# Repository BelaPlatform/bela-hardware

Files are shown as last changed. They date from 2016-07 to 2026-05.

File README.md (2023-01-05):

# Bela Hardware

This repo contains the editable hardware design files for Bela products, including Bela, Bela Mini, Bela accessories.

These PCB designs have been created in and are editable with Cadsoft EAGLE (https://cadsoft.io) and Kicad (http://kicad.org). 

## Licensing

The hardware designs in this repo are licensed under a Creative Commons Attribution Sharealike license, or [CC-BY-SA](http://creativecommons.org/licenses/by-sa/3.0/). This means you are free edit and use these designs, as long as you agree to supply credit and release your results under the same license. [Read about CC-BY-SA here](http://creativecommons.org/licenses/by-sa/3.0/).

If you want to create a commercial product using the Bela hardware designs and don't want to release it under the same license, you will need a commercial license. Drop us an email at info@bela.io to discuss your project, and we can suggest a commercial license to fit your project's scope and scale.

## Branding

The Bela logo is copyrighted, and is reserved for products made or licensed by the Bela team. If you want to include a Bela logo on your project, we've made a Made With Bela logo just for this. [See this page for details on logo use](https://belaplatform.github.io/bela_sample/src/#logos) and to download the Made With Bela logo.

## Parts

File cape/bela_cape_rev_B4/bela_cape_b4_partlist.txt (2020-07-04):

Partlist

Exported from bela_cape.brd at 09/12/2019 12:21

EAGLE Version 6.5.0 Copyright (c) 1988-2013 CadSoft

Assembly variant: 

Part     Value                   Package              Library             Position (inch)       Orientation

C1       0.1uF                   C0603                rcl                 (1.03 -1.71)          R0
C2       10uF                    0603-CAP             SparkFun-Passives   (0.53 -1.77)          R90
C3       10uF                    0603-CAP             SparkFun-Passives   (1.05 -1.59)          R0
C4       0.1uF                   C0603                rcl                 (1.05 -1.53)          R0
C5       0.1uF                   C0603                rcl                 (0.49 -1.4)           R0
C6       0.1uF                   C0603                rcl                 (0.49 -1.48)          R0
C7       0.1uF                   C0603                rcl                 (1.27 -1.32)          R90
C8       0.1uF                   C0603                rcl                 (0.125 -1.765)        R270
C9       0.1uF                   C0603                rcl                 (1.28 -1.9)           R90
C10      0.1uF                   C0603                rcl                 (0.445 -1.77)         R270
C11      0.1uF                   C0603                rcl                 (1.88 -1.28)          R180
C12      1uF                     C0603                rcl                 (1.88 -1.41)          R0
C14      47uF                    EIA3216              SparkFun-Capacitors (2.11 -1.005)         R180
C15      0.1uF                   C0603                rcl                 (2.11 -1.11)          R0
C16      47uf                    EIA3216              SparkFun-Capacitors (1.93 -2.27500209)    R180
C17      47uf                    EIA3216              SparkFun-Capacitors (1.93 -2.16136602)    R180
C20      0.1uf                   C0603                rcl                 (1.72 -2.44)          R0
C21      0.1uf                   C0603                rcl                 (1.72 -2.28)          R0
C22      0.1uf                   C0603                rcl                 (1.15 -2.35)          R180
C23      0.1uf                   C0603                rcl                 (1.15 -2.25)          R180
C24      10uf,10V                0603-CAP             SparkFun-Passives   (1.72 -2.53)          R180
C25      10uf,10V                0603-CAP             SparkFun-Passives   (1.72 -2.36)          R180
C26      10uf,10V                0603-CAP             SparkFun-Passives   (1.15 -2.43)          R0
C27      10uf,10V                0603-CAP             SparkFun-Passives   (1.15 -2.17)          R0
C28      1uF                     C0603                rcl                 (2.04452817 -2.58090391) R180
C29      1uF                     C0603                rcl                 (2.04271001 -2.43091191) R0
C30      47pF                    C0603                rcl                 (2.17589186 -2.58090404) R0
C31      47pF                    C0603                rcl                 (2.04368602 -2.50495792) R0
C32      1uf                     C0603                rcl                 (0.105 -2.53)         R180
C33      .01uf                   C0603                rcl                 (0.1 -2.235)          R180
C34      2.2uf                   C0603                rcl                 (0.005 -2.37)         R270
C35      0.1uF                   C0603                rcl                 (0.844 -1.845)        R0
C36      0.1uF                   C0603                rcl                 (2.005 -1.57)         R90
C38      1uF                     C0603                rcl                 (2.005 -1.985)        R90
C39      47uF                    EIA3216              SparkFun-Capacitors (2.195 -1.57)         R90
C40      0.1uF                   C0603                rcl                 (2.085 -1.57)         R270
D1       PGB0010603MR            0603                 CircuitCo           (2.22 -2.175)         R90
D2       PGB0010603MR            0603                 CircuitCo           (2.22 -2.305)         R270
D3       BAS70-04                SOT23                diode               (1.87799409 -2.54519993) R90
D4       BAS70-04                SOT23                diode               (1.87799409 -2.4088499) R90
FB1      FB                      0603                 SparkFun-Passives   (1.7 -2.15)           R180
FB2      FB                      0603                 SparkFun-Passives   (1.41 -2.5163659)     R180
FB3      FB                      0603                 SparkFun-Passives   (0.13 -2.05)          R270
FB4      FB                      0603                 SparkFun-Passives   (0.265 -2.415)        R90
IC1      ADD8704RU               TSSOP14              analog-devices      (1.12 -1.89)          R90
IC2      ADD8704RU               TSSOP14              analog-devices      (1.12 -1.32)          R90
IC3      AD5668                  TSSOP16-PW           custom              (0.27 -1.46)          R90
IC4      AD7699                  LFCSP20-LEADS        custom              (0.87 -1.57)          R180
IC5                              TSSOP14              SparkFun-DigitalIC  (0.28 -1.77)          R0
IC6      TLV320AIC3104           QFN-32               CircuitCo           (1.46 -2.34)          R270
IC7      V_REG_LDOSMD            SOT23-5              SparkFun-PowerIC    (0.105 -2.37)         R0
IC8      LM4876                  SO8                  custom              (2.11 -1.26)          R270
IC9      LM4876                  SO8                  custom              (2.11 -1.8)           R270
J1       22-23-2021              22-23-2021           con-molex           (0.425 -2.41)         R0
J2       22-23-2041              22-23-2041           con-molex           (0.88 -2.41)          R0
J3       22-23-2031              22-23-2031           con-molex           (2.42 -2.31)          R90
J4       22-23-2031              22-23-2031           con-molex           (2.42 -1.91)          R90
J5       22-23-2021              22-23-2021           con-molex           (2.42 -1.51)          R90
J6       22-23-2021              22-23-2021           con-molex           (2.42 -1.21)          R90
J7                               1X10                 pinhead             (1.54 -1.525)         R90
J8                               1X10                 pinhead             (0.39 -1.075)         R180
J9                               1X04                 SparkFun-Connectors (1.74 -1.675)         R270
J10                              1X04                 SparkFun-Connectors (1.84 -1.675)         R270
R1       0                       R0603                rcl                 (0.49 -1.64)          R0
R2       0                       R0603                rcl                 (0.07 -1.54)          R90
R3       DNI                     R0603                rcl                 (0.07 -1.42)          R270
R4       0                       R0603                rcl                 (0.74 -1.45)          R0
R5       DNI                     R0603                rcl                 (0.49 -1.56)          R180
R6       0                       R0603                rcl                 (1.40872281 -2.59002178) R180
R7       43k                     R0603                rcl                 (2.18 -1.41)          R180
R8       22k                     R0603                rcl                 (2.03 -1.41)          R180
R9       100                     R0603                rcl                 (0.05 -1.25)          R0
R10      22k                     R0603                rcl                 (1.88 -1.19)          R180
R11      15                      R0603                rcl                 (2.07 -2.305)         R90
R12      15                      R0603                rcl                 (2.07 -2.175)         R270
R13      22k                     R0603                rcl                 (2.085 -1.985)        R270
R14      43k                     R0603                rcl                 (2.17 -1.985)         R270
R15      3.3k                    R0603                rcl                 (2.14523991 -2.30340613) R270
R16      3.3k                    R0603                rcl                 (2.14524016 -2.17432788) R90
R17      220                     R0603                rcl                 (2.17614592 -2.50520386) R180
R18      220                     R0603                rcl                 (2.17614579 -2.43066622) R180
R21      2.2k                    R0603                rcl                 (0.85 -2.25)          R0
R22      2.2k                    R0603                rcl                 (0.98 -2.25)          R180
RN1      22                      0603-ARC             resistor-dil        (0.27 -1.97)          R0
RN2      22                      0603-ARC             resistor-dil        (0.72 -1.72)          R180
RN3      220                     0603-ARC             resistor-dil        (1.375 -1.79)         R270
RN4      220                     0603-ARC             resistor-dil        (1.37 -1.35)          R270
RN5      220                     0603-ARC             resistor-dil        (0.34 -1.26)          R0
RN6      220                     0603-ARC             resistor-dil        (0.19 -1.26)          R0
S1       SWITCH-MOMENTARY-2SMD-5 TACTILE_SWITCH_SMD-4 custom              (2.38315994 -2.55585212) R180
TP1                              1X01                 pinhead             (1.24 -1.575)         R0
TP2                              1X01                 pinhead             (1.56 -2.525)         R0
U$1      BEAGLEBONE_OUTLINE      BEAGLEBONE_SHIELD    adafruit            (-0.81 -0.7)          R270

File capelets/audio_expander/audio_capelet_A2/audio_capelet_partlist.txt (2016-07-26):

Partlist

Exported from audio_capelet_a1.brd at 24/05/2016 19:19

EAGLE Version 6.5.0 Copyright (c) 1988-2013 CadSoft

Assembly variant: 

Part     Value            Package      Library        Position (inch)       Orientation

C1       1uF              C0603        resistor       (0.96 0.4)            R180
C2       330pF            C0603        resistor       (1.16 0.43)           R0
C3       330pF            C0603        resistor       (1.26 0.52)           R270
C4       1uF              C0603        resistor       (1.17 0.92)           R0
C5       330pF            C0603        resistor       (0.97 0.86)           R180
C6       330pF            C0603        resistor       (0.88 1.02)           R0
C7       1uF              C0603        resistor       (1.52 0.51)           R180
C8       330pF            C0603        resistor       (1.66 0.37)           R270
C9       330pF            C0603        resistor       (1.79 0.51)           R270
C10      1uF              C0603        resistor       (1.68 1.1)            R0
C11      330pF            C0603        resistor       (1.52 1.16)           R180
C12      330pF            C0603        resistor       (1.43 1.02)           R0
C13      1uF              C0603        resistor       (1.73 0.46)           MR180
C14      330pF            C0603        resistor       (1.62 0.33)           MR270
C15      330pF            C0603        resistor       (1.49 0.49)           MR270
C16      1uF              C0603        resistor       (1.61 1.1)            MR0
C17      330pF            C0603        resistor       (1.72 1.26)           MR90
C18      300pF            C0603        resistor       (1.85 1.11)           MR90
C19      1uF              C0603        resistor       (0.71 0.38)           MR270
C20      330pF            C0603        resistor       (0.62 0.32)           MR270
C21      330pF            C0603        resistor       (0.5 0.42)            MR270
C22      1uF              C0603        resistor       (0.63 1.06)           MR90
C23      330pF            C0603        resistor       (0.7 1.07)            MR90
C24      330pF            C0603        resistor       (0.88 0.98)           MR0
C25      1uF              C0603        resistor       (0.84 1.63)           MR270
C26      220pF            C0603        resistor       (0.91 1.51)           MR90
C27      440pF            C0603        resistor       (0.93 1.61)           MR180
C28      220pF            C0603        resistor       (0.91 1.36)           MR270
C29      440pF            C0603        resistor       (0.93 1.27)           MR180
C30      1uF              C0603        resistor       (0.84 1.26)           MR90
C31      220pF            C0603        resistor       (0.44 1.37)           MR270
C32      440pF            C0603        resistor       (0.42 1.27)           MR0
C33      1uF              C0603        resistor       (0.51 1.26)           MR90
C34      220pF            C0603        resistor       (0.44 1.51)           MR90
C35      440pF            C0603        resistor       (0.42 1.6)            MR0
C36      1uF              C0603        resistor       (0.51 1.63)           MR270
C37      220pF            C0603        resistor       (0.43 1.52)           R90
C38      440pF            C0603        resistor       (0.42 1.61)           R180
C39      1uF              C0603        resistor       (0.51 1.63)           R270
C40      220pF            C0603        resistor       (0.43 1.37)           R270
C41      440pF            C0603        resistor       (0.42 1.27)           R180
C42      1uF              C0603        resistor       (0.51 1.25)           R90
C43      220pF            C0603        resistor       (0.91 1.36)           R270
C44      440pF            C0603        resistor       (0.93 1.26)           R0
C45      1uF              C0603        resistor       (0.84 1.26)           R90
C46      220pF            C0603        resistor       (0.91 1.51)           R90
C47      440pF            C0603        resistor       (0.92 1.6)            R0
C48      1uF              C0603        resistor       (0.83 1.63)           R270
C49      1uF              C0603        resistor       (0.55 0.59)           R180
C50      1uF              C0603        resistor       (0.64 0.48)           R90
C51      0.1uF            C0603        resistor       (0.85 0.67)           R270
C52      0.1uF            C0603        resistor       (1.41 0.79)           R270
C53      0.1uF            C0603        resistor       (1.48 0.79)           MR270
C54      0.1uF            C0603        resistor       (0.86 0.72)           MR270
C55      0.1uF            C0603        resistor       (0.67 1.63)           MR180
C56      0.1uF            C0603        resistor       (0.67 1.29)           R180
C57      0.1uF            C0603        resistor       (1.17 0.67)           R270
C58      0.1uF            C0603        resistor       (1.79 0.79)           R270
C59      0.1uF            C0603        resistor       (1.84 0.78)           MR270
C60      0.1uF            C0603        resistor       (0.49 0.74)           MR270
C61      0.1uF            C0603        resistor       (0.67 1.29)           MR180
C62      0.1uF            C0603        resistor       (0.67 1.61)           R180
IC1      ADD8704RU        TSSOP14      analog-devices (1.03 0.67)           R90
IC2      ADD8704RU        TSSOP14      analog-devices (1.59 0.79)           R90
IC3      ADD8704RU        TSSOP14      analog-devices (1.67 0.78)           MR90
IC4      ADD8704RU        TSSOP14      analog-devices (0.67 0.73)           MR90
IC5      ADD8704RU        TSSOP14      analog-devices (0.67 1.44)           MR0
IC6      ADD8704RU        TSSOP14      analog-devices (0.67 1.44)           R0
IC7      LP5907-1.8       SOT23-5      PDue           (0.54 0.48)           R180
J1       22-23-2031       22-23-2031   con-molex      (1.28 2.3)            R180
J2       22-23-2031       22-23-2031   con-molex      (1.68 2.3)            R180
J3       22-23-2031       22-23-2031   con-molex      (1.28 2.02)           R180
J4       22-23-2031       22-23-2031   con-molex      (1.68 2.02)           R180
J5       22-23-2031       22-23-2031   con-molex      (0.48 2.3)            R180
J6       22-23-2031       22-23-2031   con-molex      (0.88 2.3)            R180
J7       22-23-2031       22-23-2031   con-molex      (0.48 2.02)           R180
J8       22-23-2031       22-23-2031   con-molex      (0.88 2.02)           R180
J9       see BOM
J10      see BOM
J11	 see BOM
J12	 see BOM
R1       30k              R0603        resistor       (0.85 0.52)           R90
R2       3.3k             R0603        resistor       (1.15 1.63)           R270
R3       100k             R0603        resistor       (0.96 0.47)           R0
R4       27.4k            R0603        resistor       (1.06 0.33)           R90
R5       27.4k            R0603        resistor       (1.06 0.45)           R90
R6       16.2k            R0603        resistor       (1.18 0.52)           R90
R7       27.4k            R0603        resistor       (1.26 0.64)           R270
R8       30k              R0603        resistor       (1.17 0.82)           R270
R9       3.3k             R0603        resistor       (1.25 1.63)           R270
R10      100k             R0603        resistor       (1.07 0.9)            R270
R11      27.4k            R0603        resistor       (1 1.02)              R180
R12      27.4k            R0603        resistor       (0.97 0.96)           R0
R13      16.2k            R0603        resistor       (0.85 0.83)           R270
R14      27.4k            R0603        resistor       (0.83 0.93)           R180
R15      30k              R0603        resistor       (1.41 0.65)           R90
R16      3.3k             R0603        resistor       (1.35 1.63)           R270
R17      100k             R0603        resistor       (1.52 0.57)           R0
R18      27.4k            R0603        resistor       (1.59 0.28)           R0
R19      27.4k            R0603        resistor       (1.69 0.46)           R180
R20      16.2k            R0603        resistor       (1.69 0.53)           R0
R21      27.4k            R0603        resistor       (1.8 0.64)            R270
R22      30k              R0603        resistor       (1.79 0.93)           R270
R23      3.3k             R0603        resistor       (1.45 1.63)           R270
R24      100k             R0603        resistor       (1.68 1.04)           R180
R25      27.4k            R0603        resistor       (1.68 1.23)           R180
R26      27.4k            R0603        resistor       (1.52 1.09)           R0
R27      16.2k            R0603        resistor       (1.41 0.92)           R90
R28      27.4k            R0603        resistor       (1.41 1.13)           R270
R29      30k              R0603        resistor       (1.84 0.63)           MR90
R30      3.3k             R0603        resistor       (1.55 1.63)           R270
R31      100k             R0603        resistor       (1.73 0.53)           MR0
R32      27.4k            R0603        resistor       (1.73 0.29)           MR0
R33      27.4k            R0603        resistor       (1.57 0.42)           MR180
R34      16.2k            R0603        resistor       (1.57 0.53)           MR0
R35      27.4k            R0603        resistor       (1.48 0.62)           MR270
R36      30k              R0603        resistor       (1.48 0.93)           MR270
R37      3.3k             R0603        resistor       (1.65 1.63)           R270
R38      100k             R0603        resistor       (1.61 1.03)           MR180
R39      27.4k            R0603        resistor       (1.38 0.9)            MR0
R40      27.4k            R0603        resistor       (1.76 1.17)           MR0
R41      16.2k            R0603        resistor       (1.77 1.04)           MR180
R42      27.4k            R0603        resistor       (1.85 0.94)           MR90
R43      30k              R0603        resistor       (0.81 0.58)           MR90
R44      3.3k             R0603        resistor       (1.75 1.63)           R270
R45      100k             R0603        resistor       (0.74 0.47)           MR0
R46      27.4k            R0603        resistor       (0.88 0.51)           MR270
R47      27.4k            R0603        resistor       (0.59 0.42)           MR180
R48      16.2k            R0603        resistor       (0.59 0.49)           MR0
R49      27.4k            R0603        resistor       (0.5 0.54)            MR270
R50      30k              R0603        resistor       (0.49 0.86)           MR90
R51      3.3k             R0603        resistor       (1.85 1.63)           R270
R52      100k             R0603        resistor       (0.6 0.97)            MR180
R53      27.4k            R0603        resistor       (0.49 0.98)           MR90
R54      27.4k            R0603        resistor       (0.73 0.98)           MR0
R55      16.2k            R0603        resistor       (0.86 0.88)           MR270
R56      27.4k            R0603        resistor       (0.95 0.84)           MR0
R57      28.7k            R0603        resistor       (1.03 1.25)           MR90
R58      28.7k            R0603        resistor       (0.98 1.36)           MR90
R59      28.7k            R0603        resistor       (0.33 1.26)           MR90
R60      28.7k            R0603        resistor       (1.03 1.63)           MR270
R61      28.7k            R0603        resistor       (0.98 1.51)           MR270
R62      28.7k            R0603        resistor       (0.37 1.37)           MR90
R63      28.7k            R0603        resistor       (0.33 1.62)           MR270
R64      28.7k            R0603        resistor       (0.37 1.51)           MR270
R65      28.7k            R0603        resistor       (0.33 1.63)           R270
R66      28.7k            R0603        resistor       (0.36 1.52)           R270
R67      28.7k            R0603        resistor       (0.33 1.25)           R90
R68      28.7k            R0603        resistor       (0.36 1.36)           R90
R69      28.7k            R0603        resistor       (1.02 1.24)           R90
R70      28.7k            R0603        resistor       (0.98 1.35)           R90
R71      28.7k            R0603        resistor       (1.01 1.63)           R270
R72      28.7k            R0603        resistor       (0.98 1.52)           R270

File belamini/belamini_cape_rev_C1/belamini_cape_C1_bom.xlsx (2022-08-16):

Name | Quantity | Value | Side | Package | Description | Farnell # | Mouser # | Datasheet / Notes
 |  |  |  |  |  |  | 810-C1608X5R1A106M
C2, C18, C19, C20, C21 | 5 | 10uF | bottom | “0603” | Capacitor ceramic 0603 | 2309028
C3, C7, C14, C15, C22, C23, C24 | 7 | 1uF | bottom | “0603” | Capacitor ceramic 0603 | 2496916 | 77-VJ0603V105MXQPBC
C1, C4, C5, C6, C16, C17 | 6 | 0.1uF | bottom | “0603” | Capacitor ceramic 0603 | 1709957 | 80-C0603C104K5R
C12, C13 | 2 | 47pF | bottom | "0603" | Capacitor ceramic 0603 | 1759062 | 77-VJ0603A470JXACBC
C8, C9 | 2 | 47uF | bottom | "1206" | Capacitor electrolytic 1206 | 2353044 | 647-F930J476MAA
C10, C11 | 2 | 1.2nF NPO/C0G | bottom | "0603" | Capacitor ceramic 0603 NPO/C0G
D1, D2 | 2 | TE Connectivity PESD0603-240 | bottom | "0603" | ESD suppressor 24V |  | 650-PESD0603-240
D3, D4 | 2 | BAS70-04 | bottom | SOT23-3 | Dual Schottky diode |  | 863-BAS70-04LT1G |  | D3, D4
D5 | 1 | Lite-On LTST-C195TBJRKT | top | “0606” | blue/red LED |  | 859-LTST-C195TBJRKT | Important: check pinout of any generic equivalent part. Dot indicates the negative side (cathode).
FB1, FB2 | 4 | Ferrite bead | bottom | “0603” | Ferrite bead 0603 | 1781090 | 810-MPZ1608S121A
IC1, IC2 | 2 | TSV524 | bottom | QFN-16 | Quad op-amp |  | 511-TSV524IQ4T
IC3 | 1 | ADS8168IRHBT | bottom | QFN-32 | 16-bit ADC |  | 595-ADS8168IRHBT | Other parts in ADS816x series may also work.
IC4 | 1 | TLV320AIC3104 | bottom | QFN-32 | Audio codec |  | 595-TLV320C3104IRHBR
IC5 | 1 | MIC5317-1.8Y | bottom | SOT23-5 | 1.8V regulator |  | 998-MIC5317-1.8YM5TR
IC6 | 1 | USBLC6-2SC6 | bottom | SOT23-6 | ESD suppressor for USB |  | 511-USBLC6-2SC6
J1 | 1 | 10-pin socket | top | Through Hole | 10-pin socket |  | 992-10FX1-254MM
J2 | 1 | 3-pin header | top | Through Hole | 3-pin socket |  | 855-M20-7820346
J3, J4 | 2 | Molex 3-pin | top | Through Hole | 3-pin Molex KK series connector |  | 538-22-23-2031
J5 | 1 | Amphenol 87583-3010RPALF | top | Solder Pad | USB A socket, solder pad | 1314363 | 649-87583-3010RPALF
P1, P2 | 2 | 36-pin header | top | Through Hole | 2x18 2.54mm stacking headers (10mm male pins on bottom, female sockets on top). |  |  | Important: use 10mm pin length rather than 12.5mm used on previous Bela builds
R1, R2 | 2 | 15 ohm | bottom | “0603” | Resistor 0603
R3 | 1 | 100 ohm | bottom | “0603” | Resistor 0603
R4, R5 | 2 | 560 ohm | bottom | “0603” | Resistor 0603
R6, R7 | 2 | 3.3k ohm | bottom | “0603” | Resistor 0603
R8, R9 | 2 | 220 ohm | bottom | “0603” | Resistor 0603
R10, R11, R14 | 3 | 10k ohm | bottom | “0603” | Resistor 0603
R12, R13 | 2 | 49.9 ohm 1% | bottom | “0603” | Resistor 0603
RN1 | 1 | 22 ohm 4x network | bottom | “0603” | Resistor network 4x0603 | 2060086
S1 | 1 | C&K Components PTS810 SJG 250 SMTR LFS | top | SMD | Micro tactile switch |  | 611-PTS810SJG250SMTR
Total | 62
BOM rev. C1

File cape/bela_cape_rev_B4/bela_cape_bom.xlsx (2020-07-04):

Name | Quantity | Value | Package | Description | Farnell # | Mouser # | Datasheet / Notes
 |  |  |  |  |  | 810-C1608X5R1A106M
C2-C3, C24-C27, C34 | 7 | 10uF | “0603” | Capacitor ceramic 0603 | 2309028
C12, C13, C28, C29, C32, C38 | 6 | 1uF | “0603” | Capacitor ceramic 0603 | 1710292 | 77-VJ0603V105MXQPBC
C1, C4-C11, C15, C20-C23, C35-C36, C40 | 17 | 0.1uF | “0603” | Capacitor ceramic 0603 | 1709957 | 80-C0603C104K5R
C30-C31 | 2 | 47pF | "0603" | Capacitor ceramic 0603 |  | 77-VJ0603A470JXACBC
C14, C16, C17, C39 | 4 | 47uF | "1206" | Capacitor electrolytic 1206 |  | 647-F930J476MAA
C33 | DNI
D1, D2 | 2 | TE Connectivity PESD0603-240 | "0603" | ESD suppressor 24V |  | 650-PESD0603-240
D3, D4 | 2 | BAS70-04 | SOT23-3 | Dual Schottky diode |  | 863-BAS70-04LT1G
FB1-FB4 | 4 | Ferrite bead | “0603” | Ferrite bead 0603 | 1781090 | 810-MPZ1608S121A
IC1-IC2 | 2 | OPA4348AIPWR | TSSOP-14 | Quad rail-to-rail op amp | 2323319
IC3 | 1 | AD5668 | TSSOP-16 | 16-bit DAC |  | 584-AD5668ARUZ-2
IC4 | 1 | AD7699 | LFCSP-20 | 16-bit ADC |  | 584-AD7699BCPZ
IC5 | 1 | TXB0104PWR | TSSOP-14 | Level shifter | 1607891
IC6 | 1 | TLV320AIC3104 | QFN-32 | Audio codec |  | 595-TLV320C3104IRHBR
IC7 | 1 | MIC5317 | SOT23-5 | 1.8V regulator |  | 998-MIC5317-1.8YM5TR
IC8-IC9 | 2 | LM4876 | SOIC-8 | Audio power amp |  | 926-LM4876M/NOPB
J1 | DNI | Molex 2-pin | Through Hole | 2-pin Molex KK series connector |  | 538-22-23-2025
J3, J4 | 2 | Molex 3-pin | Through Hole | 3-pin Molex KK series connector |  | 538-22-23-2031
J2 | 1 | Molex 4-pin | Through Hole | 4-pin Molex KK series connector |  | 538-22-23-2041
J5-J6 | 1 | Molex 2-pin | Through Hole | 2-pin Molex KK series connector |  | 538-22-23-2025
J7-J8 | 2 | 10-pin socket | Through Hole | 10-pin socket |  | 992-10FX1-254MM
J9-J10 | DNI
P8, P9 | 2 | Adafruit 706 (or similar) | Through Hole | 46-pin long-lead female sockets for BeagleBone |  |  | http://www.adafruit.com/product/706
R1-R2, R4 | 3 | 0 ohm | “0603” | Resistor 0603
R3, R5 | DNI
R7, R14 | 2 | 43k ohm | “0603” | Resistor 0603
R8, R10, R13 | 3 | 22k ohm | “0603” | Resistor 0603
R6, R9 | 2 | 100 ohm | “0603” | Resistor 0603
R11, R12 | 2 | 15 ohm | “0603” | Resistor 0603
R15, R16 | 2 | 3.3k ohm | “0603” | Resistor 0603
R17, R18 | 2 | 220 ohm | “0603” | Resistor 0603
R21, R22 | 2 | 2.2k ohm | “0603” | Resistor 0603
RN1-RN2 | 2 | 22 ohm 4x network | “0603” | Resistor network 4x0603 | 2060086
RN3-RN6 | 4 | 220 ohm 4x network | "0603" | Resistor network 4x0603 | 2060094
SW1 | 1 | C&K Components PTS810 SJG 250 SMTR LFS | SMD | Micro tactile switch |  | 611-PTS810SJG250SMTR
Total | 86 |  |  | Bela rev. B3

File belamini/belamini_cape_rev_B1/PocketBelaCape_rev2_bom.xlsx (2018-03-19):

Name | Quantity | Value | Side | Package | Description | Farnell # | Mouser # | Datasheet / Notes
 |  |  |  |  |  |  | 810-C1608X5R1A106M
C2, C3, C18, C19 | 4 | 10uF | bottom | “0603” | Capacitor ceramic 0603 | 2309028
C7, C14, C15 | 3 | 1uF | bottom | “0603” | Capacitor ceramic 0603 | 2496916 | 77-VJ0603V105MXQPBC
C1, C4, C5, C6, C16, C17 | 6 | 0.1uF | bottom | “0603” | Capacitor ceramic 0603 | 1709957 | 80-C0603C104K5R
C10, C11, C12, C13 | 4 | 47pF | bottom | "0603" | Capacitor ceramic 0603 | 1759062 | 77-VJ0603A470JXACBC
C8, C9 | 2 | 47uF | bottom | "1206" | Capacitor electrolytic 1206 | 2353044 | 647-F930J476MAA
D1, D2, D3, D4 | 4 | TE Connectivity PESD0603-240 | bottom | "0603" | ESD suppressor 24V |  | 650-PESD0603-240
D5 | 1 | Lite-On LTST-C195TBJRKT | top | “0606” | blue/red LED |  | 859-LTST-C195TBJRKT
FB1, FB2 | 4 | Ferrite bead | bottom | “0603” | Ferrite bead 0603 | 1781090 | 810-MPZ1608S121A
IC1, IC2 | 2 | TSV524 | bottom | QFN-16 | Quad op-amp |  | 511-TSV524IQ4T
IC3 | 1 | AD7699 | bottom | LFCSP-20 | 16-bit ADC |  | 584-AD7699BCPZ
IC4 | 1 | TLV320AIC3104 | bottom | QFN-32 | Audio codec |  | 595-TLV320C3104IRHBR
IC5 | 1 | MIC5317 | bottom | SOT23-5 | 1.8V regulator |  | 998-MIC5317-1.8YM5TR
J1 | 1 | 10-pin socket | top | Through Hole | 10-pin socket |  | 992-10FX1-254MM
J2 | 1 | 3-pin header | top | Through Hole | 3-pin socket |  | 855-M20-7820346
J3, J4 | 2 | Molex 3-pin | top | Through Hole | 3-pin Molex KK series connector |  | 538-22-23-2031
J5 | 1 | Amphenol 87583-3010RPALF | top | Solder Pad | USB A socket, solder pad | 1314363 | 649-87583-3010RPALF
P1, P2 | 2 | 36-pin header | top | Through Hole | 2x18 2.54mm stacking headers (long male pins on bottom, female sockets on top) |  |  | similar to headers used on bela_cape but 36 pins rather than 46 pins
R1, R2 | 2 | 33 ohm | bottom | “0603” | Resistor 0603
R3 | 1 | 100 ohm | bottom | “0603” | Resistor 0603
R4, R5 | 2 | 560 ohm | bottom | “0603” | Resistor 0603
RN1 | 1 | 22 ohm 4x network | bottom | “0603” | Resistor network 4x0603 | 2060086
S1 | 1 | C&K Components PTS810 SJG 250 SMTR LFS | top | SMD | Micro tactile switch |  | 611-PTS810SJG250SMTR
Total | 47
BOM rev. B1

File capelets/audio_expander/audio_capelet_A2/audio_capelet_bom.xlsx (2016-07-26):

Name | Quantity | Value | Package | Description | Farnell # | Mouser # | Datasheet / Notes
C1, C4, C7, C10, C13, C16, C19, C22, C25, C30, C33, C36, C39, C42, C45, C48, C49, C50 | 18 | 1uF | “0603” | Capacitor ceramic 0603
C51-C62 | 12 | 0.1uF | “0603” | Capacitor ceramic 0603 | 1709957 | 80-C0603C104K5R
C2, C3, C5, C6, C8, C9, C11, C12, C14, C15, C17, C18, C20, C21, C23, C24 | 16 | 330pF | “0603” | Capacitor ceramic 0603, 5% or better tolerance
C26, C28, C31, C34, C37, C40, C43, C46 | 8 | 220pF | “0603” | Capacitor ceramic 0603, 5% or better tolerance
C27, C29, C32, C35, C38, C41, C44, C47 | 8 | 430pF | “0603” | Capacitor ceramic 0603, 5% or better tolerance
IC1-IC6 | 6 | OPA4348AIPWR | TSSOP-14 | Quad rail-to-rail op amp
IC7 | 1 | LP5907-MFX2.0 (or -MFX1.8) | SOT23-5 | Voltage regulator. 2.0V version is preferred but if it cannot be found, use LP5907-MFX1.8 |  | 595-LP5907MFX-1.8NPB
J1-J8 | 8 | Molex 3-pin | Through Hole | 3-pin Molex KK series connector |  | 538-22-23-2031
J9-J10 | 2 | 10-pin socket | Through Hole | 10-pin socket with long tail leads, similar to P8/P9
J11 | 1 | 8-pin socket | Through Hole | 8-pin socket — SAME HEIGHT AS J10 — does not need long leads, but if needed to match the height, use a long-lead socket and clip the leads off
J12 | 1 | 2x8 pin socket | Through Hole | 16-pin (2 row) female socket, 0.1” spacing
P8, P9 | 2 | Adafruit 706 (or similar) | Through Hole | 46-pin long-lead female sockets for BeagleBone |  |  | http://www.adafruit.com/product/706
R1, R8, R15, R22, R29, R36, R43, R50 | 8 | 30k ohm | “0603” | Resistor 0603 - 2% or better tolerance
R2, R9, R16, R23, R30, R37, R44, R51 | 8 | 3.3k ohm | “0603” | Resistor 0603 - 2% or better tolerance
R4, R5, R7, R11, R12, R14, R18, R19, R21, R25, R26, R28, R32, R33, R35, R39, R40, R42, R46, R47, R49, R53, R54, R56 | 24 | 27.4k ohm | “0603” | Resistor 0603 - 2% or better tolerance
R3, R10, R17, R24, R31, R38, R45, R52 | 8 | 100k ohm | “0603” | Resistor 0603
R6, R13, R20, R27, R34, R41, R48, R55 | 8 | 16.2k ohm | “0603” | Resistor 0603 - 2% or better tolerance
R57-R72 | 16 | 28.7k ohm | “0603” | Resistor 0603 - 2% or better tolerance
Total | 155 |  |  | Audio Expander Capelet rev. A2

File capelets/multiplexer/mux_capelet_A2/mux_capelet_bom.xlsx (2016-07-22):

Name | Quantity | Value | Package | Description | Farnell # | Mouser # | Datasheet / Notes
C1-C4 | 4 | 0.1uF | “0603” | Capacitor ceramic 0603 | 1709957 | 80-C0603C104K5R
IC1-IC8 | 8 | 74HCT4051 | TSSOP-16 | 8-channel multiplexer; note: any manufacturer is okay, but must be 74HCT type (not 74HC, CD4051 etc.) |  | 771-74HCT4051PW-T
J1, J2, J5, J6 | 4 | 34-pin IDC socket | Through Hole | 34-pin IDC socket vertical |  | 517-30334-6002
J3, J4 | 2 | 2-pin 0.1” header | Through Hole | 2-pin header
J7-J8 | 2 | 10-pin socket | Through Hole | 10-pin socket with long tail leads, similar to P8/P9
J9-J12 | 4 | 17-pin 0.1” header | Through Hole — BOTTOM side | 17-pin header installed facing downward
P8, P9 | 2 | Adafruit 706 (or similar) | Through Hole | 46-pin long-lead female sockets for BeagleBone |  |  | http://www.adafruit.com/product/706
R1-R2 | 2 | 22k ohm | “0603” | Resistor 0603
R3-R10 | DNI
R11 | 1 | 0 ohm | “0603” | Resistor 0603
Total | 29 |  |  | Multiplexer Capelet rev. A2

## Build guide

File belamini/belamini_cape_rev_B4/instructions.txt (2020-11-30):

Part: belamini_cape, revision B4
--------------------------------

Audio and sensor cape for PocketBeagle, featuring stereo audio codec, 8 channel 16-bit ADC and USB port. Designed for the Bela ultra-low-latency audio environment.

http://bela.io

(c) 2020 Augmented Instruments Ltd 
London, United Kingdom

info@bela.io

-------------------------

Suggested build specifications:

2 layers
1.6mm board thickness
black soldermask
white silkscreen, both sides
standard finish
7 mil minimum feature size
15 mil minimum drill
Tab routing / milling (for panelising)
Double-sided SMT assembly

-------------------------

Package contents:

*** EAGLE Design Files:

belamini_cape_B4.sch	EAGLE schematic
belamini_cape_B4.brd	EAGLE board

*** Gerbers (RS274X unless otherwise noted):

belamini_cape_B4.cmp	Component Side (top) copper
belamini_cape_B4.sol	Solder Side (bottom) copper
belamini_cape_B4.stc	Component side (top) stop mask
belamini_cape_B4.sts	Solder side (bottom) stop mask
belamini_cape_B4.plc	Component side (top) silkscreen
belamini_cape_B4.pls	Solder side (bottom) silkscreen
belamini_cape_B4.dim	Outline dimension
belamini_cape_B4.drd	NC Drill (Excellon format)
belamini_cape_B4.crc	Component side (top) paste
belamini_cape_B4.crs	Solder side (bottom) paste

*** Assembly files:

belamini_cape_B4_centroid.csv	XYRS placement data
belamini_cape_B4_bom.xls	Bill of materials

-------------------------

This design is available under the Creative Commons Attribution-ShareAlike 3.0 Unported License:

http://creativecommons.org/licenses/by-sa/3.0/

-------------------------

Revision History:

A1 			Internal build.
B1 			Internal build. Flip components to solder side.
B2 (March 2018)		First public release. Add ESD protection to USB port
			and ground USB ID bit. Changes to silkscreen.
B3 (May 2019)		Add R6 and R7 to reduce noise on audio output when
			codec is not active.
B4 (November 2020)	Change input protection circuitry (D3, D4, R8, R9).
			Change headphone output resistors R1, R2 to 15 ohms.
			Add I2C pullup resistors R10, R11.

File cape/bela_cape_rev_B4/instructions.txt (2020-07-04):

Part: bela_cape, revision B4
--------------------------------

Audio and sensor cape for BeagleBone Black, featuring stereo audio codec, 8 channel 16-bit ADC, 8 channel 16-bit DAC and 2x 1.1W speaker amplifiers. Designed for the Bela ultra-low-latency audio environment.

http://bela.io

(c) 2019 Andrew McPherson 
Augmented Instruments Ltd
327 Mile End Road
London E1 4NS
United Kingdom

a.mcpherson@qmul.ac.uk

-------------------------

Suggested build specifications:

2 layers
1.6mm board thickness
black soldermask
white silkscreen, top side
standard finish
7 mil minimum feature size
15 mil minimum drill
Tab routing / milling (for panelising)

-------------------------

Package contents:

*** EAGLE Design Files:

bela_cape.sch	EAGLE schematic
bela_cape.brd	EAGLE board

*** Gerbers (RS274X unless otherwise noted):

bela_cape.cmp	Component Side (top) copper
bela_cape.sol	Solder Side (bottom) copper
bela_cape.stc	Component side (top) stop mask
bela_cape.sts	Solder side (bottom) stop mask
bela_cape.plc	Component side (top) silkscreen
bela_cape.dim	Outline dimension
bela_cape.drd	NC Drill (Excellon format)
bela_cape.crc	Component side (top) paste

*** Assembly files:

bela_cape_centroid.csv	XYRS placement data
bela_cape_bom.xls	Bill of materials

-------------------------

This design is derived from the BeagleBone Audio Cape rev. B from CircuitCo: 

http://elinux.org/CircuitCo:Audio_Cape_RevB

This design is available under the Creative Commons Attribution-ShareAlike 3.0 Unported License:

http://creativecommons.org/licenses/by-sa/3.0/

-------------------------

Revision History:

A1 (January 2015)	Internal build.
A2 (May 2015)		First public release. Revised and clarified silkscreen text.
A3 (May 2015)		Fixed soldermask on IC4.
A4 (October 2015)	Replaced J1 with a header for +5V to amps (left DNI in BOM).
			Moved FB4 next to J1 so it can be removed to disconnect +5V.
			The above changes allow amp to be powered separately from BBB/G.
			Changed J7 and J8 to sockets rather than pins.
B1 (March 2016)		Moved J7, J8, J9, J10 to align to 0.1" spacing.
			Added SW1 and R6 for a system shutdown request feature.
			Moved J3-J6 upward slightly to make room for SW1.
			Added test point for Vref on ADC.
			Fixed incorrect labels on J2.
			Changed order of DAC channels on label for J8 (needs to be
			matched with a software change).
			Added better labelling on connectors throughout.
			Changed name to Bela and website to bela.io.
			Added Bela logo on silkscreen.
B2 (September 2017)	Changed C28 and C29 from 0.1uF to 1uF.
			Connected unused pins of J10 to ground.
			Added test point for MICBIAS signal on IC6.
B3 (October 2019)	Changed protection circuit on analog inputs to use Schottky
			diodes to 3.3V and ground rather than ESD protectors.
			Changed power amp feedback resistors R7 and R14 to 43k,
			doubling gain of the amplifiers.
			Reduced headphone resistors R11 and R12 to 15 ohms, increasing
			gain for low impedance headphones.
			Added pulldown resistors on headphone outputs in place of 47pF
			capacitors.
			Silkscreen updated for latest Bela logo and copyright.
B4 (April 2020)		Moved traces on bottom layer away from P9.

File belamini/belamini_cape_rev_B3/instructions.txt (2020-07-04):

Part: belamini_cape, revision B3
--------------------------------

Audio and sensor cape for PocketBeagle, featuring stereo audio codec, 8 channel 16-bit ADC and USB port. Designed for the Bela ultra-low-latency audio environment.

http://bela.io

(c) 2019 Augmented Instruments Ltd 
London, United Kingdom

info@bela.io

-------------------------

Suggested build specifications:

2 layers
1.6mm board thickness
black soldermask
white silkscreen, both sides
standard finish
7 mil minimum feature size
15 mil minimum drill
Tab routing / milling (for panelising)
Double-sided SMT assembly

-------------------------

Package contents:

*** EAGLE Design Files:

belamini_cape_B3.sch	EAGLE schematic
belamini_cape_B3.brd	EAGLE board

*** Gerbers (RS274X unless otherwise noted):

belamini_cape_B3.cmp	Component Side (top) copper
belamini_cape_B3.sol	Solder Side (bottom) copper
belamini_cape_B3.stc	Component side (top) stop mask
belamini_cape_B3.sts	Solder side (bottom) stop mask
belamini_cape_B3.plc	Component side (top) silkscreen
belamini_cape_B3.pls	Solder side (bottom) silkscreen
belamini_cape_B3.dim	Outline dimension
belamini_cape_B3.drd	NC Drill (Excellon format)
belamini_cape_B3.crc	Component side (top) paste
belamini_cape_B3.crs	Solder side (bottom) paste

*** Assembly files:

belamini_cape_B3_centroid.csv	XYRS placement data
belamini_cape_B3_bom.xls	Bill of materials

-------------------------

This design is available under the Creative Commons Attribution-ShareAlike 3.0 Unported License:

http://creativecommons.org/licenses/by-sa/3.0/

-------------------------

Revision History:

A1 			Internal build.
B1 			Internal build. Flip components to solder side.
B2 (March 2018)		First public release. Add ESD protection to USB port
			and ground USB ID bit. Changes to silkscreen.
B3 (May 2019)		Add R6 and R7 to reduce noise on audio output when
			codec is not active.

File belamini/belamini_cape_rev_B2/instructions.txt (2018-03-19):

Part: belamini_cape, revision B2
--------------------------------

Audio and sensor cape for PocketBeagle, featuring stereo audio codec, 8 channel 16-bit ADC and USB port. Designed for the Bela ultra-low-latency audio environment.

http://bela.io

(c) 2018 Augmented Instruments Ltd 
London, United Kingdom

info@bela.io

-------------------------

Suggested build specifications:

2 layers
1.6mm board thickness
black soldermask
white silkscreen, both sides
standard finish
7 mil minimum feature size
15 mil minimum drill
Tab routing / milling (for panelising)
Double-sided SMT assembly

-------------------------

Package contents:

*** EAGLE Design Files:

belamini_cape_B2.sch	EAGLE schematic
belamini_cape_B2.brd	EAGLE board

*** Gerbers (RS274X unless otherwise noted):

belamini_cape_B2.cmp	Component Side (top) copper
belamini_cape_B2.sol	Solder Side (bottom) copper
belamini_cape_B2.stc	Component side (top) stop mask
belamini_cape_B2.sts	Solder side (bottom) stop mask
belamini_cape_B2.plc	Component side (top) silkscreen
belamini_cape_B2.pls	Solder side (bottom) silkscreen
belamini_cape_B2.dim	Outline dimension
belamini_cape_B2.drd	NC Drill (Excellon format)
belamini_cape_B2.crc	Component side (top) paste
belamini_cape_B2.crs	Solder side (bottom) paste

*** Assembly files:

belamini_cape_centroid.csv	XYRS placement data
belamini_cape_B2_bom.xls	Bill of materials

-------------------------

This design is available under the Creative Commons Attribution-ShareAlike 3.0 Unported License:

http://creativecommons.org/licenses/by-sa/3.0/

-------------------------

Revision History:

A1 			Internal build.
B1 			Internal build. Flip components to solder side.
B2 (March 2018)		First public release. Add ESD protection to USB port
			and ground USB ID bit. Changes to silkscreen.

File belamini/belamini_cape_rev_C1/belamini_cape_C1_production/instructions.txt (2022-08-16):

Part: belamini_cape, revision C1
--------------------------------

Audio and sensor cape for PocketBeagle, featuring stereo audio codec, 8 channel 16-bit ADC and USB port. Designed for the Bela ultra-low-latency audio environment.

http://bela.io

(c) 2022 Augmented Instruments Ltd 
London, United Kingdom

info@bela.io

-------------------------

Suggested build specifications:

4 layers
1.6mm board thickness
black soldermask
white silkscreen, both sides
standard finish
7 mil minimum feature size
15 mil minimum drill
Tab routing / milling (for panelising)
Double-sided SMT assembly

-------------------------

Package contents:

*** Gerbers (RS274X unless otherwise noted):

belamini_cape_C1-F_Cu.gbr		Component Side (top) copper
belamini_cape_C1-In1_Cu.gbr		Inner Layer 1 (mid-top) copper
belamini_cape_C1-In2_Cu.gbr		Inner Layer 2 (mid-bottom) copper
belamini_cape_C1-B_Cu.gbr		Solder Side (bottom) copper
belamini_cape_C1-F_Mask.gbr		Component side (top) stop mask
belamini_cape_C1-B_Mask.gbr		Solder side (bottom) stop mask
belamini_cape_C1-F_Silkscreen.gbr	Component side (top) silkscreen
belamini_cape_C1-B_Silkscreen.gbr	Solder side (bottom) silkscreen
belamini_cape_C1-Edge_Cuts.gbr		Outline dimension
belamini_cape_C1-PTH.drl		NC Drill plated holes (Excellon format)
belamini_cape_C1-NPTH.drl		NC Drill non-plated holes (Excellon format)
belamini_cape_C1-F_Paste.gbr		Component side (top) paste
belamini_cape_C1-B_Paste.gbr		Solder side (bottom) paste

*** Assembly files:

belamini_cape_C1-top.pos	Top XYRS placement data
belamini_cape_C1-bottom.pos	Bottom XYRS placement data
belamini_cape_C1_bom.xls	Bill of materials

-------------------------

This design is available under the Creative Commons Attribution-ShareAlike 3.0 Unported License:

http://creativecommons.org/licenses/by-sa/3.0/

-------------------------

Revision History:

A1 			Internal build.
B1 			Internal build. Flip components to solder side.
B2 (March 2018)		First public release. Add ESD protection to USB port
			and ground USB ID bit. Changes to silkscreen.
B3 (May 2019)		Add R6 and R7 to reduce noise on audio output when
			codec is not active.
B4 (November 2020)	Change input protection circuitry (D3, D4, R8, R9).
			Change headphone output resistors R1, R2 to 15 ohms.
			Add I2C pullup resistors R10, R11.
C1 (March 2022)		Change ADC to ADS816x series.
			Changes to passives tos upport ADS816x.
			4-layer PCB for improved ground and power integrity.
			Move design to KiCad.

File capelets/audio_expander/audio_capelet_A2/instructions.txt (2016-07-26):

Part: audio_capelet, revision A2
--------------------------------

Audio expander capelet (cape add-on board) for the Bela low-latency audio/sensor environment. Converts the 8 analog I/Os into extra AC-coupled and filtered audio channels.

http://bela.io

(c) 2016 Laurel Pardue and Andrew McPherson 
Centre for Digital Music
Queen Mary University of London
Mile End Road
London E1 4NS
United Kingdom

a.mcpherson@qmul.ac.uk

-------------------------

Suggested build specifications:

4 layers
1.6mm board thickness
black soldermask
white silkscreen, both sides
standard finish
7 mil minimum feature size
15 mil minimum drill
Tab routing / milling (for panelising)
double-sided assembly

-------------------------

Package contents:

*** EAGLE Design Files:

audio_capelet.sch	EAGLE schematic
audio_capelet.brd	EAGLE board

*** Gerbers (RS274X unless otherwise noted):

audio_capelet.cmp	Component Side (top) copper
audio_capelet.ly2	Inner layer copper
audio_capelet.ly3	Inner layer copper
audio_capelet.sol	Solder Side (bottom) copper
audio_capelet.stc	Component side (top) stop mask
audio_capelet.sts	Solder side (bottom) stop mask
audio_capelet.plc	Component side (top) silkscreen
audio_capelet.pls	Solder side (bottom) silkscreen
audio_capelet.dim	Outline dimension
audio_capelet.drd	NC Drill (Excellon format)
audio_capelet.crc	Component side (top) paste
audio_capelet.crs	Solder side (bottom) paste

*** Assembly files:

audio_capelet_centroid.csv	XYRS placement data
audio_capelet_bom.xls		Bill of materials
audio_capelet_partlist.txt	Parts list 
				(last column specifies top "R" or bottom "MR" assembly)

-------------------------

This design is available under the Creative Commons Attribution-ShareAlike 3.0 Unported License:

http://creativecommons.org/licenses/by-sa/3.0/

-------------------------

Revision History:

A1 (May 2016)		Initial design.
A2 (July 2016)		Fixed which 5V power traces are used.
			Fixed missing trace to reference voltage regulator.
			Fixed connection of resistors on analog in amplifiers.
			Added new connector J11 which allows disconnecting from audio in.
			Clarified numbering of connector J12 which should be socket 
			like J11.
			Minor layout change on bottom layer to make orientation of
			components less ambiguous.
			Board outline is slightly elongated to allow for J11.
			Renumbered I/Os from 1-8 to 0-7.

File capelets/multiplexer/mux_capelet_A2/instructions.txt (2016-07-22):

Part: mux_capelet, revision A2
--------------------------------

Multiplexer capelet (cape add-on board) for the Bela low-latency audio/sensor environment. Adds support for 64 analog inputs channels to the Bela cape.

http://bela.io

(c) 2016 Andrew McPherson 
Centre for Digital Music
Queen Mary University of London
Mile End Road
London E1 4NS
United Kingdom

a.mcpherson@qmul.ac.uk

-------------------------

Suggested build specifications:

2 layers
1.6mm board thickness
black soldermask
white silkscreen, top side
standard finish
7 mil minimum feature size
15 mil minimum drill
Tab routing / milling (for panelising)

-------------------------

Package contents:

*** EAGLE Design Files:

mux_capelet.sch	EAGLE schematic
mux_capelet.brd	EAGLE board

*** Gerbers (RS274X unless otherwise noted):

mux_capelet.cmp	Component Side (top) copper
mux_capelet.sol	Solder Side (bottom) copper
mux_capelet.stc	Component side (top) stop mask
mux_capelet.sts	Solder side (bottom) stop mask
mux_capelet.plc	Component side (top) silkscreen
mux_capelet.dim	Outline dimension
mux_capelet.drd	NC Drill (Excellon format)
mux_capelet.crc	Component side (top) paste

Files named mux_capelet_breakout are for a separate breakout board containing
J5, J9, J10 (or equivalently J6, J11, J12). Two of these should be made.

*** Assembly files:

mux_capelet_centroid.csv	XYRS placement data
mux_capelet_bom.xls		Bill of materials

-------------------------

This design is available under the Creative Commons Attribution-ShareAlike 3.0 Unported License:

http://creativecommons.org/licenses/by-sa/3.0/

-------------------------

Revision History:

A1 (March 2016)		Initial design.
A2 (May 2016)		Fixed power source from VDD_5V (barrel jack only) to SYS_5V.
			Changed board outline to allow audio expander underneath.

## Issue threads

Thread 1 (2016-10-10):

Allow "plug-in power" ("MICBIAS") on the cape

giuliomoro, 2016-10-10:
Wishlist:

Pin 15 of the TLV320AIC3104 , with a couple of resistors should do it .
Check out "11.2.2 Typical Connections for AC-Coupled Headphone Output With Separate Line Outputs and External Speaker Amplifier" pag 86 of the datasheet."

Raised here: http://forum.bela.io/d/73-microphone-to-speaker/4

Closed 2017-09-01.

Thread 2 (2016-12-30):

Provide ground on J10

giuliomoro, 2016-12-30:
Two pads on J10 are currently nc but could conveniently be connected to ground.

apmcpherson, 2016-12-31:
I left those NC because on J9, they are connected to the minus output of the left and right line outputs (which are otherwise unused on the current design). If someone cuts the traces to install an effect loop, I at least didn't want there to be any harm in connecting all four pads across. If having ground there is useful, perhaps it would be better to add another pad so it is unambiguous.

Closed 2017-09-01.

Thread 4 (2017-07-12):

Change C28, C29 to 1uF

transmogrifox, 2017-07-12:
Changing ADC level changes input impedance to a value as low as 20 k ohms.  With 0.1 uF value as shown in the BOM, the high-pass cut-off is:
```
1/(2*pi*20k*0.1u) = 79.6 Hz
|h|dB = 20*log10[ sqrt((s*r*c)^2)/sqrt(1+(s*r*c)^2) ]
|h|dB = -12.2612
```

A change to 1 uF will have the following effect:
```
s = j2*pi*20
r = 20k
c = 1u

fc=1/(2*pi*r*c)
fc = 7.9577

|h|dB = 20*log10[ sqrt((s*r*c)^2)/sqrt(1+(s*r*c)^2) ]
|h|dB = -638.2644m
```

The proposed DSP high-pass (DC removal) filter is also designed for 8 Hz cut-off, which yields another -638 mdB for a combined response of -1.28 dB at 20 Hz and -55mdB at 100  Hz (99%).

TLV320AIC3104 datasheet page 36:

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

Closed 2017-09-01.

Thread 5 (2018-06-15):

Evaluate the opportunity pull-down resistor for spi0_d0 and spi0_d1 pin on Bela cape

giuliomoro, 2018-06-15:
When you want to force booting from the SD card, you hold press the USER button (which effectively shorts P8_43 to GND). This changes the boot order to:
- SPI
- SD card

Sometimes (often?) the board fails to boot, possibly because it receives some stray signal on  spi0_d0 or spi0_d1 (check the BBB's manual to see which one is expected to be used for iincoming data). Possibly, adding a pull down there could resolve this issue.

This is more of a documentation thing than an actual feature request.

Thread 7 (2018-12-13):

Pull down resistor for codec headphone out (and probably line out as well)

giuliomoro, 2018-12-13:
to avoid loud static noise when the codec is powered down (high impedance) and you are going into a high impedance (DI) input

Closed 2021-02-10.

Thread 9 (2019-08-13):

USB power on BelaMini should come from Vsys 5V

giuliomoro, 2019-08-13:
On the PB:

1) VBUS.RAW (the 5V in from the µUSB on the PB) is connected through a ferrite bead (FB1) to the VIN.USB signal (broken out on P1.07 and labelled USB1.VIN). This is also connected to ball J16 of the BGA, which is USB0_VBUS. This has the following consequences:
- if power is supplied through USB0 (µUSB on the PB), then USB1.VIN will also be powered.
- if power is supplied through USB1 (header), then the AM335x will think that USB0 has power.

2) the OSD335x checklist (https://octavosystems.com/app_notes/osd335x-schematic-checklist-am335x/) says

> USB VBUS Sense Input: USBx_VBUS is a voltage sense input and NOT a power output pin. Check that a valid voltage (>=4.4V) is present on the pin to enable the USBx peripheral.

3) the [TPS65217](http://www.ti.com/lit/ds/symlink/tps65217.pdf) can allow large currents from input to the Vsys output, and ranges can be set in software:
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

4) Jason K is happy to review the amended design.

giuliomoro, 2019-08-13:
This https://github.com/beagleboard/capes/blob/master/pocketbeagle/GamePup/GamePup_Cape_sch.pdf , according to Jason, "should do USB host right"  (and uses a [boost converter](http://www.ti.com/product/TPS61202) to generate the right 5V for USB regardless of the VIN/VBAT input voltage).

giuliomoro, 2019-08-14:
from https://octavosystems.com/app_notes/osd335x-design-tutorial/osd335x-lesson-2-minimal-linux-boot/osd335x-lesson-2-usb-circuitry/

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

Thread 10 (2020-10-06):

Add pull-up resistor for I2C-2

giuliomoro, 2020-10-06:
The lack of it can cause problems in creative and unexpected ways

https://forum.bela.io/d/1376-new-board-new-problem/2
https://forum.bela.io/d/1438-mux-capelet-errors

giuliomoro, 2021-02-10:
This is still an issue for Bela cape

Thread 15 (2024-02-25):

bela_cape-eagle-import.kicad_sym not found

birdshao, 2024-02-25:
when open the bela_cape_rev_v3 project using kicad, bela_cape-eagle-import.kicad_sym not found, where can get it?

mxa, 2024-02-27:
Just checking, we're talking about `bela_cape_rev_C3`?

birdshao, 2024-02-27:
> Just checking, we're talking about `bela_cape_rev_C3`?

Yes, when load the project bela_cape_rev_C3 to kicad, it seems missing some footprint library and package library

mxa, 2024-02-27:
.kicad_sym is a symbol in the schematic, not a footprint. It's just referenced in the file `sym-lib-table` but not actually used. Delete the file `sym-lib-table` and it should open without the error message.

giuliomoro, 2024-02-27:
@mxa does this need `sym-lib-table` shouldn't be included in version control?

mxa, 2024-02-27:
I've removed it with commit 555166d entirely. If it has needed paths to local libraries it should be included in the version control, but in our case it contained just one reference to a long deleted and obsolete local library.

birdshao, 2024-02-27:
> `.kicad_sym` is a symbol in the schematic, not a footprint. It's only referenced in the file `sym-lib-table` but not actually used in the schematic. Delete the file `sym-lib-table` and the project should open without the error message.

There's still some errors. I import footprint library bela.pretty and Bela.kicad_sym(where I found in the folder .\belamini\belamini_cape_rev_C1) to kicad. When I update footprints and symbols from library, the error shows like:
Error: Updated footprint IC6 (Bela:QFN40P500X500X80-41N-D): *** library footprint not found ***
Error: Updated footprint G1 (Bela:Bela-Logo_30mm_Silkscreen): *** library footprint not found ***
Error: Updated footprint P1 (Bela:BeagleBone_Black_Sockets_Board_outline): *** library footprint not found ***
and
Error: Update symbol P1 from 'Bela:BeagleBone_Black_Header' to 'Bela:BeagleBone_Black_Header': *** symbol not found ***
Error: Update symbol G1 from 'Bela:Bela-Logo' to 'Bela:Bela-Logo': *** symbol not found ***
Error: Update symbol P1 from 'Bela:BeagleBone_Black_Header' to 'Bela:BeagleBone_Black_Header': *** symbol not found ***
Error: Update symbol IC6 from 'Bela:ES9080Q' to 'Bela:ES9080Q': *** symbol not found ***
Error: Update symbol IC1 from 'Bela:PAM8406' to 'Bela:PAM8406': *** symbol not found ***
(If not import Bela.kicad_sym, there will be 3 more errors)

So I guess some footprints and symbols are missing in the libraries. I can download the footprints and symbols of some  missing ICs from mouser, but I can't get the exact library version of some ICs like BeagleBone_Black_Header\Bela-Logo which matches the project.

birdshao, 2024-02-27:
> @birdshao I don't think any of this is really an issue since KiCad stores copies of all used symbols and footprints in the schematic and layout file anyways. So you can open these files and look at the layout for debugging or even manufacture the PCB if you like. In any case, I've added symbols and more footprints with commit [5fe71ca](https://github.com/BelaPlatform/bela-hardware/commit/5fe71ca13c240c204a8c8fe817fc99a9a0d7c39a)

Yes, U are right. Thanks for your patient help. I'm not familiar with kicad. I find out I can open the symbol or footprint which is missing in the library first, then save and add it into the library. By that way, the library will be complete.

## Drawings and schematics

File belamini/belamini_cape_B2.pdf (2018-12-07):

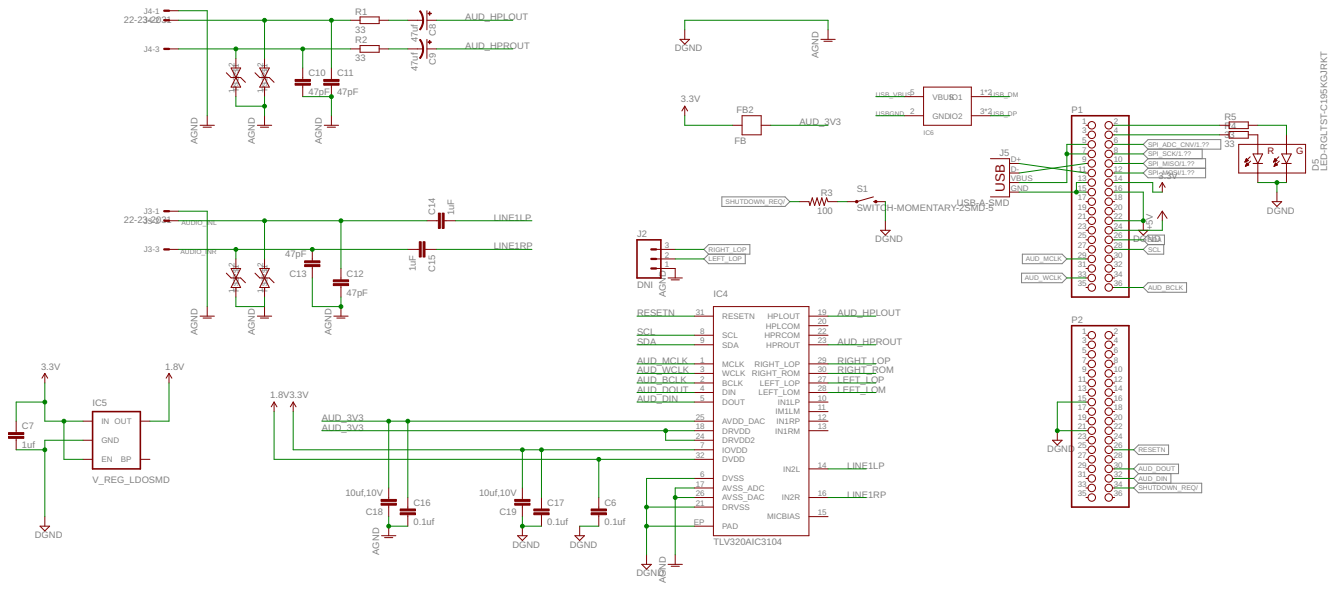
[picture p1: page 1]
AGND; AGND AGND; LED-RGLTST-C195KGJRKT; 5INGN; USB

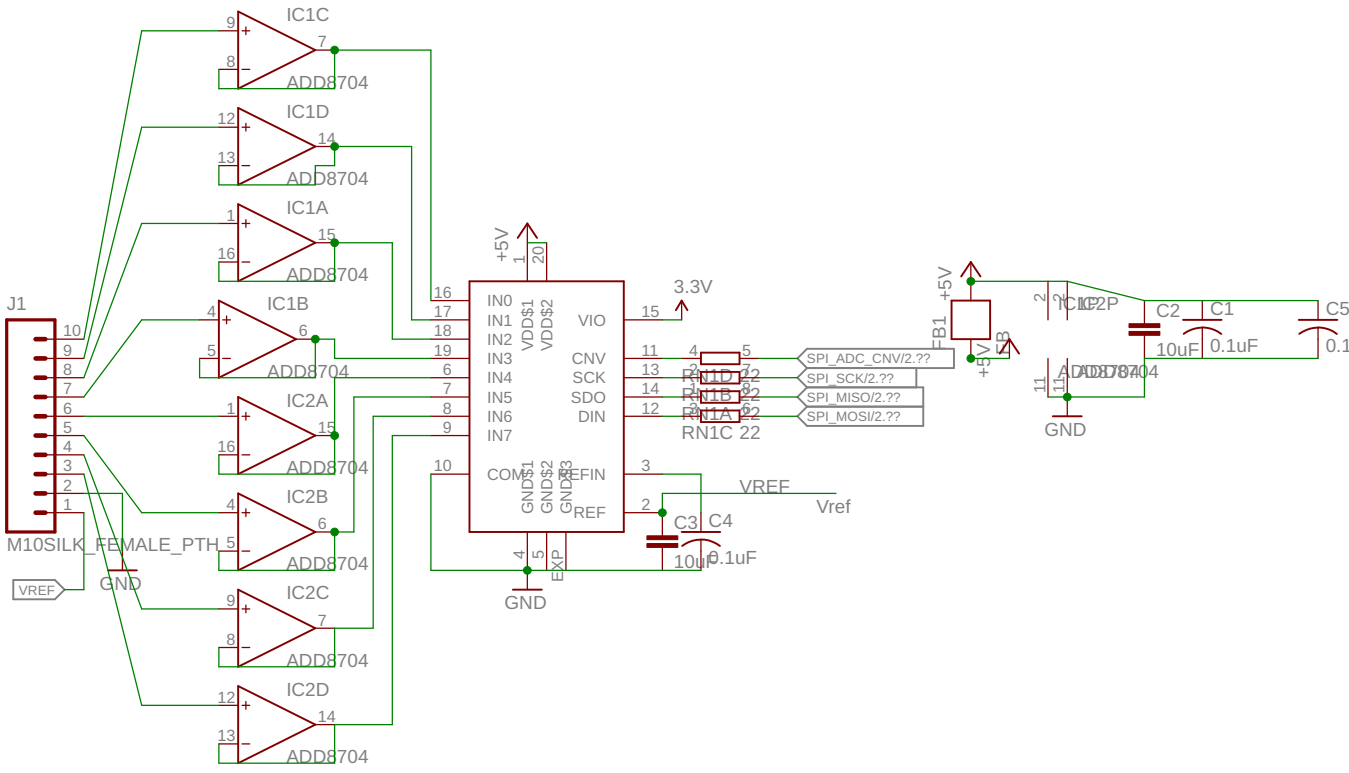
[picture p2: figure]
GND$2 5; VDD$2 20; GND$1 4 VDD$1 1; GND$3 EXP; R¹N

1

u

F

5

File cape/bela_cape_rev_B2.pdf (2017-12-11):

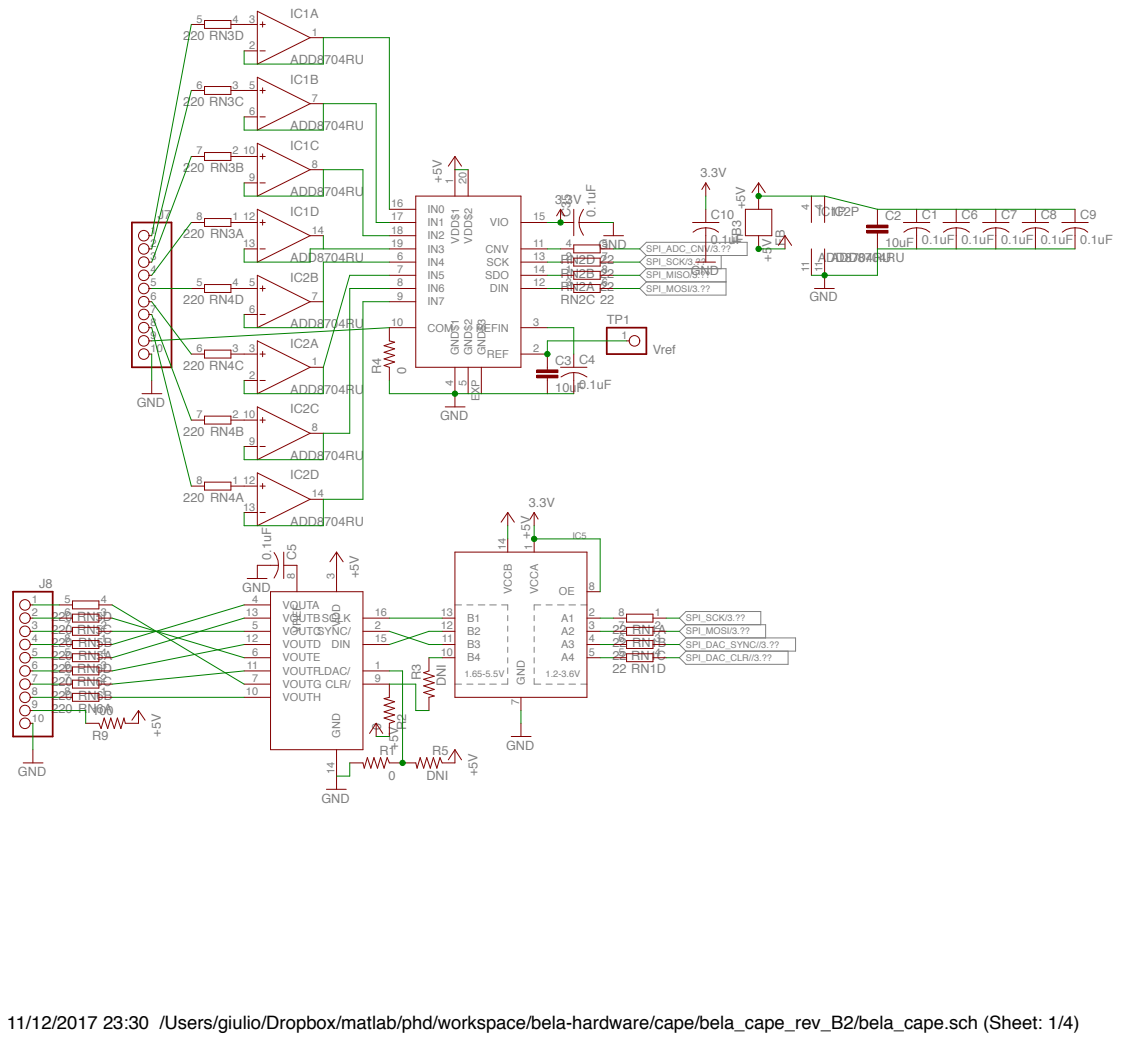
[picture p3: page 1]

11/12/2017 23:30 /Users/giulio/Dropbox/matlab/phd/workspace/bela-hardware/cape/bela_cape_rev_B2/bela_cape.sch (Sheet: 1/4)

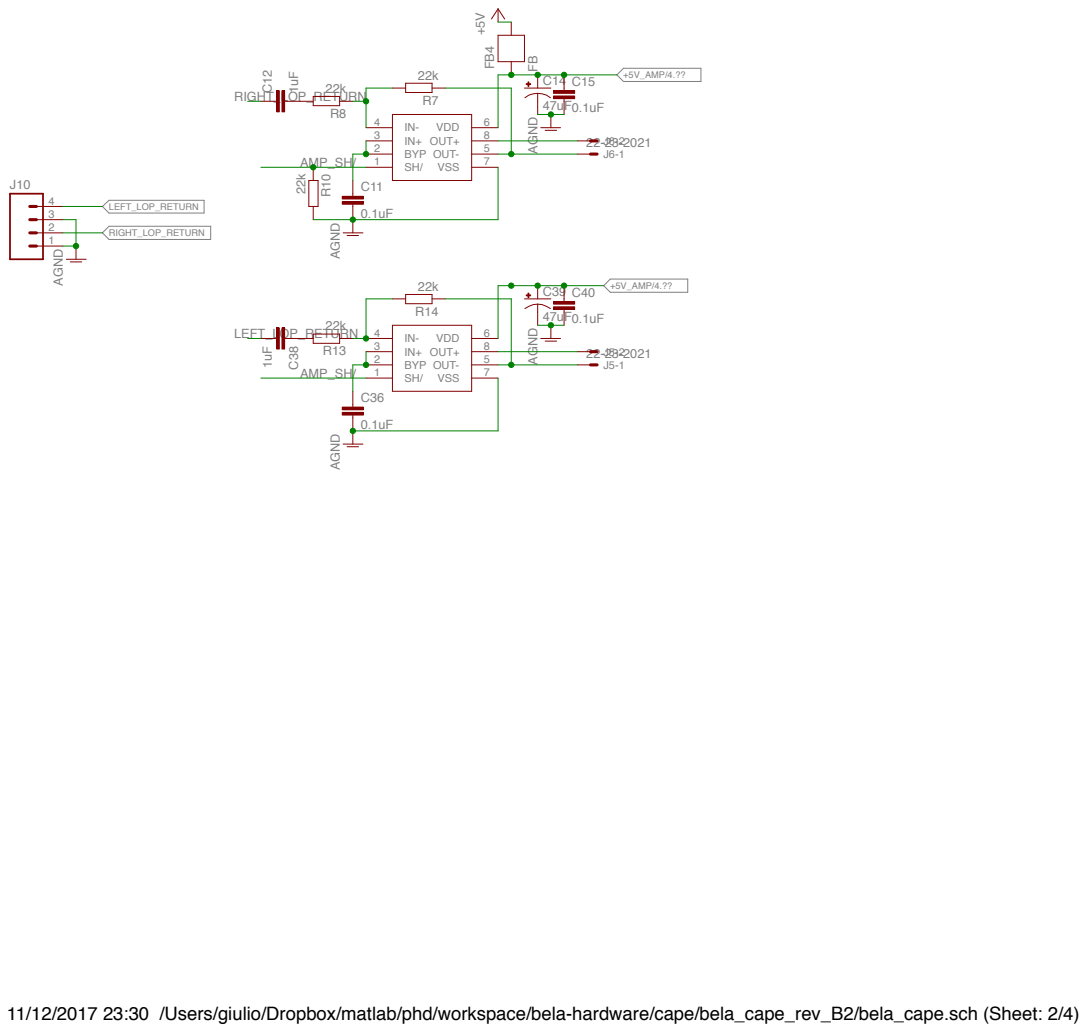
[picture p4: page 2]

11/12/2017 23:30 /Users/giulio/Dropbox/matlab/phd/workspace/bela-hardware/cape/bela_cape_rev_B2/bela_cape.sch (Sheet: 2/4)

11/12/2017 23:30 /Users/giulio/Dropbox/matlab/phd/workspace/bela-hardware/cape/bela_cape_rev_B2/bela_cape.sch (Sheet: 3/4) ⁴⁷uf 47uf

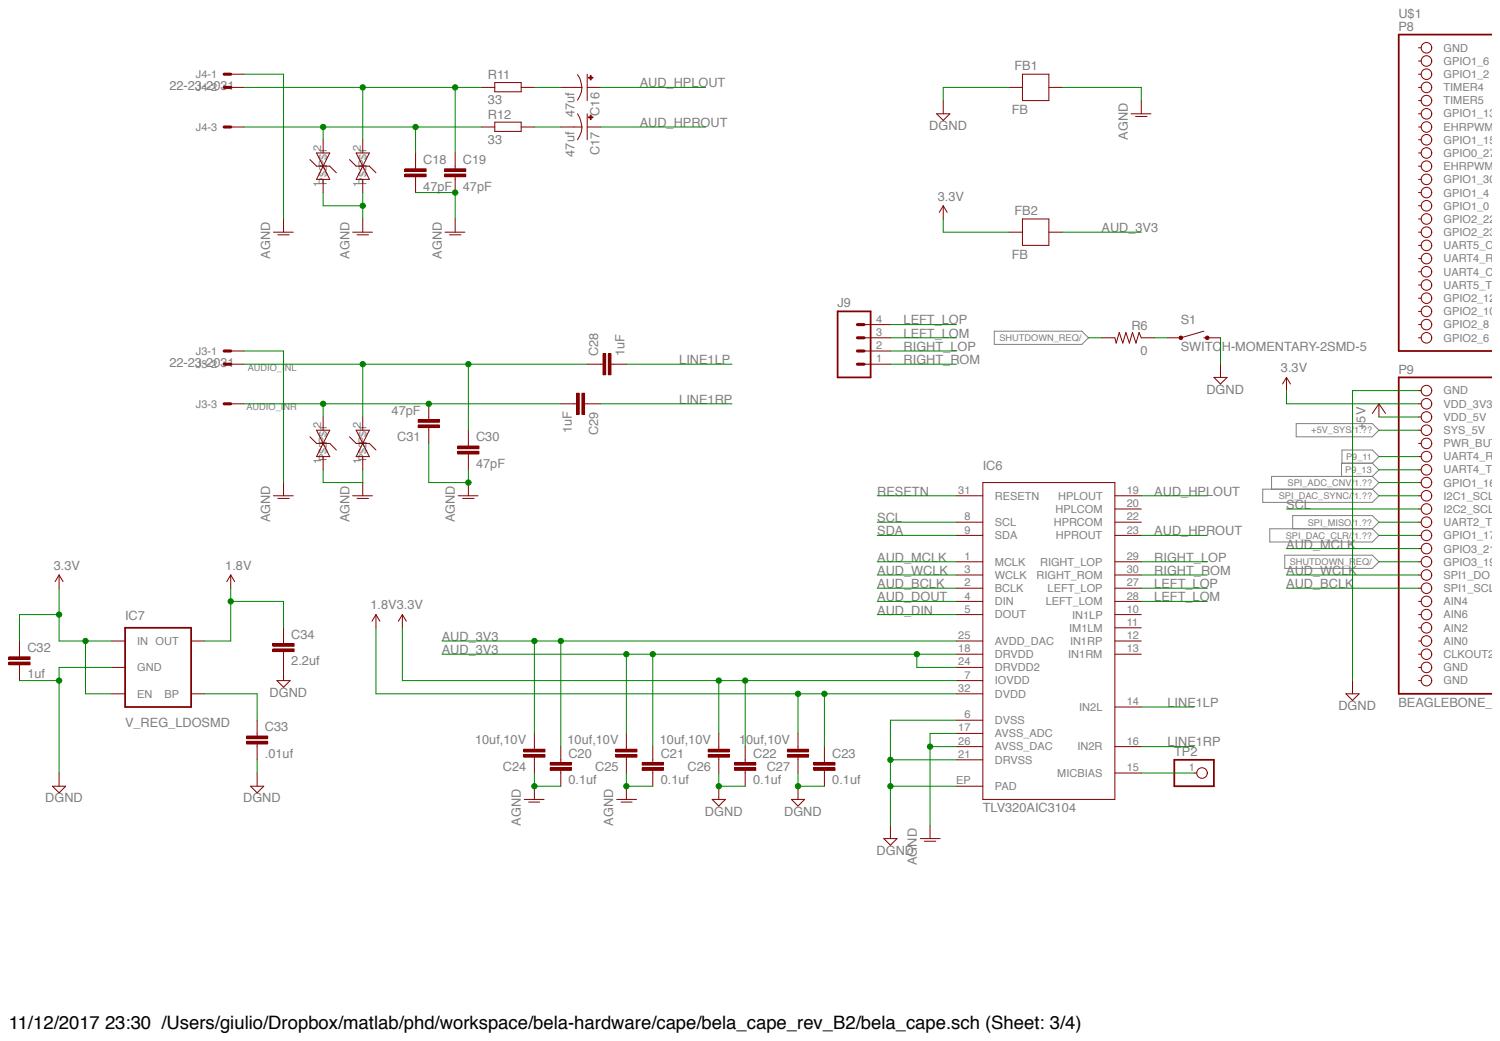
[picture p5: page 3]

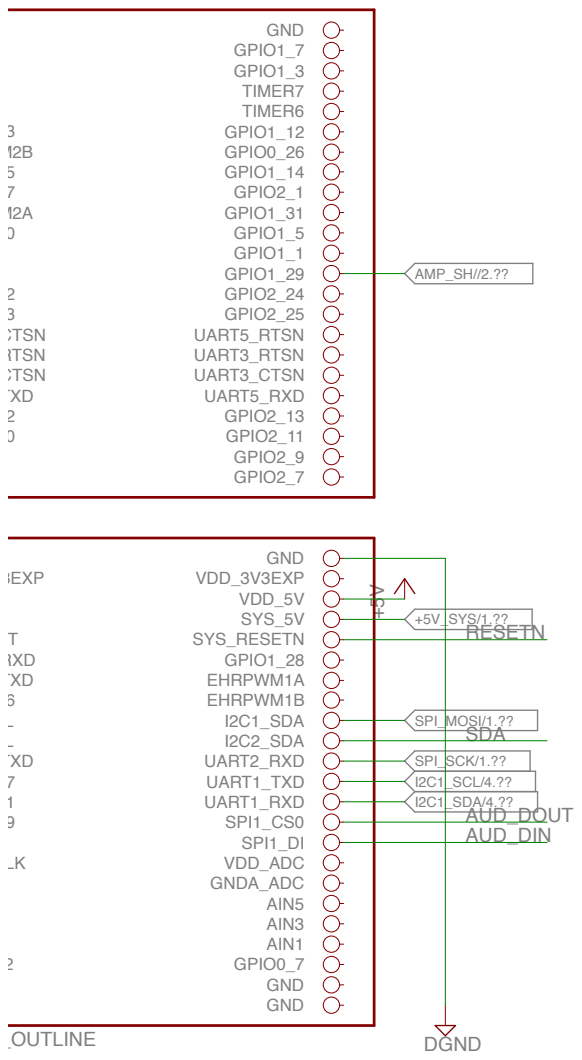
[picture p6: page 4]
BEAGLEBONE_OUTLINE; DGND; GND; VDD_3V3EXP; VDD_5V; SYS_5V; PWR_BUT; SYS_RESETN; UART4_RXD; GPIO1_28; UART4_TXD; EHRPWM1A; GPIO1_16; EHRPWM1B; I2C1_SCL; I2C1_SDA; I2C2_SCL; I2C2_SDA; UART2_TXD; UART2_RXD; GPIO1_17; UART1_TXD; GPIO3_21; UART1_RXD; GPIO3_19; SPI1_CS0; SPI1_DO; SPI1_DI; SPI1_SCLK; VDD_ADC; AIN4; GNDA_ADC; AIN6; AIN5; AIN2; AIN3; AIN0; AIN1; CLKOUT2; GPIO0_7; GPIO1_6; GPIO1_7; GPIO1_2; GPIO1_3; TIMER4; TIMER7; TIMER5; TIMER6; GPIO1_13; GPIO1_12; EHRPWM2B; GPIO0_26; GPIO1_15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

11/12/2017 23:30 /Users/giulio/Dropbox/matlab/phd/workspace/bela-hardware/cape/bela_cape_rev_B2/bela_cape.sch (Sheet: 4/4)

22-23-2041

3.3V

# GND².2k 2.2k

22-23-2021

+5V

J2-1

J2-2
J2-3
J2-4

R21

R22

J1-1
J1-2

I2C1_SCL/3.??
I2C1_SDA/3.??

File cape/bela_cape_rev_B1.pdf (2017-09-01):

## ADD8704RU

## ADD8704RU

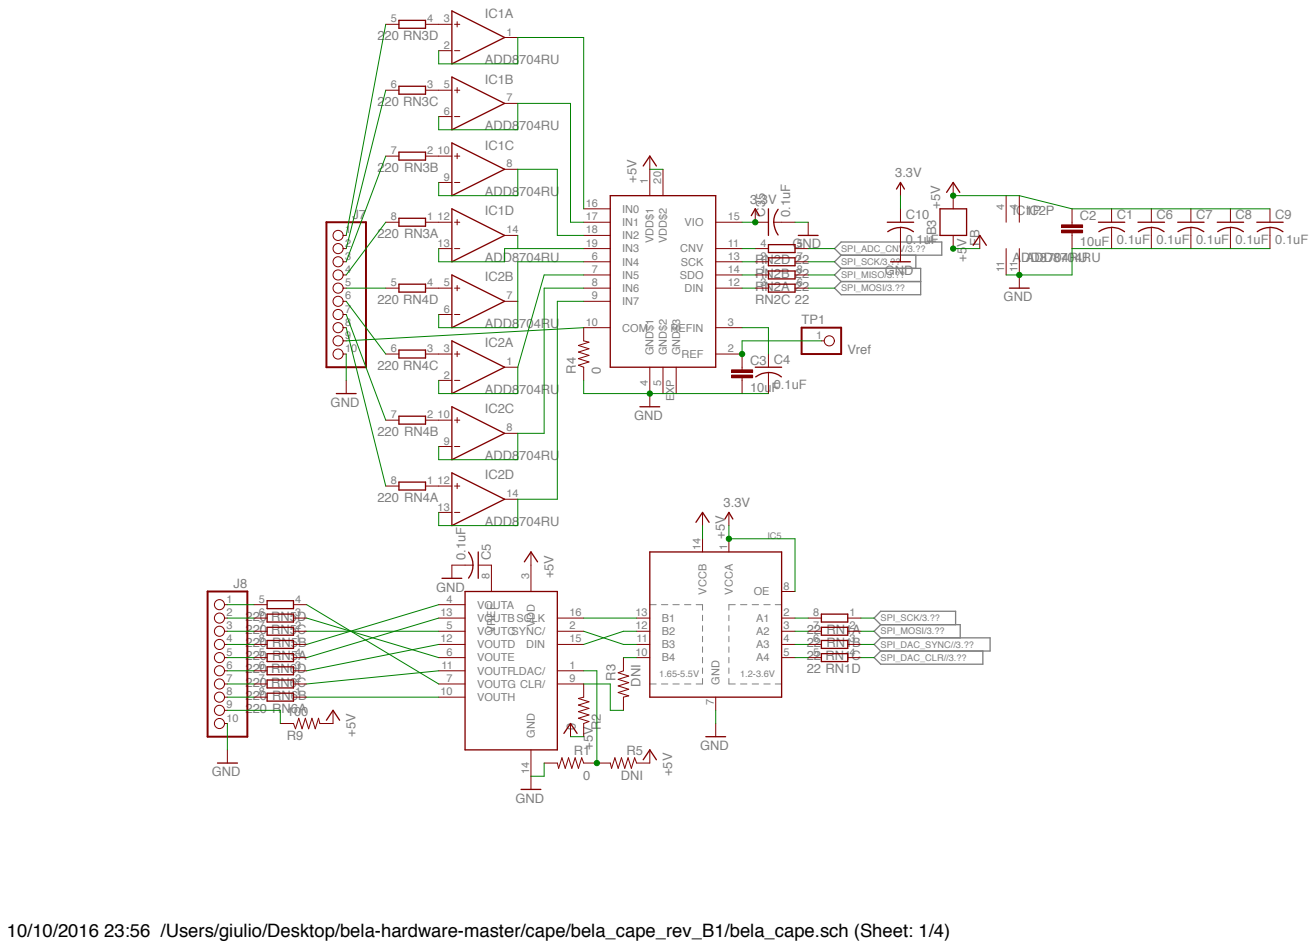
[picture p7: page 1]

10/10/2016 23:56 /Users/giulio/Desktop/bela-hardware-master/cape/bela_cape_rev_B1/bela_cape.sch (Sheet: 1/4)

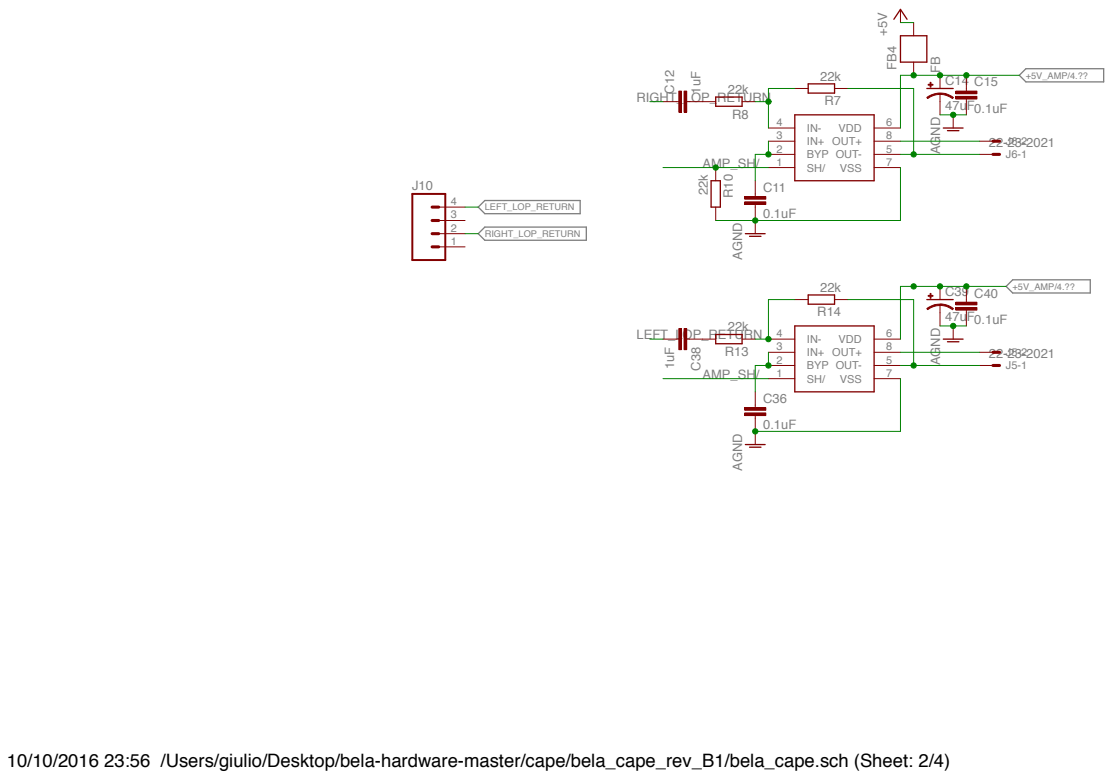
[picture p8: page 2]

10/10/2016 23:56 /Users/giulio/Desktop/bela-hardware-master/cape/bela_cape_rev_B1/bela_cape.sch (Sheet: 2/4)

10/10/2016 23:58 f=0.80 /Users/giulio/Desktop/bela-hardware-master/cape/bela_cape_rev_B1/bela_cape.sch (Sheet: 3/4) ⁴⁷uf 47uf

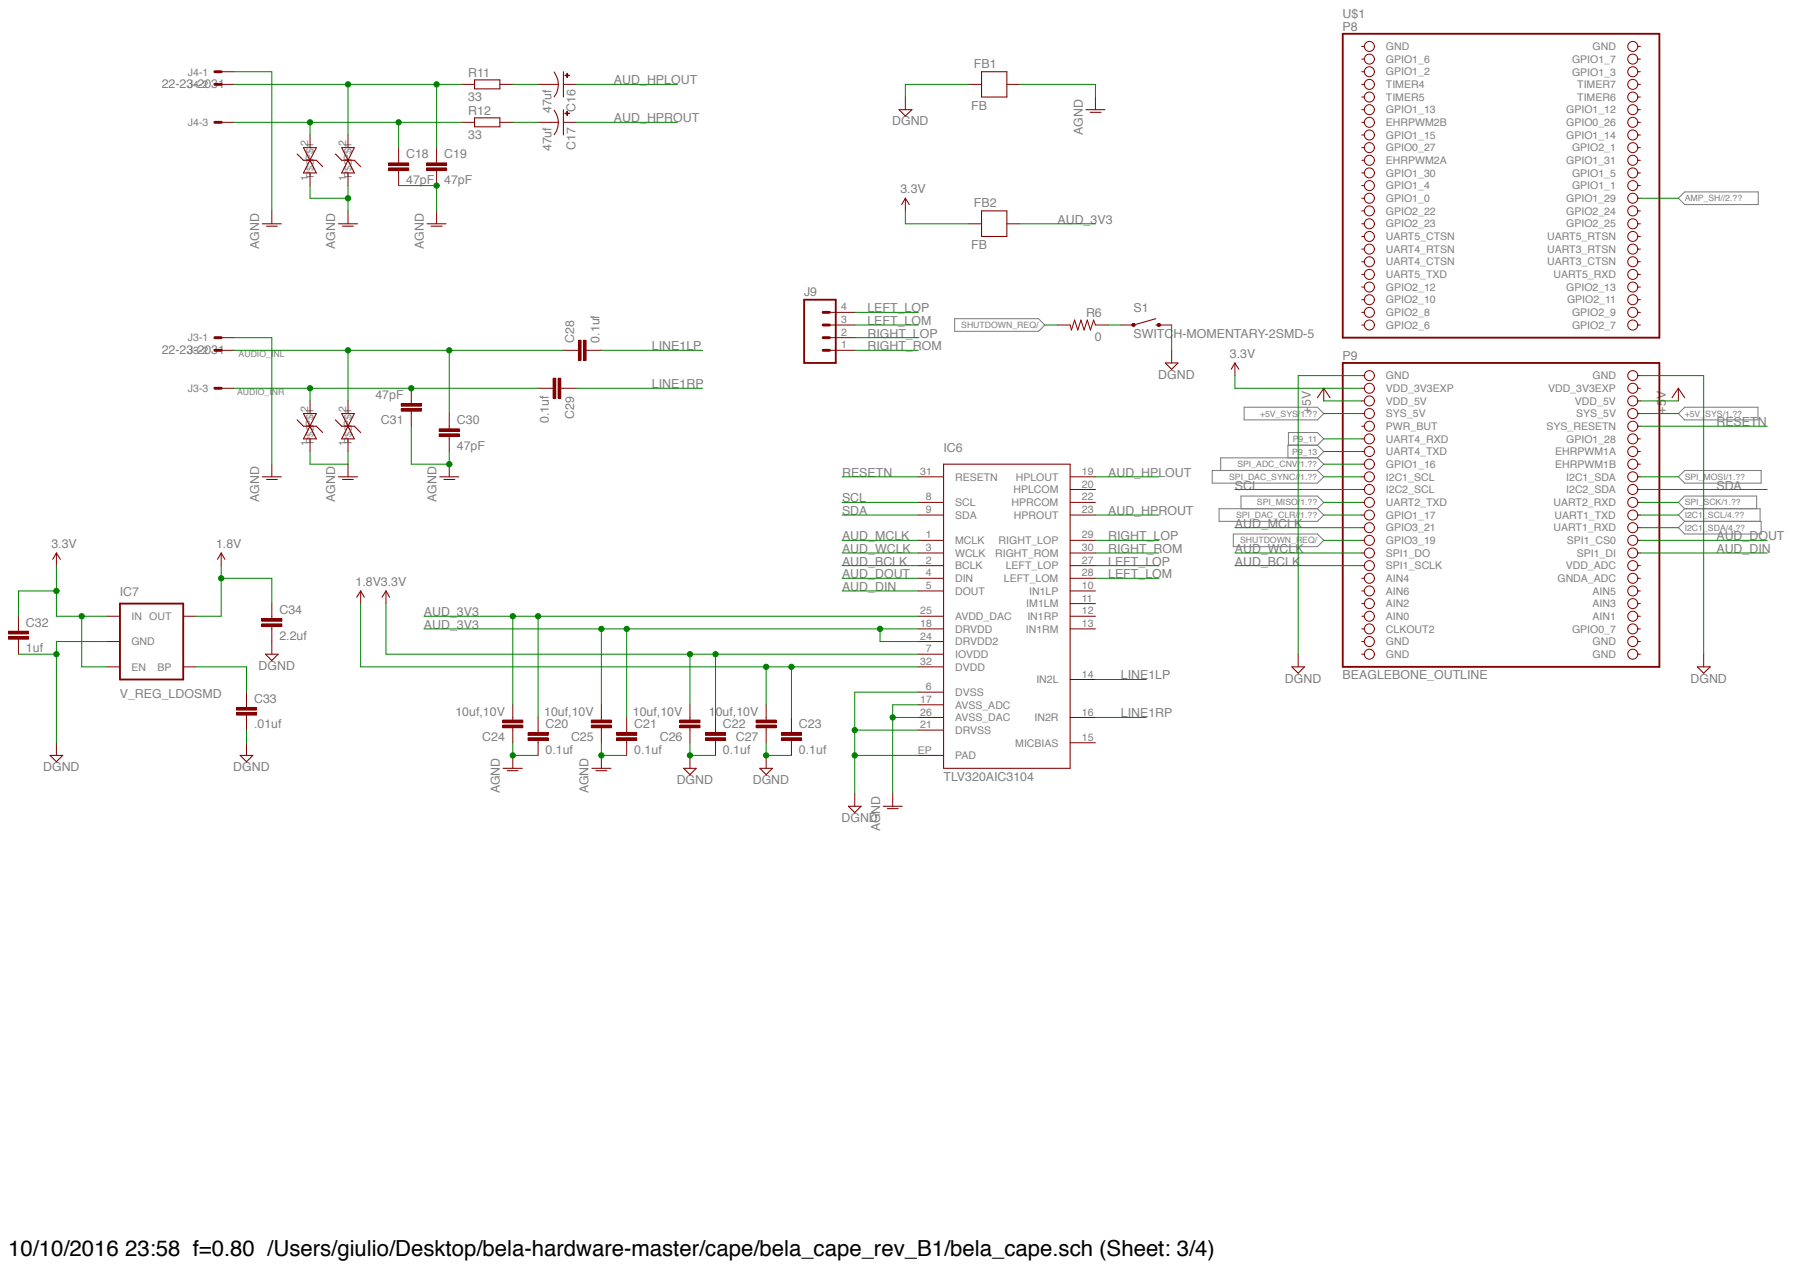
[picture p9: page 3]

DVDD 32

AVSS_ADC 17

10/10/2016 23:58 /Users/giulio/Desktop/bela-hardware-master/cape/bela_cape_rev_B1/bela_cape.sch (Sheet: 4/4)

22-23-2041

3.3V

# GND².2k 2.2k

22-23-2021

+5V

J2-1

J2-2
J2-3
J2-4

R21

R22

J1-1
J1-2

I2C1_SCL/3.??
I2C1_SDA/3.??

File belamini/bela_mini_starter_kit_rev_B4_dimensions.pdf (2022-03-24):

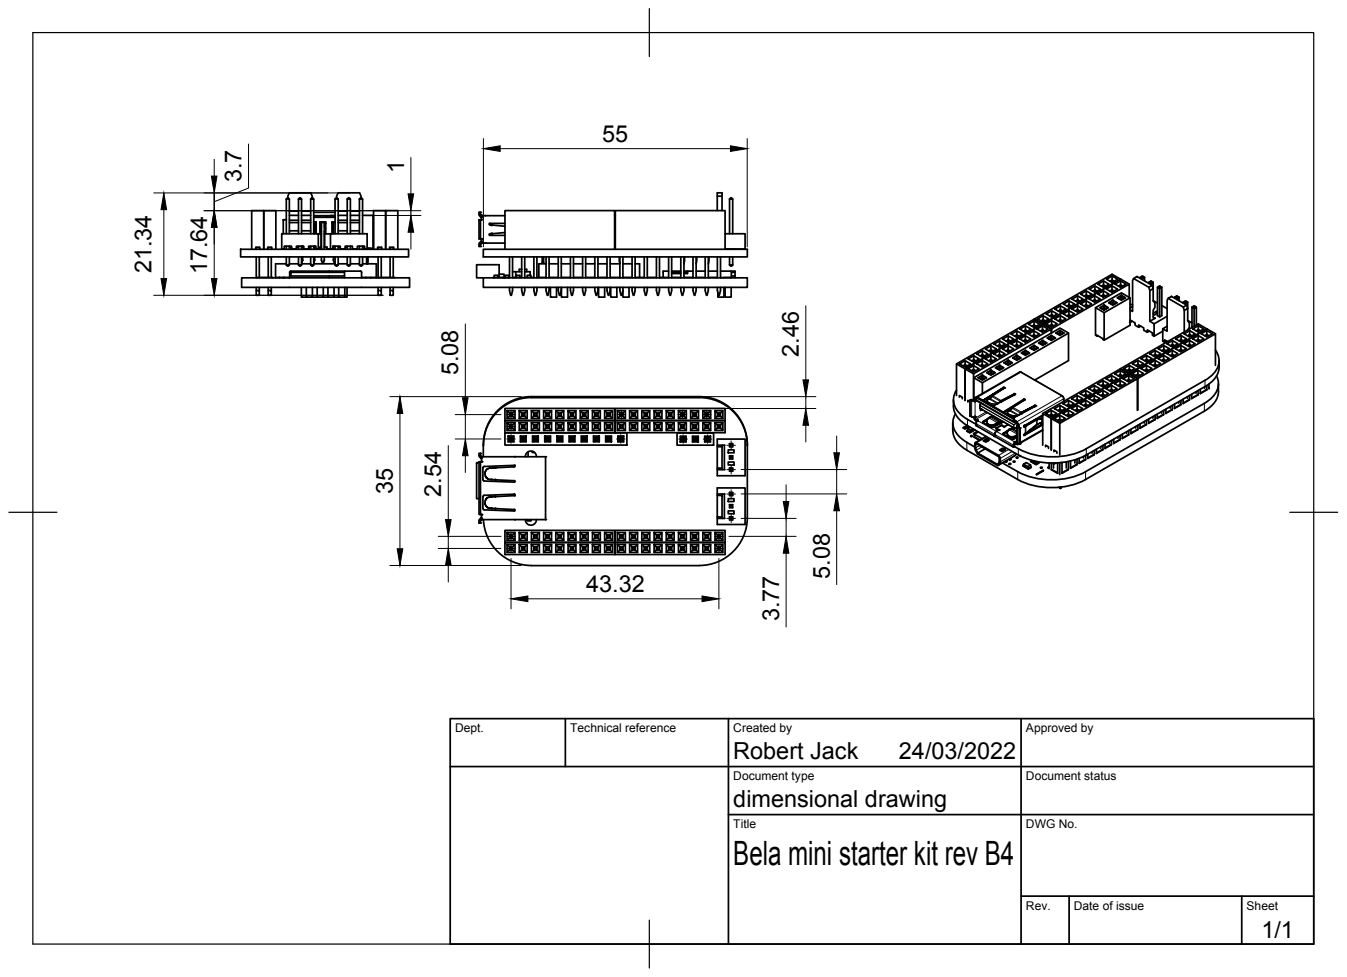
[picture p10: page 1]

Dept. | Technical reference | Created by Robert Jack 24/03/2022 | Approved by

Document type dimensional drawing | Document status

Title Bela mini starter kit rev B4 | DWG No.

Rev. | Date of issue | Sheet 1/1

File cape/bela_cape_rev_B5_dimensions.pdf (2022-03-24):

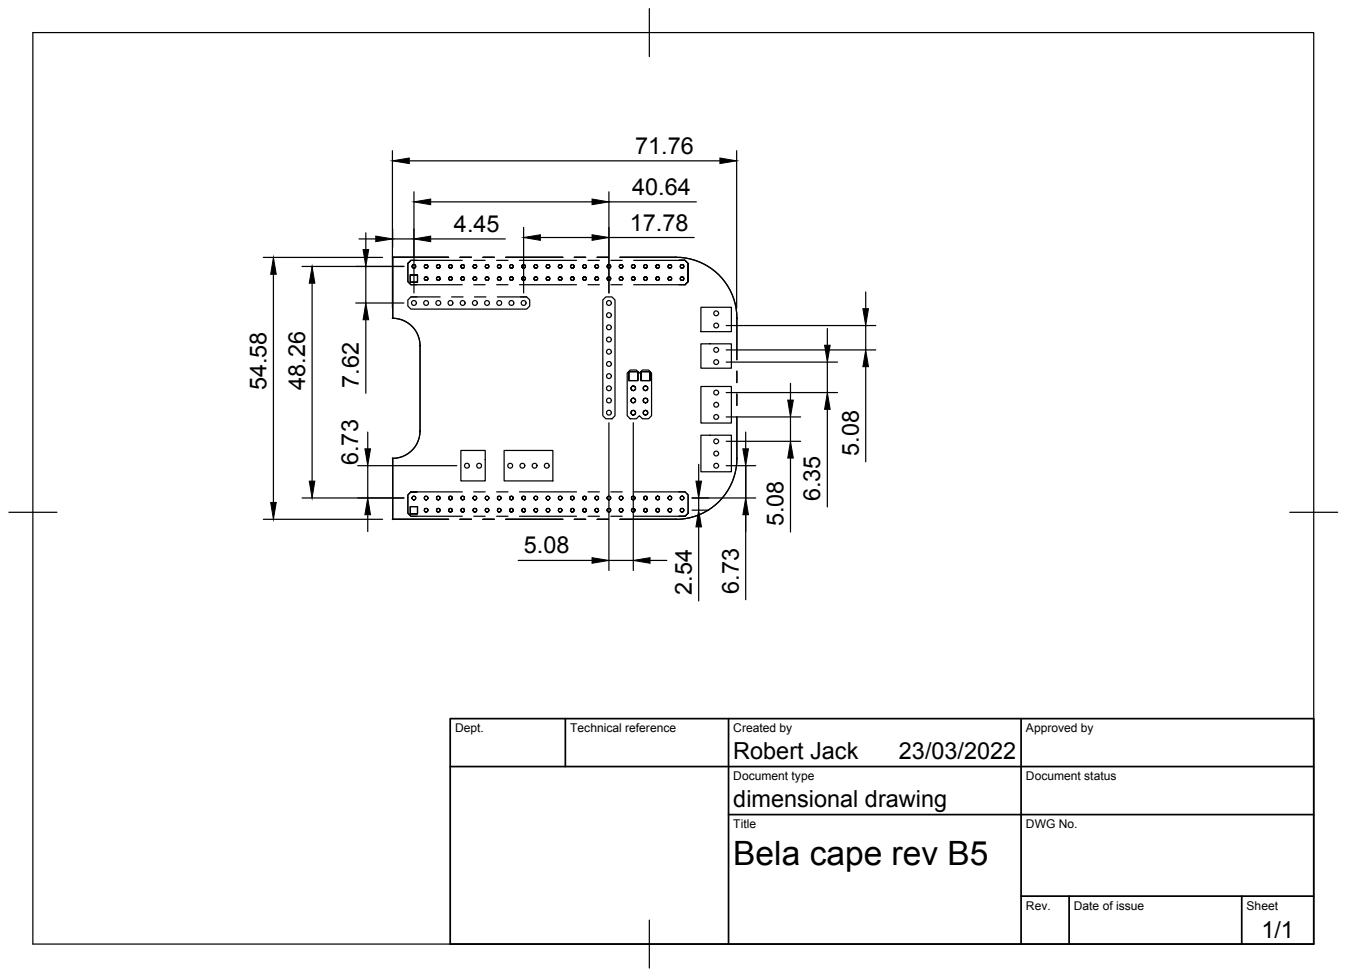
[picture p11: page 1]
Robert Jack 54.58

Dept. | Technical reference | Created by 23/03/2022 | Approved by

Document type dimensional drawing | Document status

Title Bela cape rev B5 | DWG No.

Rev. | Date of issue | Sheet 1/1

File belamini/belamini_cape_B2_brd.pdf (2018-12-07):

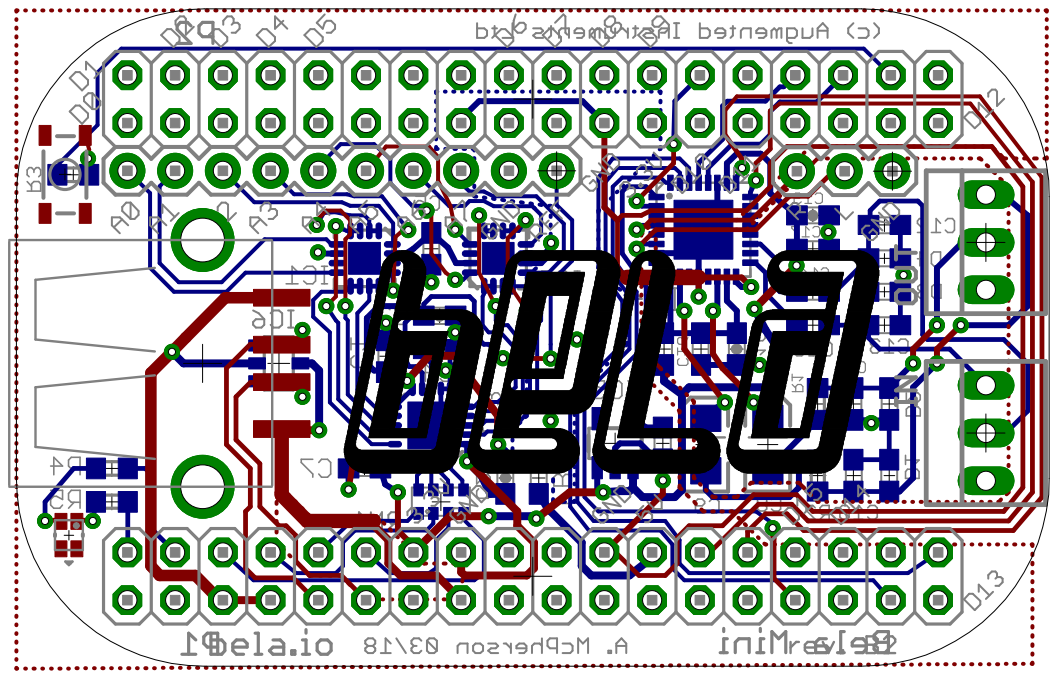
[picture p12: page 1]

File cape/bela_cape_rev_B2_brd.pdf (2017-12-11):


11/12/2017 23:26 /Users/giulio/Dropbox/matlab/phd/workspace/bela-hardware/cape/bela_cape_rev_B2/bela_cape.brd P⁸ P⁹

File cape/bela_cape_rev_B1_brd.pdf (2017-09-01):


08/12/2016 22:15 /Users/giulio/Dropbox/matlab/phd/workspace/bela-hardware/cape/bela_cape_rev_B1/bela_cape.brd P⁸ P⁹

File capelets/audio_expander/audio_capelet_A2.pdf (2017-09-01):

# 330pF ³³⁰pF

# 330pF ³³⁰pF


11/10/2016 00:03 f=0.45 /Users/giulio/Desktop/bela-hardware-master/capelets/audio_expander/audio_capelet_A2/audio_capelet.sch (Sheet: 1/1)


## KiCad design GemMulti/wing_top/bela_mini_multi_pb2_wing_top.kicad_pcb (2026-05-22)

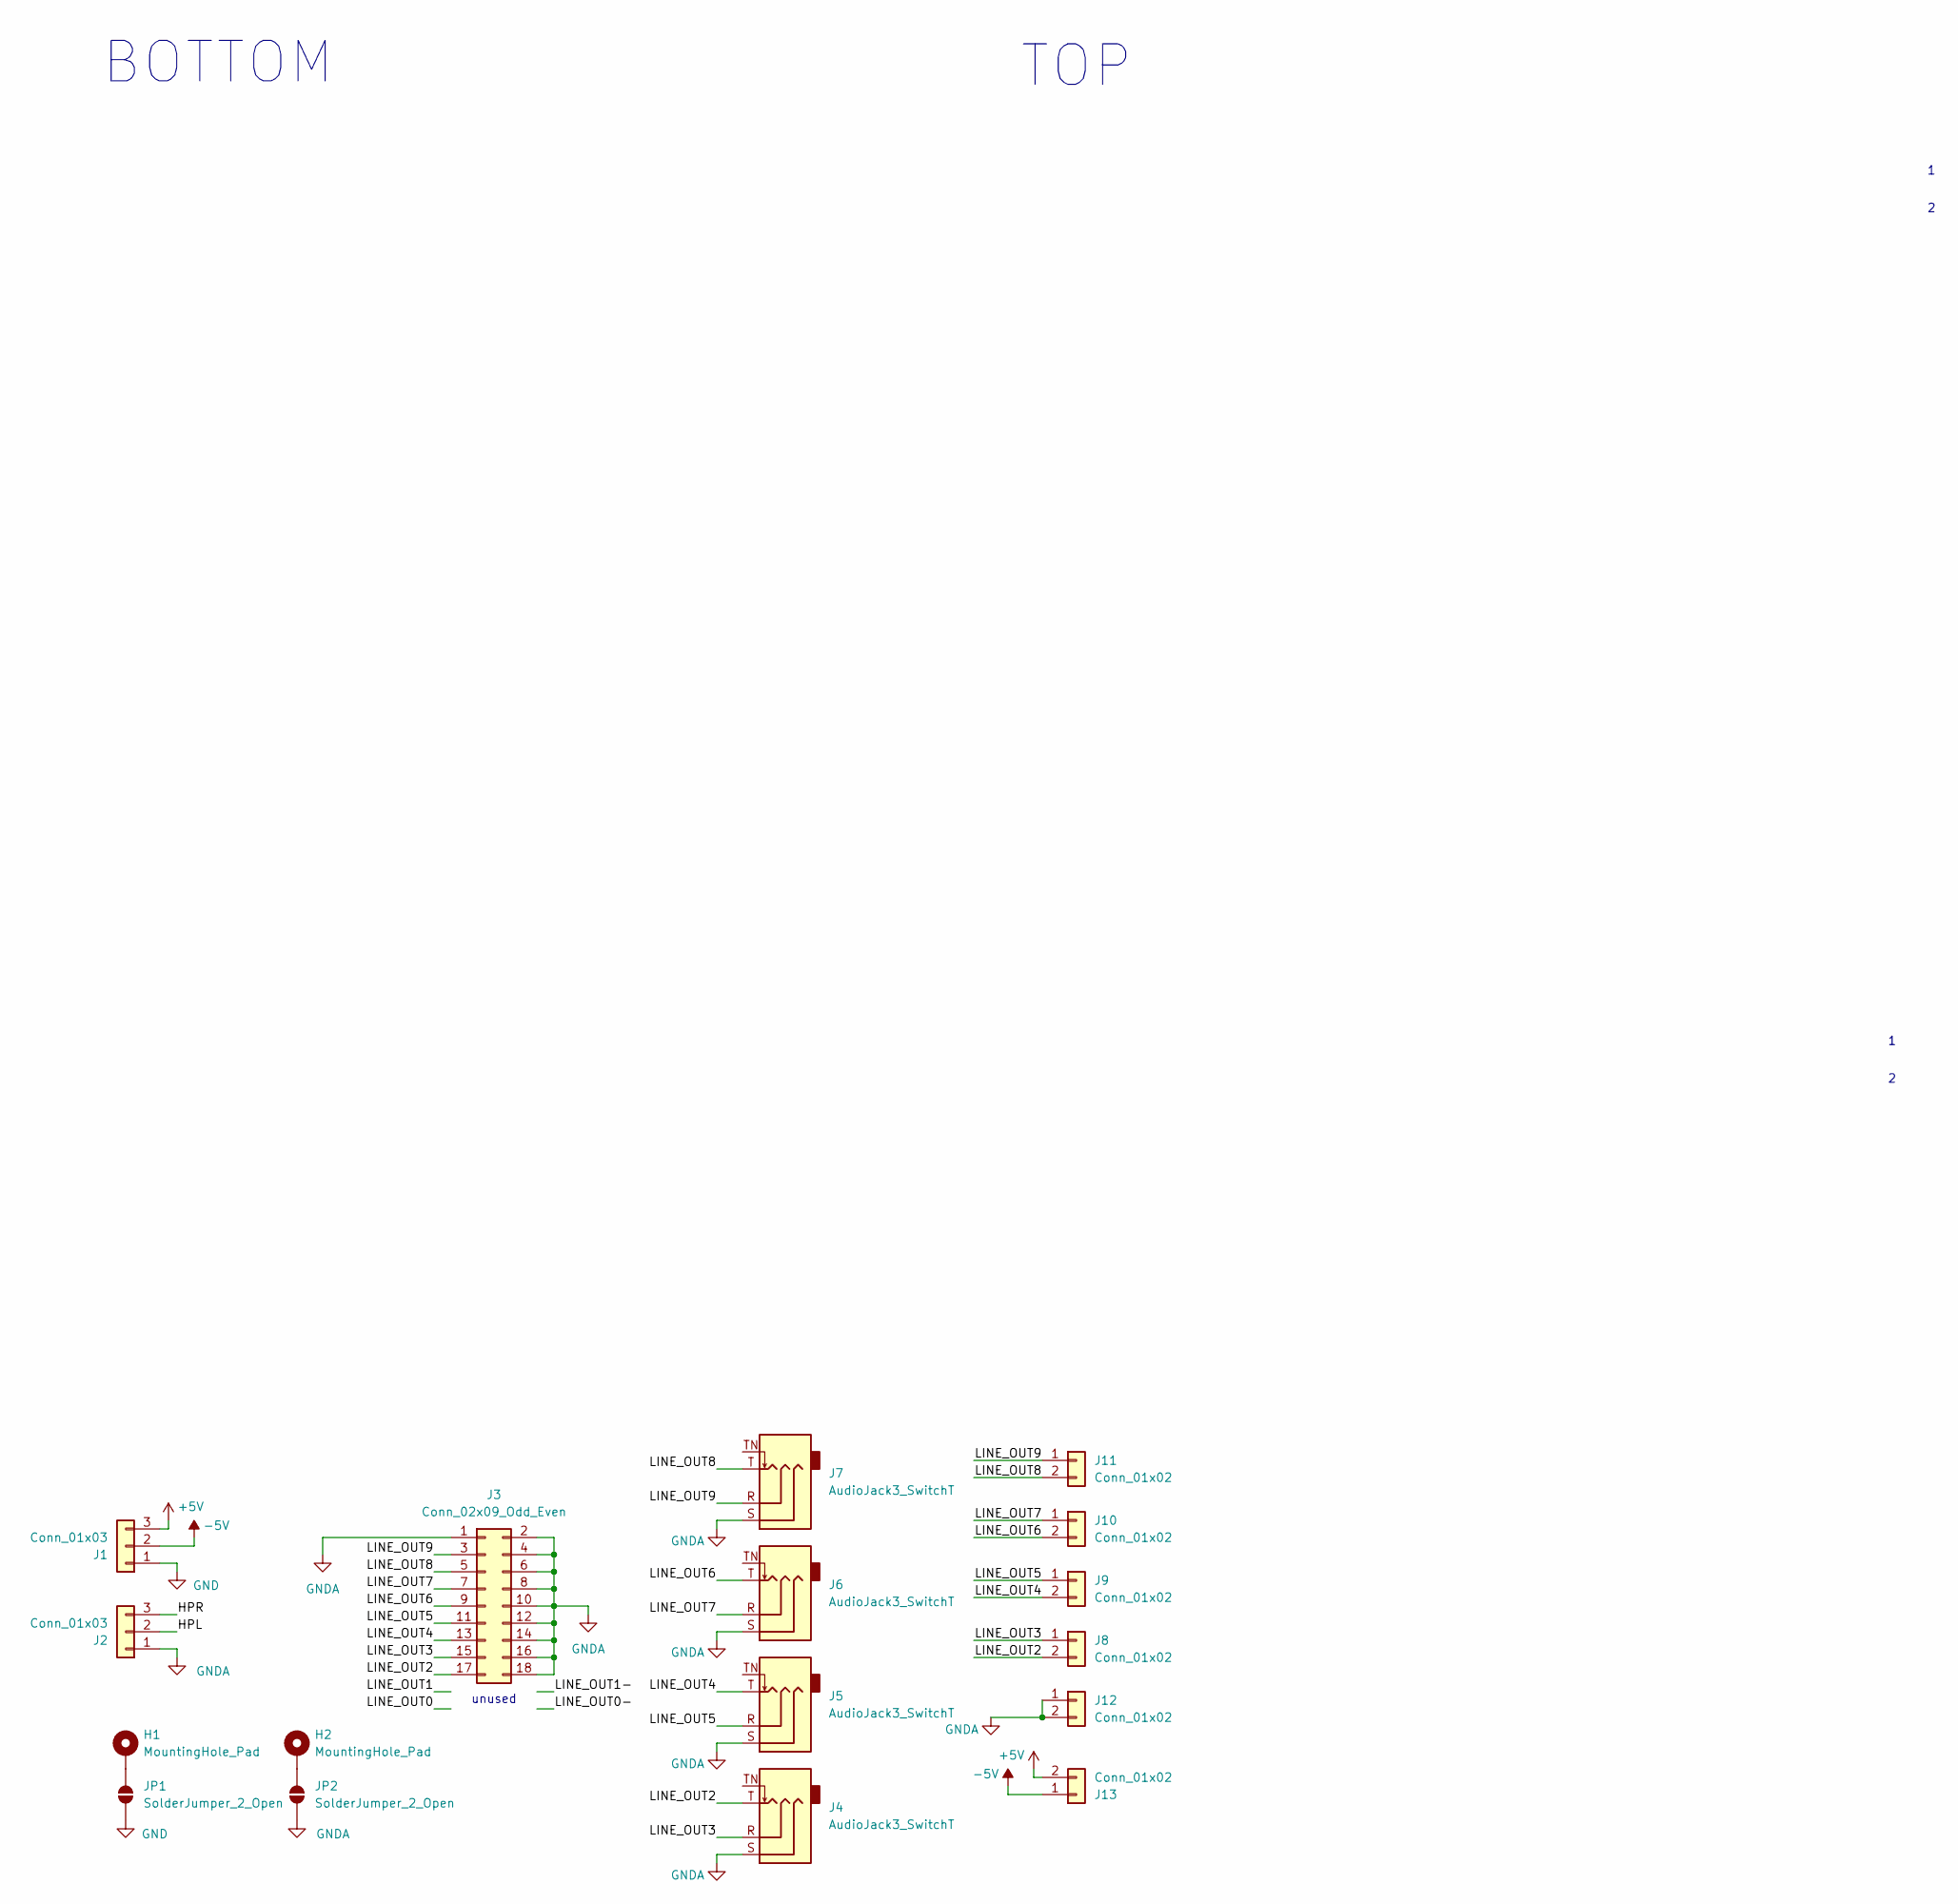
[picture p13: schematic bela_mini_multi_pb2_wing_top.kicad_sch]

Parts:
H1, H2: MountingHole_Pad; MountingHole_3.2mm_M3_DIN965_Pad
J1, J2: Conn_01x03; PinHeader_1x03_P2.54mm_Vertical
J3: Conn_02x09_Odd_Even; PinHeader_2x09_P2.54mm_Vertical_SMD
J4, J5, J6, J7: AudioJack3_SwitchT; Jack_3.5mm_SameSky_SJ235813BSMTTR
J8, J9, J10, J11, J12, J13: Conn_01x02; PinSocket_1x02_P2.54mm_Vertical
JP1, JP2: SolderJumper_2_Open; SolderJumper-2_P1.3mm_Open_RoundedPad1.0x1.5mm

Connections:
+5V: J1.3, J13.2
-5V: J1.2, J13.1
/HPL: J2.2
/HPR: J2.3
/LINE_OUT2: J3.17, J4.T, J8.2
/LINE_OUT3: J3.15, J4.R, J8.1
/LINE_OUT4: J3.13, J5.T, J9.2
/LINE_OUT5: J3.11, J5.R, J9.1
/LINE_OUT6: J3.9, J6.T, J10.2
/LINE_OUT7: J3.7, J6.R, J10.1
/LINE_OUT8: J3.5, J7.T, J11.2
/LINE_OUT9: J3.3, J7.R, J11.1
GND: J1.1, JP1.1 (A)
GNDA: J2.1, J3.1, J3.2, J3.4, J3.6, J3.8, J3.10, J3.12, J3.14, J3.16, J3.18, J4.S, J5.S, J6.S, J7.S, J12.1, J12.2, JP2.1 (A)
unnamed: H1.1, JP1.2 (B)
unnamed: H2.1, JP2.2 (B)

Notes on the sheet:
unused
BOTTOM
TOP

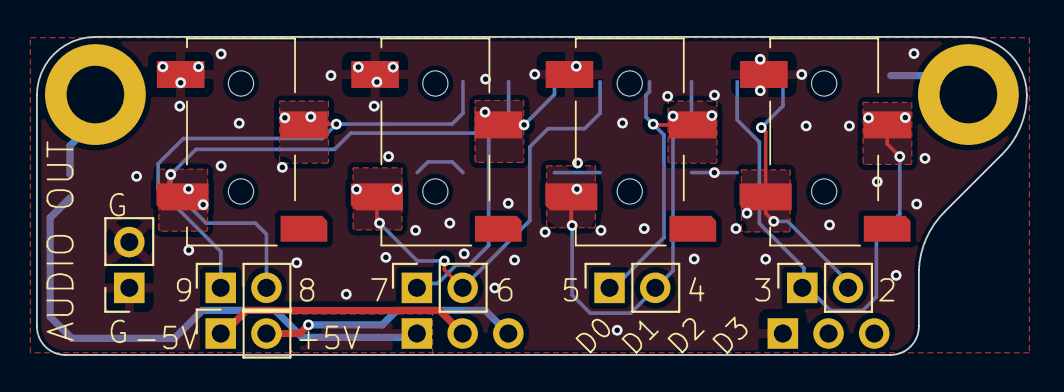
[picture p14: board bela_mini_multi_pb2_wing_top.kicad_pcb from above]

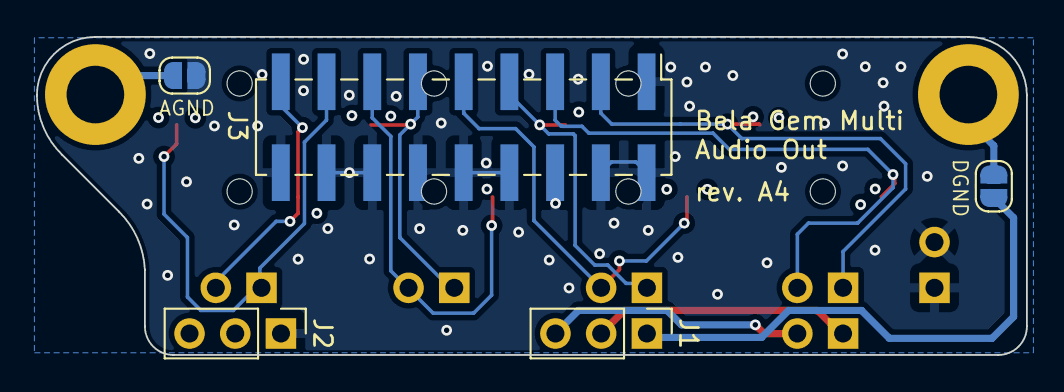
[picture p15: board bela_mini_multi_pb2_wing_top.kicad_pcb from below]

Board: 2 copper layers, 55.0 x 17.7 mm, 17 parts (5 on the bottom side), 14 nets.

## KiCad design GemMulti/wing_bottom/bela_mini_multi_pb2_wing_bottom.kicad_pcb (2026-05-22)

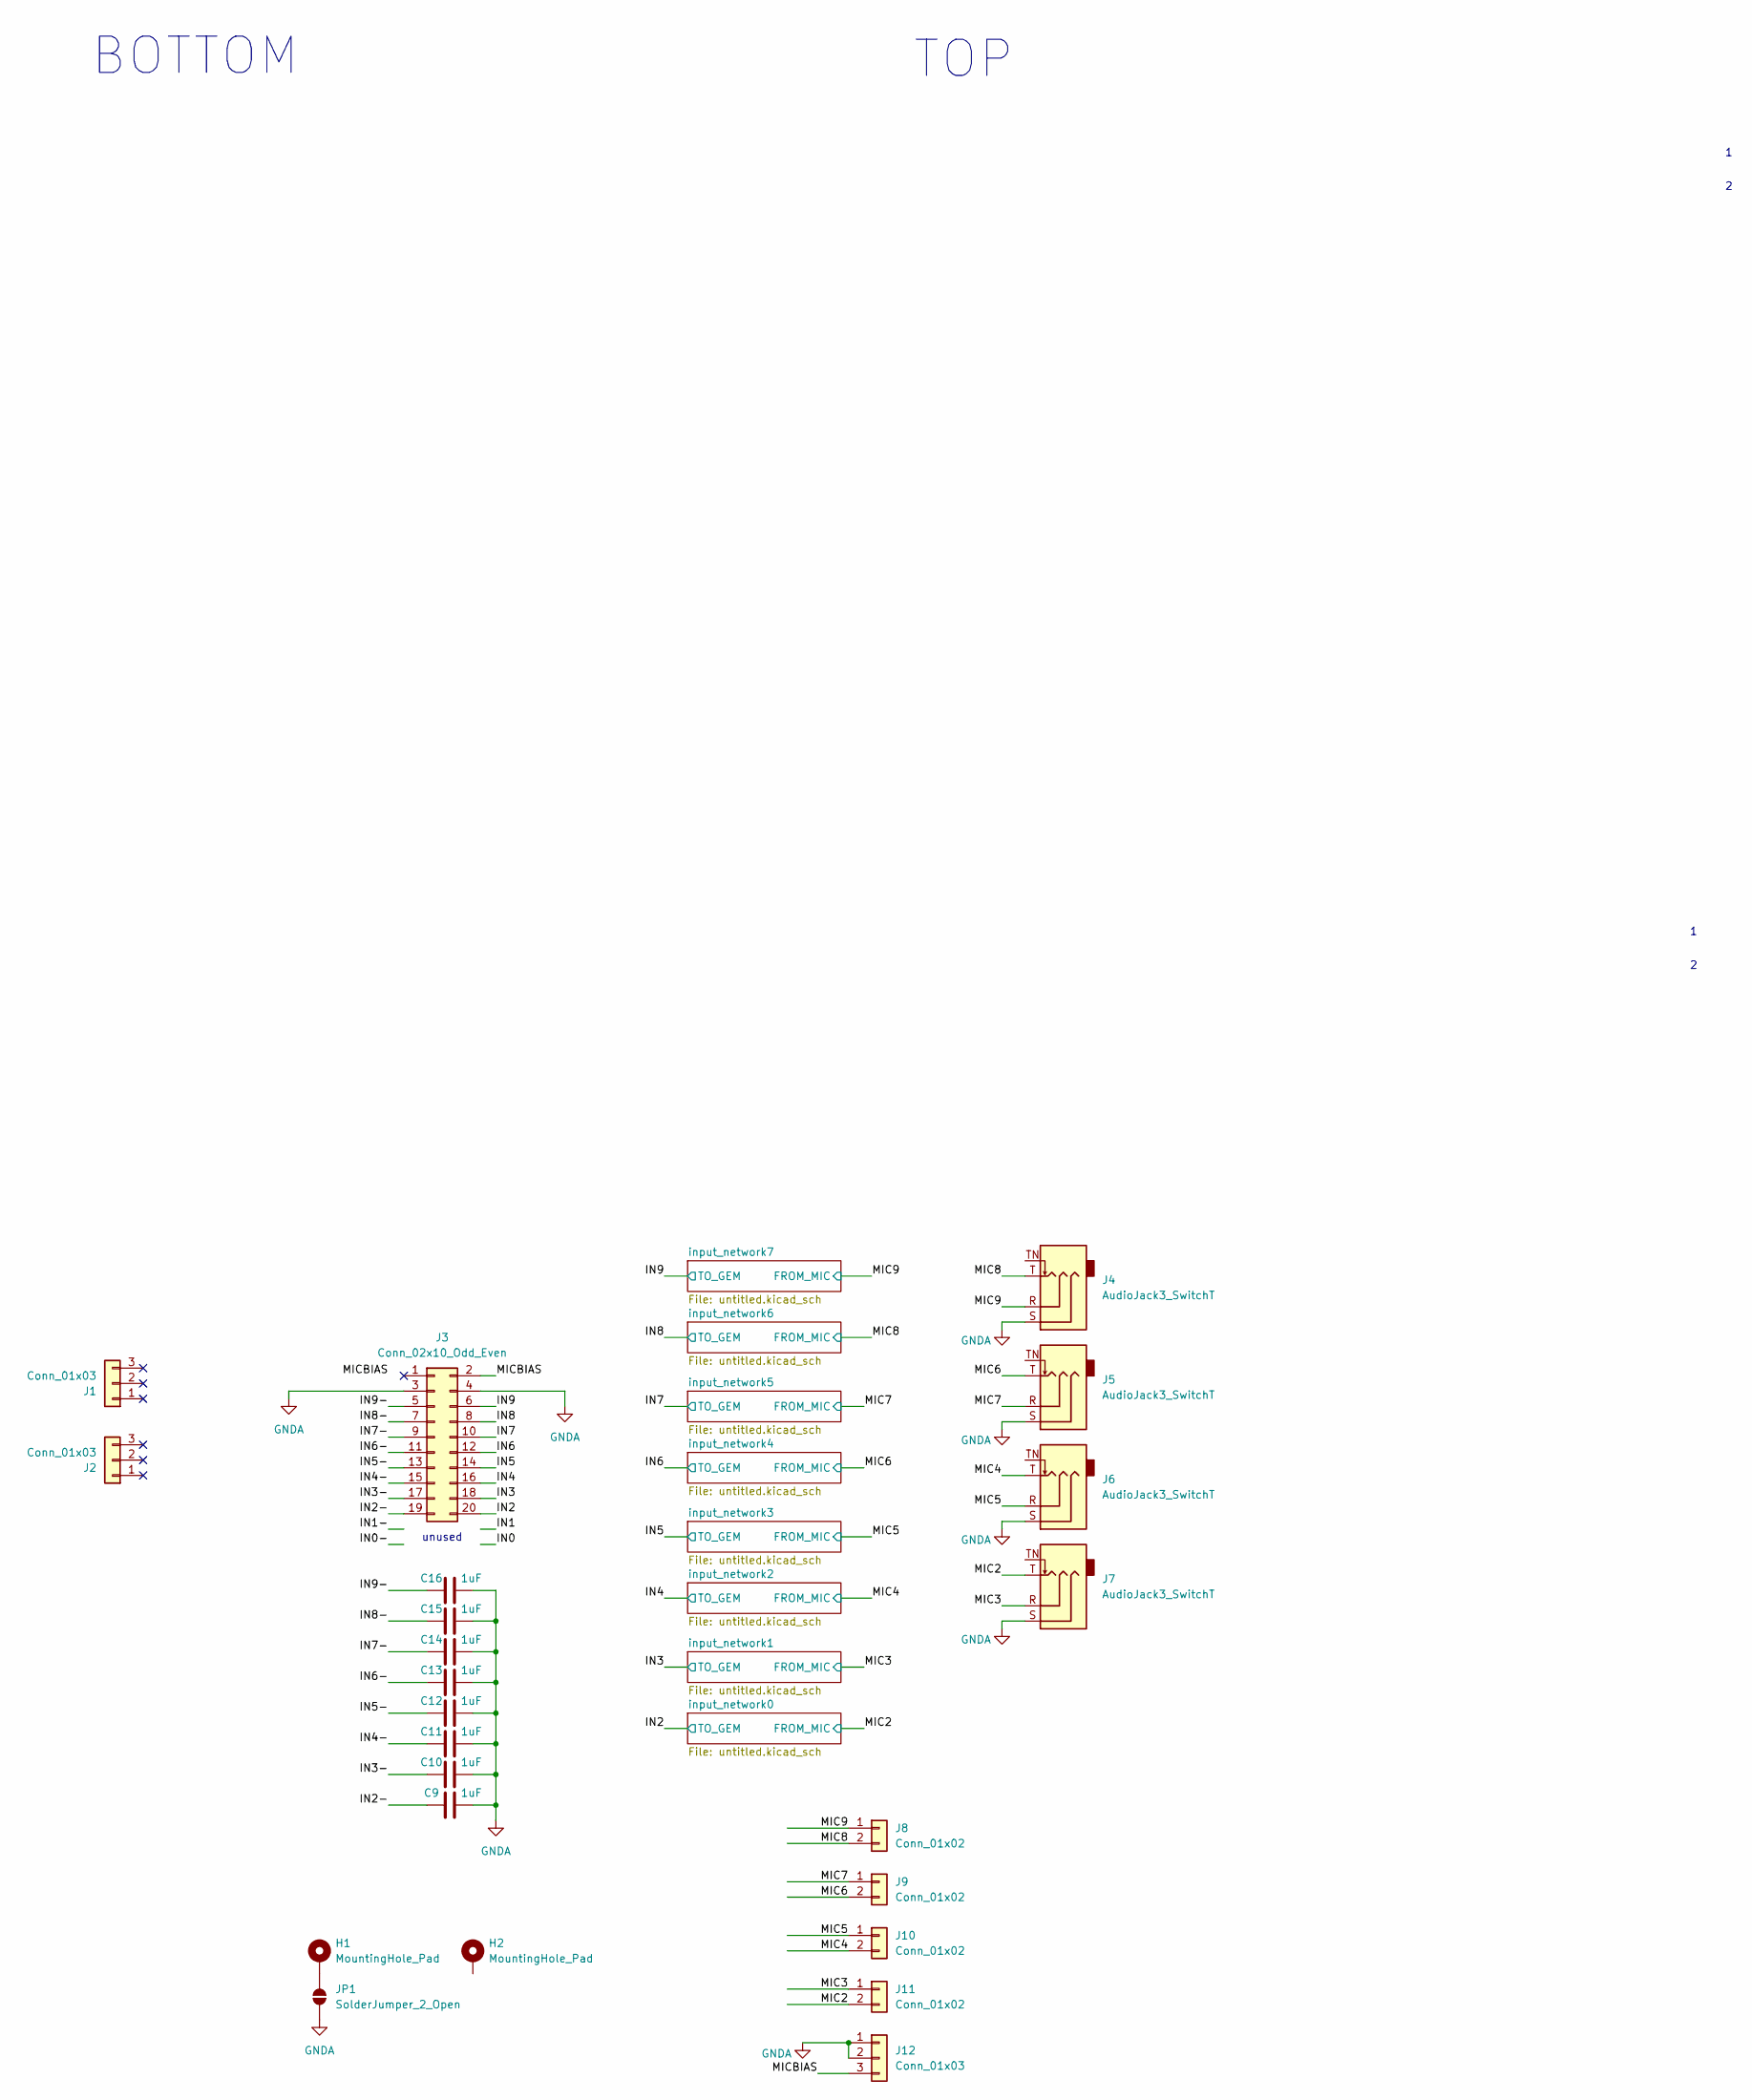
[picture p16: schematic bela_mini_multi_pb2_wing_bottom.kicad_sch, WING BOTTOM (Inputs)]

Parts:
C9, C10, C11, C12, C13, C14, C15, C16: 1uF; C_0402_1005Metric
H1, H2: MountingHole_Pad; MountingHole_3.2mm_M3_DIN965_Pad
J1, J2: Conn_01x03; PinHeader_1x03_P2.54mm_Vertical
J3: Conn_02x10_Odd_Even; PinHeader_2x10_P2.54mm_Vertical_SMD
J4, J5, J6, J7: AudioJack3_SwitchT; Jack_3.5mm_SameSky_SJ235813BSMTTR
J8, J9, J10, J11: Conn_01x02; PinSocket_1x02_P2.54mm_Vertical
J12: Conn_01x03; PinSocket_1x03_P2.54mm_Vertical
JP1: SolderJumper_2_Open; SolderJumper-2_P1.3mm_Open_RoundedPad1.0x1.5mm

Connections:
/IN2: J3.20; also elsewhere on the board
/IN2-: C9.1, J3.19
/IN3: J3.18; also elsewhere on the board
/IN3-: C10.1, J3.17
/IN4: J3.16; also elsewhere on the board
/IN4-: C11.1, J3.15
/IN5: J3.14; also elsewhere on the board
/IN5-: C12.1, J3.13
/IN6: J3.12; also elsewhere on the board
/IN6-: C13.1, J3.11
/IN7: J3.10; also elsewhere on the board
/IN7-: C14.1, J3.9
/IN8: J3.8; also elsewhere on the board
/IN8-: C15.1, J3.7
/IN9: J3.6; also elsewhere on the board
/IN9-: C16.1, J3.5
/MIC2: J7.T, J11.2; also elsewhere on the board
/MIC3: J7.R, J11.1; also elsewhere on the board
/MIC4: J6.T, J10.2; also elsewhere on the board
/MIC5: J6.R, J10.1; also elsewhere on the board
/MIC6: J5.T, J9.2; also elsewhere on the board
/MIC7: J5.R, J9.1; also elsewhere on the board
/MIC8: J4.T, J8.2; also elsewhere on the board
/MIC9: J4.R, J8.1; also elsewhere on the board
/MICBIAS: J3.2, J12.3
GNDA: C9.2, C10.2, C11.2, C12.2, C13.2, C14.2, C15.2, C16.2, J3.3, J3.4, J4.S, J5.S, J6.S, J7.S, J12.1, J12.2, JP1.1 (A)
unnamed: H1.1, JP1.2 (B)

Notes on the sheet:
BOTTOM
unused
TOP

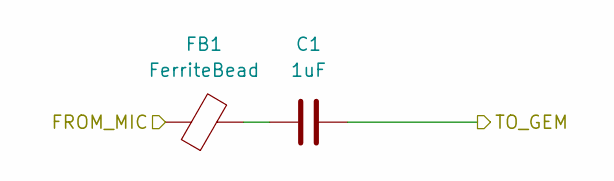
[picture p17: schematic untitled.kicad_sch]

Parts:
C1: 1uF; C_0402_1005Metric
FB1: FerriteBead; L_0402_1005Metric

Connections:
/IN2: C1.2; also elsewhere on the board
/MIC2: FB1.1; also elsewhere on the board
unnamed: C1.1, FB1.2

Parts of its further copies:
C2, C3, C4, C5, C6, C7, C8: 1uF; C_0402_1005Metric
FB2, FB3, FB4, FB5, FB6, FB7, FB8: FerriteBead; L_0402_1005Metric

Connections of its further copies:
/IN3: C2.2; also elsewhere on the board
/IN4: C3.2; also elsewhere on the board
/IN5: C4.2; also elsewhere on the board
/IN6: C5.2; also elsewhere on the board
/IN7: C6.2; also elsewhere on the board
/IN8: C7.2; also elsewhere on the board
/IN9: C8.2; also elsewhere on the board
/MIC3: FB2.1; also elsewhere on the board
/MIC4: FB3.1; also elsewhere on the board
/MIC5: FB4.1; also elsewhere on the board
/MIC6: FB5.1; also elsewhere on the board
/MIC7: FB6.1; also elsewhere on the board
/MIC8: FB7.1; also elsewhere on the board
/MIC9: FB8.1; also elsewhere on the board
unnamed: C2.1, FB2.2
unnamed: C3.1, FB3.2
unnamed: C4.1, FB4.2
unnamed: C5.1, FB5.2
unnamed: C6.1, FB6.2
unnamed: C7.1, FB7.2
unnamed: C8.1, FB8.2

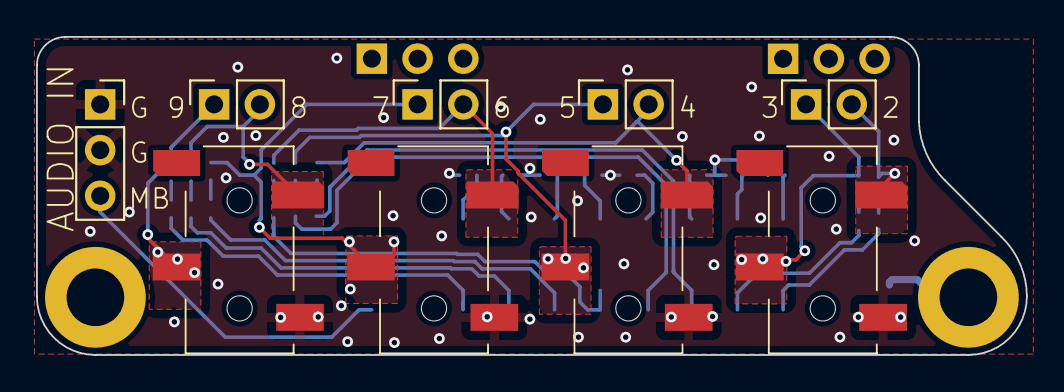
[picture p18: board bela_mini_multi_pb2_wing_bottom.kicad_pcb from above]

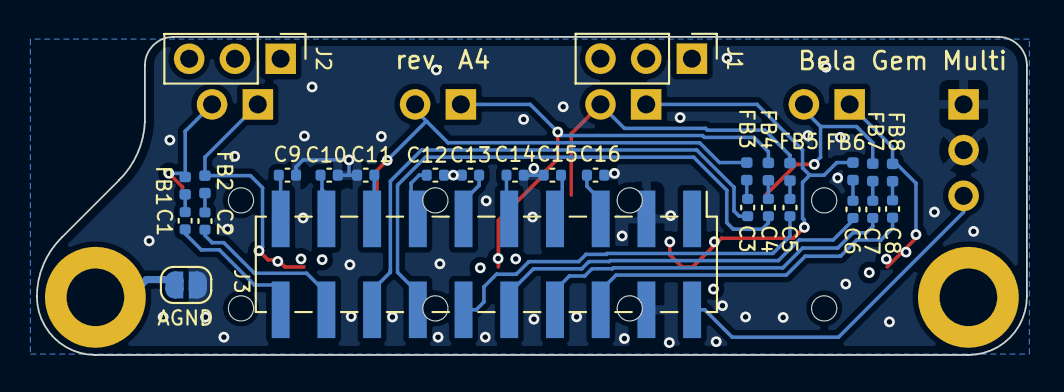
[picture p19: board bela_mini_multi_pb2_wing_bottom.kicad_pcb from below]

Board: 2 copper layers, 55.0 x 17.7 mm, 39 parts (28 on the bottom side), 35 nets.

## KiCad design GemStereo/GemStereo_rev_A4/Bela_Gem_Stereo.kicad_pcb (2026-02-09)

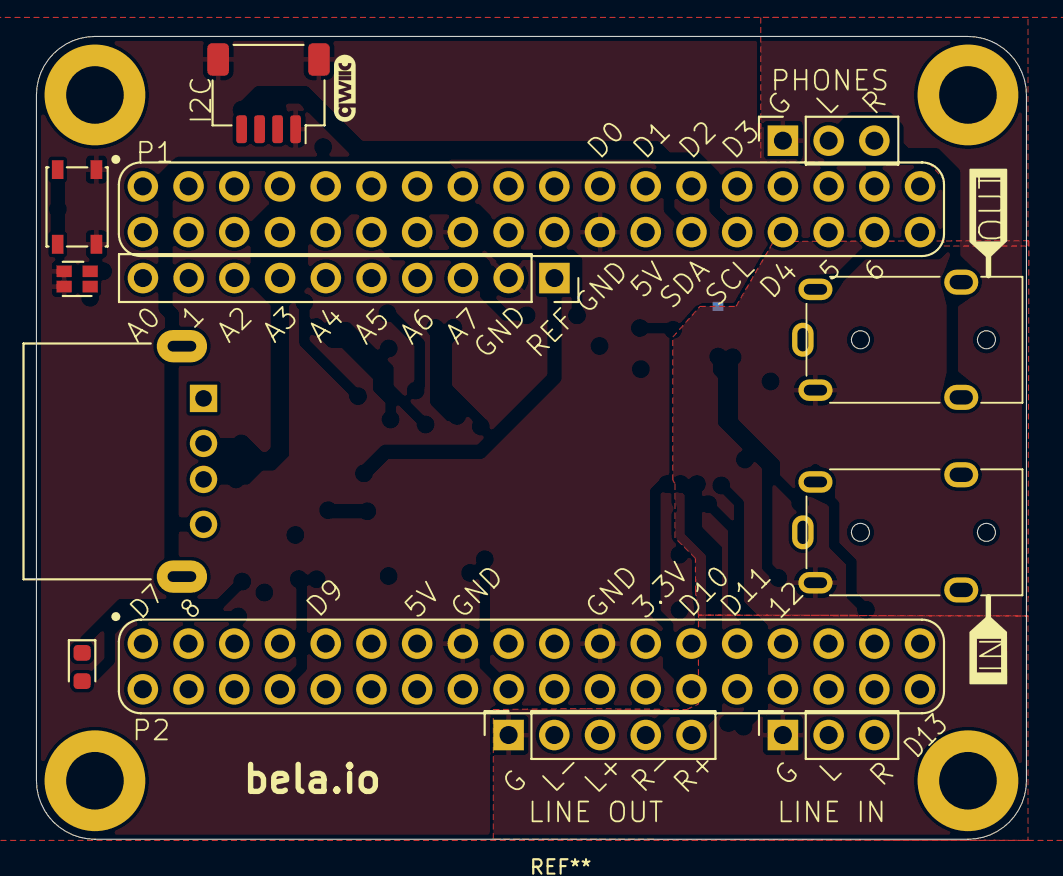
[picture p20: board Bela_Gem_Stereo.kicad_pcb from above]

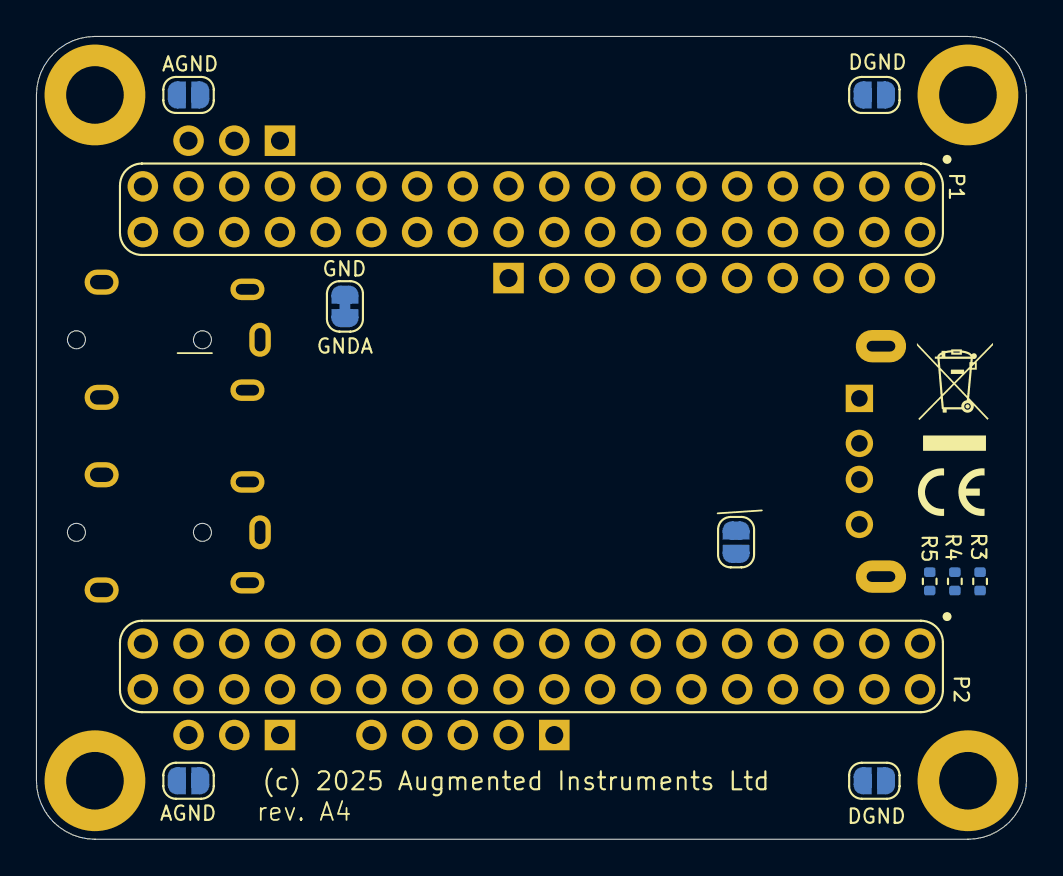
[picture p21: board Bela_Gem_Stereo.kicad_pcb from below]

Board: 4 copper layers, 55.0 x 44.6 mm, 26 parts (11 on the bottom side), 24 nets, no tracks yet.

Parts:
D1: LTST-C195TBJRKT; LED_LiteOn_LTST-C19HE1WT
D6: LED; LED_0603_1608Metric
G2: WEEE-Logo; WEEE-Logo_4.2x6mm_SilkScreen
H1, H2, H3, H4: MountingHole; MountingHole_3.2mm_M3_DIN965_Pad
J1, J2: Conn_01x03; PinSocket_1x03_P2.54mm_Vertical
J3: Conn_01x10; PinSocket_1x10_P2.54mm_Vertical
J5: USB_A; USB_A_GCT_USB1125
J6: Conn_01x04_MountingPin; qwiic_horizontal_SMD
J7, J8: AudioJack4; Jack_3.5mm_LumbergSubstitute
J9: Conn_01x05; PinSocket_1x05_P2.54mm_Vertical
JP1, JP2, JP3, JP4, JP5: SolderJumper_2_Open; SolderJumper-2_P1.3mm_Open_RoundedPad1.0x1.5mm
NT1: NetTie_2; SolderJumper-2_P1.3mm_Bridged_RoundedPad1.0x1.5mm
R3: 100; R_0402_1005Metric
R4, R5: 560; R_0402_1005Metric
S1: PTS810; SW_SPST_PTS810
U1: PocketBeagle2; PB2

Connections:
+3V3: J6.2, JP2.1 (A), U1.P1.14 (3.3V), U1.P2.23 (3.3V)
+5V: U1.P1.24 (VOUT), U1.P2.13 (VOUT)
/HPL: J2.2, J8.T
/HPR: J2.3, J8.R1
/I2C2.SCL: J6.4, U1.P1.28 (I2C2.SCL)
/I2C2.SDA: J6.3, U1.P1.26 (I2C2.SDA)
/INL: J1.2, J7.T
/INR: J1.3, J7.R1
/LED_INDICATOR_A: R4.1, U1.P2.2 (PRU1.0)
/LED_INDICATOR_B: R5.2, U1.P2.4 (PRU1.1)
/ON_OFF_BUTTON: R3.2, U1.P2.6 (PRU1.2)
/USBGND: J5.4 (GND), J5.5 (Shield), U1.P1.15 (GND)
/USB_DN: J5.2 (D-), U1.P1.9 (USB1.D-)
/USB_DP: J5.3 (D+), U1.P1.11 (USB1.D+)
/USB_VBUS: J5.1 (VBUS), U1.P1.5 (USB1.VBUS), U1.P1.7 (VIN.USB)
GND: D1.3 (K1), D1.4 (K2), J3.2, J6.1, J6.MP (MountPin), JP1.2 (B), JP4.2 (B), NT1.2, S1.1, U1.P1.16 (GND), U1.P1.22 (GND), U1.P2.15 (GND), U1.P2.21 (GND)
GNDA: J1.1, J2.1, J7.R2, J8.R2, J9.1, JP3.2 (B), JP5.2 (B), NT1.1
unnamed: D1.1 (A1), R5.1
unnamed: D1.2 (A2), R4.2
unnamed: H1.1, JP1.1 (A)
unnamed: H2.1, JP3.1 (A)
unnamed: H3.1, JP4.1 (A)
unnamed: H4.1, JP5.1 (A)
unnamed: R3.1, S1.2

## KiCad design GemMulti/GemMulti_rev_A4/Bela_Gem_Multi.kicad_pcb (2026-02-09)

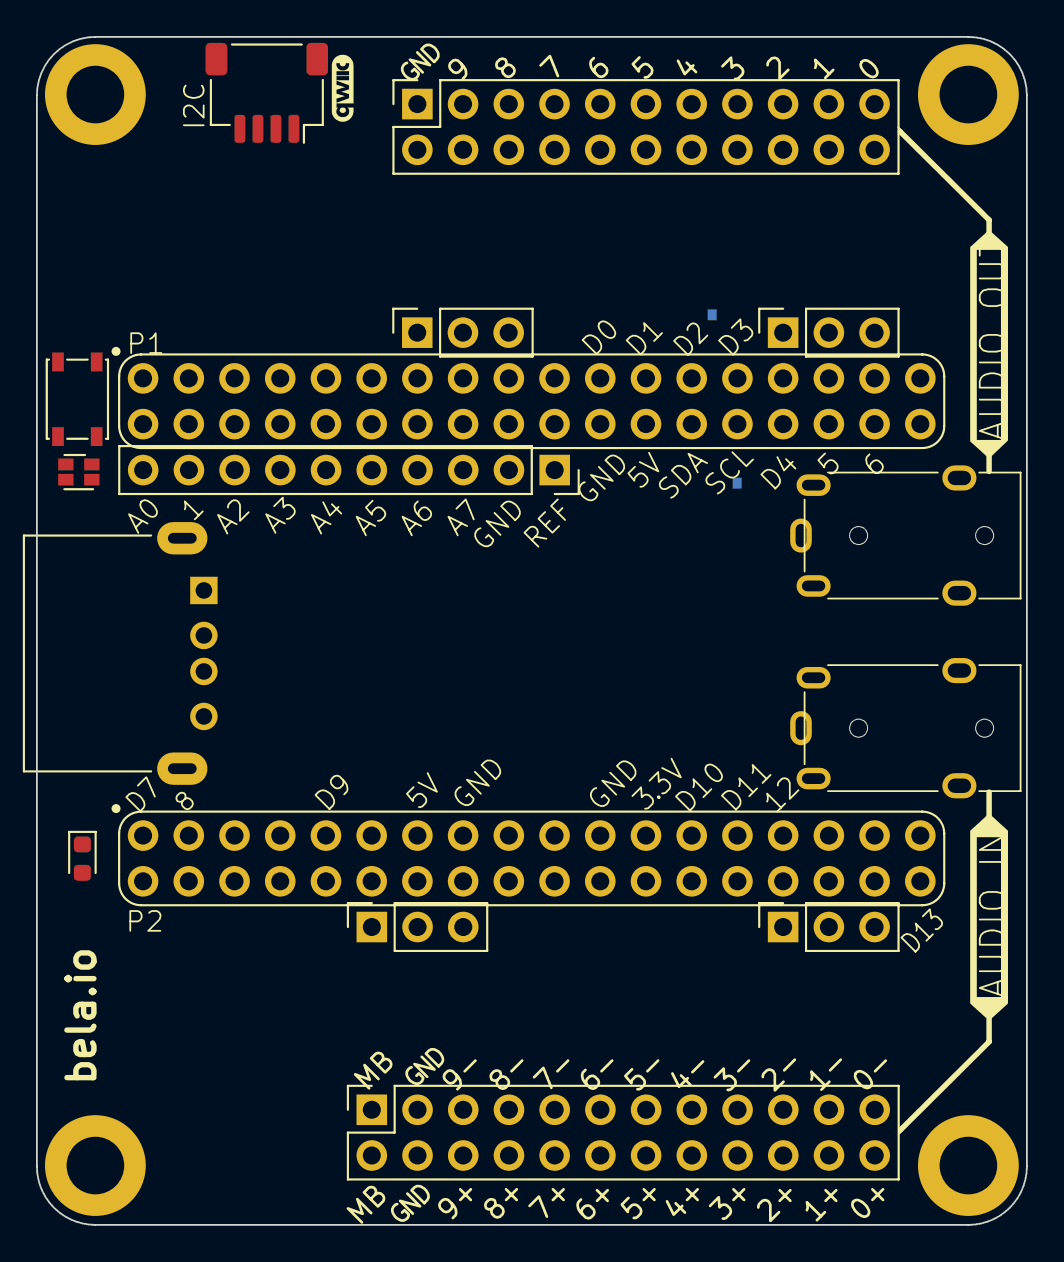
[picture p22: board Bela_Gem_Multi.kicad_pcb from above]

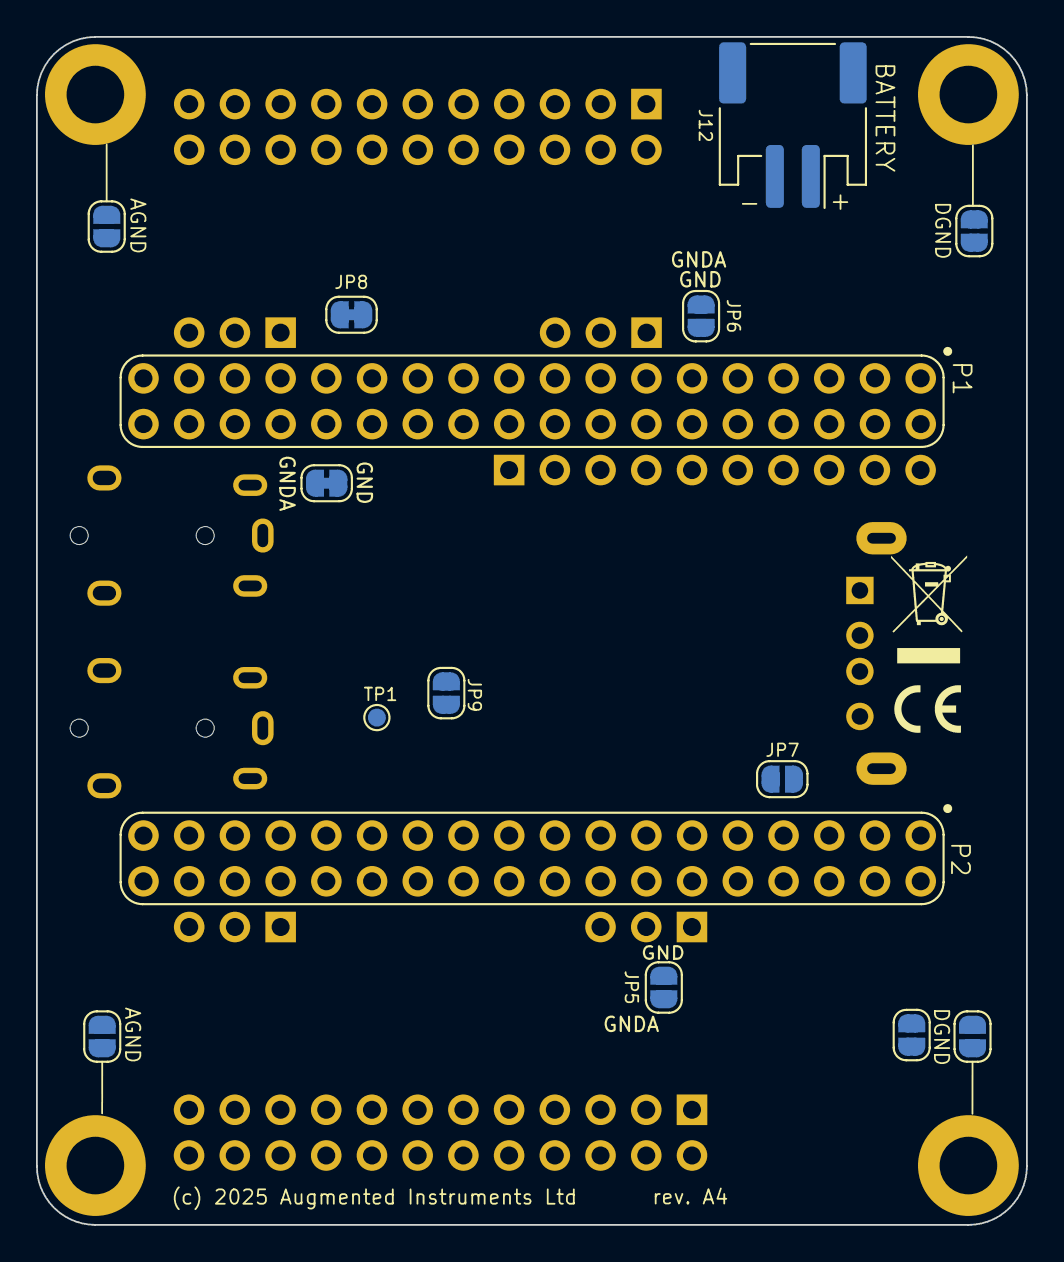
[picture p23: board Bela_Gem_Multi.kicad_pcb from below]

Board: 4 copper layers, 55.0 x 66.0 mm, 34 parts (15 on the bottom side), 21 nets, no tracks yet.

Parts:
D1: LTST-C195TBJRKT; LED_LiteOn_LTST-C19HE1WT
D24: LED; LED_0603_1608Metric
G1: OSHW-Logo; OSHW-Logo2_7.3x6mm_SilkScreen
G3: WEEE-Logo; WEEE-Logo_4.2x6mm_SilkScreen
H1, H2, H3, H4: MountingHole; MountingHole_3.2mm_M3_DIN965_Pad
J1, J2: AudioJack4; Jack_3.5mm_LumbergSubstitute
J3: Conn_01x10; PinSocket_1x10_P2.54mm_Vertical
J4: Conn_01x04_MountingPin; qwiic_horizontal_SMD
J5: USB_A; USB_A_GCT_USB1125
J6: Conn_02x12_Odd_Even; PinSocket_2x12_P2.54mm_Vertical
J7: Conn_02x11_Odd_Even; PinSocket_2x11_P2.54mm_Vertical
J8, J9, J10, J11: Conn_01x03; PinSocket_1x03_P2.54mm_Vertical
J12: Conn_01x02; JST_PH_S2B-PH-SM4-TB_1x02-1MP_P2.00mm_Horizontal
JP1, JP2, JP3, JP4, JP5, JP6, JP7, JP9, JP10: SolderJumper_2_Open; SolderJumper-2_P1.3mm_Open_RoundedPad1.0x1.5mm
JP8: SolderJumper_2_Bridged; SolderJumper-2_P1.3mm_Bridged_RoundedPad1.0x1.5mm
NT1: NetTie_2; SolderJumper-2_P1.3mm_Bridged_RoundedPad1.0x1.5mm
S1: PTS810; SW_SPST_PTS810
TP1: TestPoint; TestPoint_Pad_D1.0mm
U1: PocketBeagle2; PB2

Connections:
+3V3: J4.2, J8.2, JP7.1 (A), U1.P2.23 (3.3V)
+5V: J8.3, J10.3, U1.P1.24 (VOUT), U1.P2.13 (VOUT)
/BAT.VIN: J12.1, U1.P2.14 (BAT.VIN)
/HPL: J2.T, J11.2
/HPR: J2.R1, J11.3
/I2C2.SCL: J4.4, U1.P1.28 (I2C2.SCL)
/I2C2.SDA: J4.3, U1.P1.26 (I2C2.SDA)
/IN0: J1.T, J6.24
/IN1: J1.R1, J6.22
/MICBIAS: J6.1, J6.2
/USBGND: J5.4 (GND), J5.5 (Shield), U1.P1.15 (GND)
/USB_DN: J5.2 (D-), U1.P1.9 (USB1.D-)
/USB_DP: J5.3 (D+), U1.P1.11 (USB1.D+)
/USB_VBUS: J5.1 (VBUS), U1.P1.5 (USB1.VBUS), U1.P1.7 (VIN.USB)
ADC_RST/: JP8.1 (A), U1.P2.18 (GPIO53)
GND: D1.3 (K1), D1.4 (K2), J3.2, J4.1, J4.MP (MountPin), J8.1, J10.1, J12.2, JP1.2 (B), JP3.2 (B), JP5.2 (B), JP6.2 (B), JP10.2 (B), NT1.2, S1.1, U1.P1.16 (GND), U1.P1.22 (GND), U1.P2.15 (GND), U1.P2.21 (GND)
GNDA: J1.R2, J2.R2, J6.3, J6.4, J7.1, J7.2, J7.4, J7.6, J7.8, J7.10, J7.12, J7.14, J7.16, J7.18, J9.1, J9.2, J11.1, JP2.2 (B), JP4.2 (B), JP5.1 (A), JP6.1 (A), NT1.1
unnamed: H1.1, JP1.1 (A)
unnamed: H2.1, JP2.1 (A)
unnamed: H3.1, JP3.1 (A)
unnamed: H4.1, JP4.1 (A)

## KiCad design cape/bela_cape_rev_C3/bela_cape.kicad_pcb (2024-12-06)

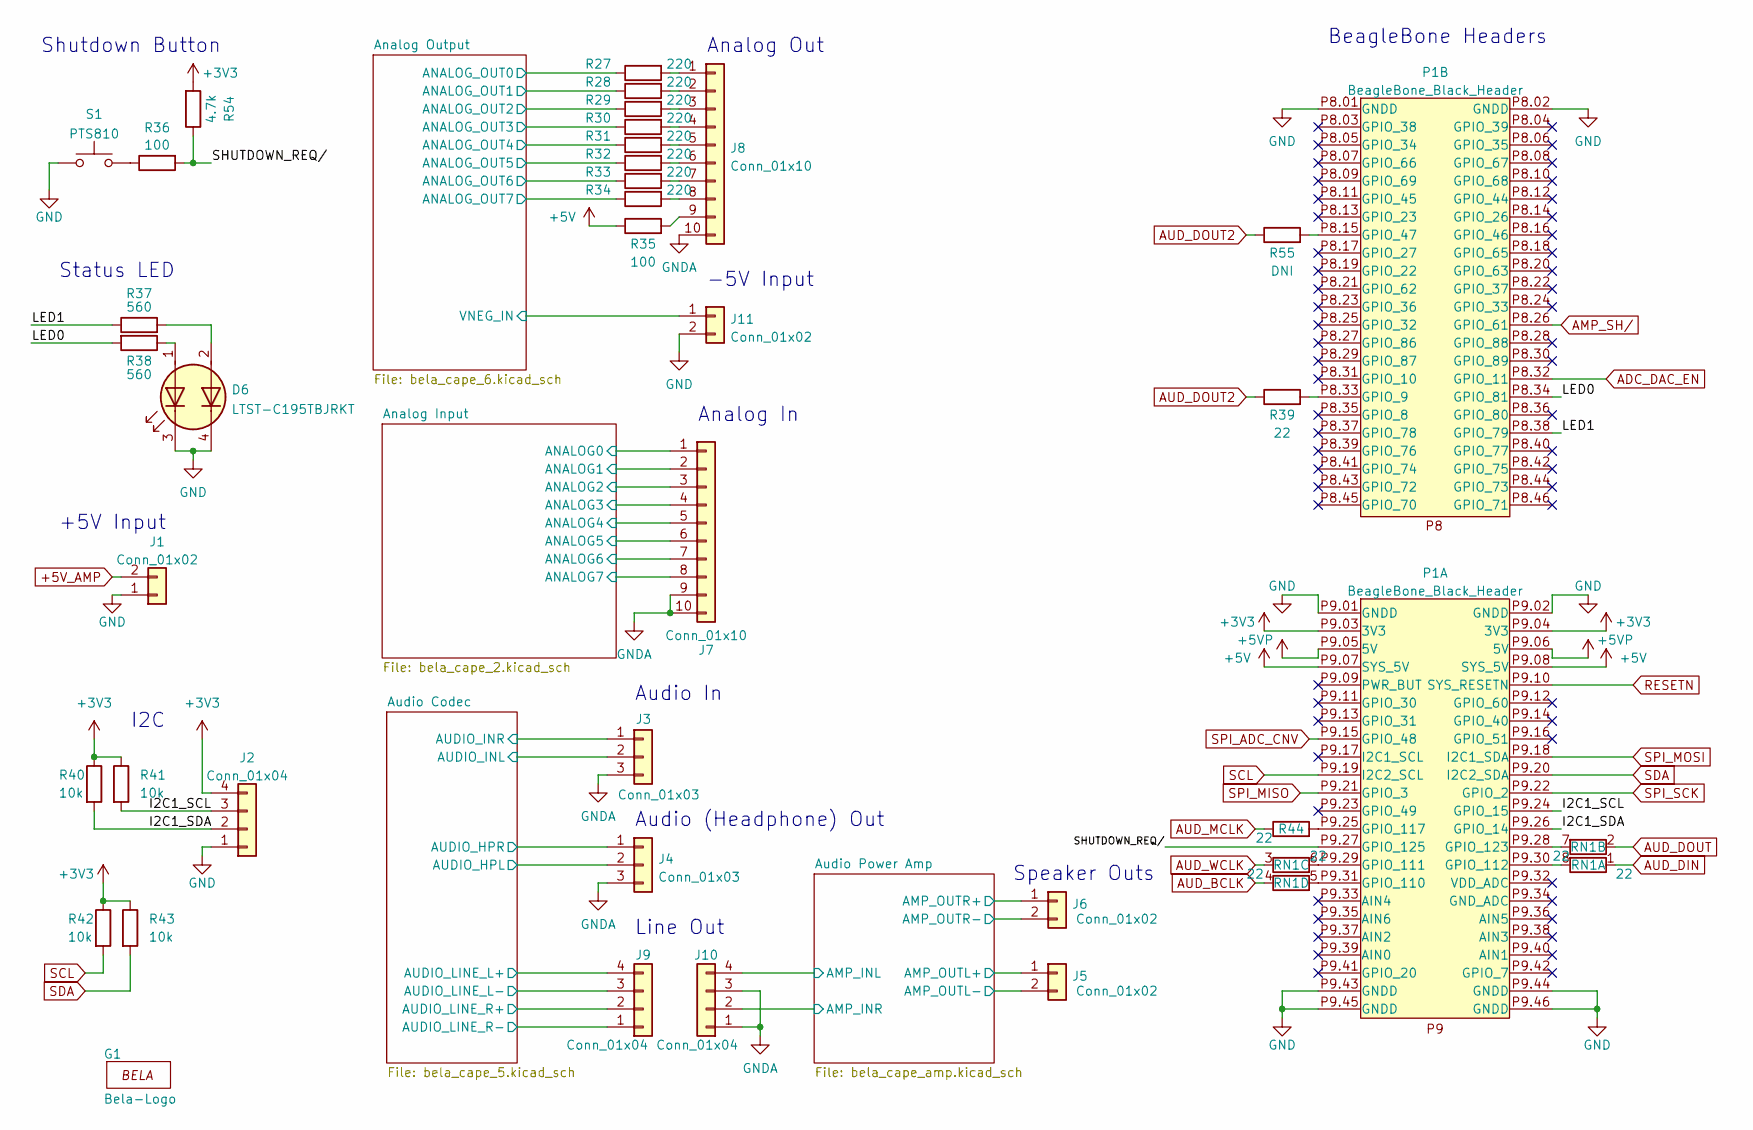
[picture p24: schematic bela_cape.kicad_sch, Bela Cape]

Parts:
D6: LTST-C195TBJRKT; LED_LiteOn_LTST-C19HE1WT
G1: Bela-Logo; Bela-Logo_30mm_Silkscreen
J1, J11: Conn_01x02; PinHeader_1x02_P2.54mm_Vertical
J2: Conn_01x04; Molex_KK-254_AE-6410-04A_1x04_P2.54mm_Vertical
J3, J4: Conn_01x03; Molex_KK-254_AE-6410-03A_1x03_P2.54mm_Vertical
J5, J6: Conn_01x02; Molex_KK-254_AE-6410-02A_1x02_P2.54mm_Vertical
J7, J8: Conn_01x10; PinHeader_1x10_P2.54mm_Vertical
J9, J10: Conn_01x04; PinHeader_1x04_P2.54mm_Vertical
P1: BeagleBone_Black_Header; BeagleBone_Black_Sockets_Board_outline
R27, R28, R29, R30, R31, R32, R33, R34: 220; R_0603_1608Metric
R35, R36: 100; R_0603_1608Metric
R37, R38: 560; R_0603_1608Metric
R39, R44: 22; R_0603_1608Metric
R40, R41, R42, R43: 10k; R_0603_1608Metric
R54: 4.7k; R_0603_1608Metric
R55: DNI; R_0603_1608Metric
RN1: 22; R_Array_Convex_4x0603
S1: PTS810; SW_SPST_PTS810

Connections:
+3V3: J2.4, P1.P9.03 (3V3), P1.P9.04 (3V3), R40.1, R41.1, R42.1, R43.1, R54.2; also elsewhere on the board
+5V: P1.P9.07 (SYS_5V), P1.P9.08 (SYS_5V), R35.1; also elsewhere on the board
+5VP: P1.P9.05 (5V), P1.P9.06 (5V); also elsewhere on the board
+5V_AMP: J1.2; also elsewhere on the board
/Analog Input/ANALOG0: J7.1; also elsewhere on the board
/Analog Input/ANALOG1: J7.2; also elsewhere on the board
/Analog Input/ANALOG2: J7.3; also elsewhere on the board
/Analog Input/ANALOG3: J7.4; also elsewhere on the board
/Analog Input/ANALOG4: J7.5; also elsewhere on the board
/Analog Input/ANALOG5: J7.6; also elsewhere on the board
/Analog Input/ANALOG6: J7.7; also elsewhere on the board
/Analog Input/ANALOG7: J7.8; also elsewhere on the board
/Analog Output/ANALOG_OUT0: R27.1; also elsewhere on the board
/Analog Output/ANALOG_OUT1: R28.1; also elsewhere on the board
/Analog Output/ANALOG_OUT2: R29.1; also elsewhere on the board
/Analog Output/ANALOG_OUT3: R30.1; also elsewhere on the board
/Analog Output/ANALOG_OUT4: R31.1; also elsewhere on the board
/Analog Output/ANALOG_OUT5: R32.1; also elsewhere on the board
/Analog Output/ANALOG_OUT6: R33.1; also elsewhere on the board
/Analog Output/ANALOG_OUT7: R34.1; also elsewhere on the board
/Analog Output/VNEG_IN: J11.1; also elsewhere on the board
/Audio Codec/AUDIO_HPL: J4.2; also elsewhere on the board
/Audio Codec/AUDIO_HPR: J4.1; also elsewhere on the board
/Audio Codec/AUDIO_INL: J3.2; also elsewhere on the board
/Audio Codec/AUDIO_INR: J3.1; also elsewhere on the board
/Audio Codec/AUDIO_LINE_L+: J9.4; also elsewhere on the board
/Audio Codec/AUDIO_LINE_L-: J9.3; also elsewhere on the board
/Audio Codec/AUDIO_LINE_R+: J9.2; also elsewhere on the board
/Audio Codec/AUDIO_LINE_R-: J9.1; also elsewhere on the board
/Audio Power Amp/AMP_INL: J10.4; also elsewhere on the board
/Audio Power Amp/AMP_INR: J10.2; also elsewhere on the board
/Audio Power Amp/AMP_OUTL+: J5.1; also elsewhere on the board
/Audio Power Amp/AMP_OUTL-: J5.2; also elsewhere on the board
/Audio Power Amp/AMP_OUTR+: J6.1; also elsewhere on the board
/Audio Power Amp/AMP_OUTR-: J6.2; also elsewhere on the board
/I2C1_SCL: J2.3, P1.P9.24 (GPIO_15), R41.2
/I2C1_SDA: J2.2, P1.P9.26 (GPIO_14), R40.2
/LED0: P1.P8.34 (GPIO_81), R38.2
/LED1: P1.P8.38 (GPIO_79), R37.1
/SHUTDOWN_REQ/: P1.P9.27 (GPIO_125), R36.2, R54.1
ADC_DAC_EN: P1.P8.32 (GPIO_11); also elsewhere on the board
AMP_SH/: P1.P8.26 (GPIO_61); also elsewhere on the board
AUD_BCLK: RN1.4 (R4.1); also elsewhere on the board
AUD_DIN: RN1.1 (R1.1); also elsewhere on the board
AUD_DOUT: RN1.2 (R2.1); also elsewhere on the board
AUD_DOUT2: R39.1, R55.1; also elsewhere on the board
AUD_MCLK: R44.1; also elsewhere on the board
AUD_WCLK: RN1.3 (R3.1); also elsewhere on the board
GND: D6.3 (K1), D6.4 (K2), J1.1, J2.1, J11.2, P1.P8.01 (GNDD), P1.P8.02 (GNDD), P1.P9.01 (GNDD), P1.P9.02 (GNDD), P1.P9.43 (GNDD), P1.P9.44 (GNDD), P1.P9.45 (GNDD), P1.P9.46 (GNDD), S1.2; also elsewhere on the board
GNDA: J3.3, J4.3, J7.9, J7.10, J8.10, J10.1, J10.3; also elsewhere on the board
unnamed: D6.1 (A1), R38.1
unnamed: D6.2 (A2), R37.2
unnamed: J8.1, R27.2
unnamed: J8.2, R28.2
unnamed: J8.3, R29.2
unnamed: J8.4, R30.2
unnamed: J8.5, R31.2
unnamed: J8.6, R32.2
unnamed: J8.7, R33.2
unnamed: J8.8, R34.2
unnamed: J8.9, R35.2
unnamed: P1.P8.15 (GPIO_47), R55.2
unnamed: P1.P8.33 (GPIO_9), R39.2
unnamed: P1.P9.25 (GPIO_117), R44.2
unnamed: P1.P9.28 (GPIO_123), RN1.7 (R2.2)
unnamed: P1.P9.29 (GPIO_111), RN1.6 (R3.2)
unnamed: P1.P9.30 (GPIO_112), RN1.8 (R1.2)
unnamed: P1.P9.31 (GPIO_110), RN1.5 (R4.2)
unnamed: R36.1, S1.1
RESETN: P1.P9.10 (SYS_RESETN); also elsewhere on the board
SCL: P1.P9.19 (I2C2_SCL), R42.2; also elsewhere on the board
SDA: P1.P9.20 (I2C2_SDA), R43.2; also elsewhere on the board
SPI_ADC_CNV: P1.P9.15 (GPIO_48); also elsewhere on the board
SPI_MISO: P1.P9.21 (GPIO_3); also elsewhere on the board
SPI_MOSI: P1.P9.18 (I2C1_SDA); also elsewhere on the board
SPI_SCK: P1.P9.22 (GPIO_2); also elsewhere on the board

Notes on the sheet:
Audio (Headphone) Out
Analog Out
I2C
Audio In
BeagleBone Headers
Analog In
Status LED
-5V Input
Shutdown Button
+5V Input
Line Out
Speaker Outs


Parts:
C8, C9: 47uF; C_1206_3216Metric
C10, C11, C20: 1uF; C_0603_1608Metric
C12, C13: 47pF; C_0603_1608Metric
C14, C17: 10uF; C_0603_1608Metric
C15, C16, C18, C19: 0.1uF; C_0603_1608Metric
D1, D2: PESD0603-240; D_0603_1608Metric
D3, D4: BAS70-04; SOT-23
FB2: MPZ1608S121ATAH0; L_0603_1608Metric
IC2: TLV320AIC3104; QFN-32-1EP_5x5mm_P0.5mm_EP3.3x3.3mm
IC3: MIC5317; SOT-23-5
JP2: SolderJumper_2_Bridged; SolderJumper-2_P1.3mm_Bridged_Pad1.0x1.5mm
R5, R6: 15; R_0603_1608Metric
R7, R8: 3.3k; R_0603_1608Metric
R9, R10: 220; R_0603_1608Metric
TP2: TestPoint; TestPoint_THTPad_D2.0mm_Drill1.0mm

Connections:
+1V8: C19.1, IC2.32 (DVDD), IC3.5 (OUT)
+3.3VA: C14.1, C15.1, C16.1, FB2.2, IC2.18 (DRVDD), IC2.24 (DRVDD2), IC2.25 (AVDD)
+3V3: C17.1, C18.1, C20.1, D3.2 (K), D4.2 (K), FB2.1, IC2.7 (IOVDD), IC3.1 (IN), IC3.3 (EN); also elsewhere on the board
/Audio Codec/AUDIO_HPL: D2.2 (A2), R6.1, R8.2; also elsewhere on the board
/Audio Codec/AUDIO_HPR: D1.2 (A2), R5.1, R7.2; also elsewhere on the board
/Audio Codec/AUDIO_INL: R10.2; also elsewhere on the board
/Audio Codec/AUDIO_INR: R9.2; also elsewhere on the board
/Audio Codec/AUDIO_LINE_L+: IC2.27 (LEFT_LOP); also elsewhere on the board
/Audio Codec/AUDIO_LINE_L-: IC2.28 (LEFT_LOM); also elsewhere on the board
/Audio Codec/AUDIO_LINE_R+: IC2.29 (RIGHT_LOP); also elsewhere on the board
/Audio Codec/AUDIO_LINE_R-: IC2.30 (RIGHT_LOM); also elsewhere on the board
/Audio Codec/AUD_HPLOUT: C9.1, IC2.19 (HPLOUT)
/Audio Codec/AUD_HPROUT: C8.1, IC2.23 (HPROUT)
/Audio Codec/LINE1LP: C11.1, D4.3 (common), IC2.14 (IN2L)
/Audio Codec/LINE1RP: C10.1, D3.3 (common), IC2.16 (IN2R)
/Audio Codec/MICBIAS: IC2.15 (MICBIAS), TP2.1
AUD_BCLK: IC2.2 (BCLK); also elsewhere on the board
AUD_DIN: IC2.5 (DOUT); also elsewhere on the board
AUD_DOUT: IC2.4 (DIN); also elsewhere on the board
AUD_MCLK: IC2.1 (MCLK); also elsewhere on the board
AUD_WCLK: IC2.3 (WCLK); also elsewhere on the board
GND: JP2.1 (A); also elsewhere on the board
GNDA: C12.1, C13.1, C14.2, C15.2, C16.2, C17.2, C18.2, C19.2, C20.2, D1.1 (A1), D2.1 (A1), D3.1 (A), D4.1 (A), IC2.6 (DVSS), IC2.17 (AVSS_ADC), IC2.21 (DRVSS), IC2.26 (AVSS_DAC), IC2.33 (EP), IC3.2 (GND), JP2.2 (B), R7.1, R8.1; also elsewhere on the board
unnamed: C8.2, R5.2
unnamed: C9.2, R6.2
unnamed: C10.2, C12.2, R9.1
unnamed: C11.2, C13.2, R10.1
RESETN: IC2.31 (~RESET); also elsewhere on the board
SCL: IC2.8 (SCL); also elsewhere on the board
SDA: IC2.9 (SDA); also elsewhere on the board

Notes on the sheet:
Audio (Headphone) Out
Audio In
Audio Codec


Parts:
C1: 47uF; C_1206_3216Metric
C2, C3, C4: 0.1uF; C_0603_1608Metric
C5, C6, C7: 1uF; C_0603_1608Metric
FB1: MPZ1608S121ATAH0; L_0603_1608Metric
IC1: PAM8406; SO-16_3.9x9.9mm_P1.27mm
JP1: SolderJumper_2_Bridged; SolderJumper-2_P1.3mm_Bridged_Pad1.0x1.5mm
R1, R2: 51k; R_0603_1608Metric
R3, R4: 100k; R_0603_1608Metric

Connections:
+5VP: FB1.2; also elsewhere on the board
+5V_AMP: C1.1, C2.2, C3.2, C4.2, FB1.1, IC1.4 (PVDDL), IC1.6 (VDD), IC1.13 (PVDDR), R4.1; also elsewhere on the board
/Audio Power Amp/AMP_INL: C5.2; also elsewhere on the board
/Audio Power Amp/AMP_INR: C7.2; also elsewhere on the board
/Audio Power Amp/AMP_OUTL+: IC1.1 (LOUT+); also elsewhere on the board
/Audio Power Amp/AMP_OUTL-: IC1.3 (LOUT-); also elsewhere on the board
/Audio Power Amp/AMP_OUTR+: IC1.16 (ROUT+); also elsewhere on the board
/Audio Power Amp/AMP_OUTR-: IC1.14 (ROUT-); also elsewhere on the board
AMP_SH/: IC1.5 (~MUTE), IC1.12 (~SHDN), R3.1; also elsewhere on the board
GNDA: C1.2, C2.1, C3.1, C4.1, C6.2, IC1.2 (PGNDL), IC1.11 (GND), IC1.15 (PGNDR), JP1.1 (A), R3.2; also elsewhere on the board
unnamed: C5.1, R1.2
unnamed: C6.1, IC1.8 (VREF)
unnamed: C7.1, R2.2
unnamed: IC1.7 (INL), R1.1
unnamed: IC1.9 (MODE), JP1.2 (B), R4.2
unnamed: IC1.10 (INR), R2.1


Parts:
C21, C22, C26, C27, C30, C31, C35, C36: 22nF; C_0603_1608Metric
C23, C24, C25, C28, C29, C32, C34, C38: 1uF; C_0603_1608Metric
C33: 4.7uF; C_0603_1608Metric
C37: 2.2uF, 10V; C_0603_1608Metric
C39: 10uF, 10V; C_0603_1608Metric
C40, C41: 0.1uF; C_0603_1608Metric
C42: 47uF; C_0603_1608Metric
D5: BAS70-06; SOT-23
IC4, IC5: MC33204; TSSOP-14_4.4x5mm_P0.65mm
IC6: ES9080Q; QFN40P500X500X80-41N-D; Manufacturer_Part_Number ES9080Q
J12, J13, J14, J15: Conn_01x03; PinHeader_1x03_P2.54mm_Vertical
JP3, JP4, JP6: SolderJumper_2_Bridged; SolderJumper-2_P1.3mm_Bridged_Pad1.0x1.5mm
R11, R13, R15, R17, R19, R21, R23, R25: 22k/0.5%; R_0603_1608Metric
R12, R14, R16, R18, R20, R22, R24, R26: 16.9k/0.5%; R_0603_1608Metric
R46, R47, R48, R49, R50, R51, R52, R53: 330; R_0603_1608Metric

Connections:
+3V3: C23.2, C24.2, C28.2, C29.2, C38.2, IC6.2 (AVDD), IC6.3 (VCCA), IC6.10 (AVCC_3V3_L), IC6.18 (AVCC_CP), IC6.21 (AVCC_3V3_R); also elsewhere on the board
+5V: C40.2, C41.2, IC4.4 (V+), IC5.4 (V+); also elsewhere on the board
/Analog Output/ANALOG_OUT0: IC4.1, R12.2; also elsewhere on the board
/Analog Output/ANALOG_OUT1: IC4.8, R16.2; also elsewhere on the board
/Analog Output/ANALOG_OUT2: IC4.7, R20.2; also elsewhere on the board
/Analog Output/ANALOG_OUT3: IC4.14, R24.2; also elsewhere on the board
/Analog Output/ANALOG_OUT4: IC5.1, R14.2; also elsewhere on the board
/Analog Output/ANALOG_OUT5: IC5.8, R18.2; also elsewhere on the board
/Analog Output/ANALOG_OUT6: IC5.7, R22.2; also elsewhere on the board
/Analog Output/ANALOG_OUT7: IC5.14, R26.2; also elsewhere on the board
/Analog Output/DAC0: C21.2, IC4.3 (+), J12.2, R46.1
/Analog Output/DAC1: C22.2, IC4.10 (+), J14.2, R47.2
/Analog Output/DAC2: C26.2, IC4.5 (+), J12.1, R48.1
/Analog Output/DAC3: C27.2, IC4.12 (+), J14.1, R49.2
/Analog Output/DAC4: C30.2, IC5.3 (+), J13.2, R50.1
/Analog Output/DAC5: C31.2, IC5.10 (+), J15.2, R51.2
/Analog Output/DAC6: C35.2, IC5.5 (+), J13.1, R52.1
/Analog Output/DAC7: C36.2, IC5.12 (+), J15.1, R53.2
/Analog Output/DAC_OPAMP_V-: C39.1, C40.1, C41.1, D5.3 (A), IC4.11 (V-), IC5.11 (V-)
/Analog Output/PNEG: C42.2, IC6.15 (PNEG), JP4.1 (A)
/Analog Output/VNEG_IN: D5.1 (K); also elsewhere on the board
ADC_DAC_EN: IC6.27 (CHIP_EN); also elsewhere on the board
AUD_BCLK: IC6.38 (DATA_CLK), JP6.2 (B); also elsewhere on the board
AUD_DOUT2: IC6.36 (DATA2); also elsewhere on the board
AUD_WCLK: IC6.37 (DATA1); also elsewhere on the board
GND: C23.1, C25.1, IC6.28 (RT1), IC6.40 (DGND), IC6.41 (EP), JP3.1 (A); also elsewhere on the board
GNDA: C21.1, C22.1, C24.1, C26.1, C27.1, C28.1, C29.1, C30.1, C31.1, C32.1, C33.1, C34.1, C35.1, C36.1, C38.1, C39.2, C42.1, IC6.4 (AGND), IC6.7 (GND_SNS_L), IC6.12 (AGND_L), IC6.14 (AGND_CP), IC6.19 (AGND_R), IC6.24 (GND_SNS_R), J12.3, J13.3, J14.3, J15.3, JP3.2 (B), R11.1, R13.1, R15.1, R17.1, R19.1, R21.1, R23.1, R25.1; also elsewhere on the board
unnamed: C25.2, IC6.1 (DVDD)
unnamed: C32.2, IC6.11 (AVCC_L)
unnamed: C33.2, IC6.13 (BG_VREF)
unnamed: C34.2, IC6.20 (AVCC_R)
unnamed: C37.1, IC6.16 (C2)
unnamed: C37.2, IC6.17 (C1)
unnamed: D5.2 (K), JP4.2 (B)
unnamed: IC4.2 (-), R11.2, R12.1
unnamed: IC4.6 (-), R19.2, R20.1
unnamed: IC4.9 (-), R15.2, R16.1
unnamed: IC4.13 (-), R23.2, R24.1
unnamed: IC5.2 (-), R13.2, R14.1
unnamed: IC5.6 (-), R21.2, R22.1
unnamed: IC5.9 (-), R17.2, R18.1
unnamed: IC5.13 (-), R25.2, R26.1
unnamed: IC6.5 (OUT1), R46.2
unnamed: IC6.6 (OUT3), R48.2
unnamed: IC6.8 (OUT5), R50.2
unnamed: IC6.9 (OUT7), R52.2
unnamed: IC6.22 (OUT8), R53.1
unnamed: IC6.23 (OUT6), R51.1
unnamed: IC6.25 (OUT4), R49.1
unnamed: IC6.26 (OUT2), R47.1
unnamed: IC6.39 (MCLK/GPIO1/DATA8), JP6.1 (A)
SCL: IC6.29 (SCL_SLAVE); also elsewhere on the board
SDA: IC6.30 (SDA_SLAVE); also elsewhere on the board

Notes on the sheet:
Buffering / Level shifting
${TODO} if we need to use a separate data pin from the MCASP0_AXR2 currently used by the TLV codec, preferrably use MCASP0_AXR3_ALT pin P8.33 to avoid using MCASP0_AXR3 on P9.27 (currently Bela button). P8.33 is a boot pin with a 100k pulldown, so we should ensure this doesn't affect signal quality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
Op-amp negative rail select


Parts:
C43, C44, C45, C47: 0.1uF; C_0603_1608Metric
C46, C49, C50: 10uF; C_0603_1608Metric
C48, C51, C52: 1uF; C_0603_1608Metric
FB3: MPZ1608S121ATAH0; L_0603_1608Metric
IC7, IC8: TSV524xIQ4T; QFN-16-1EP_3x3mm_P0.5mm_EP1.7x1.7mm
IC9: ADS8168; VQFN-32-1EP_5x5mm_P0.5mm_EP3.5x3.5mm
JP5: SolderJumper_2_Bridged; SolderJumper2_with_mask
R45: 10k; R_0603_1608Metric
RN2: 22; R_Array_Convex_4x0603
TP1: TestPoint; TestPoint_THTPad_D2.0mm_Drill1.0mm

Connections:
+3V3: C47.2, IC9.30 (DVDD); also elsewhere on the board
+5V: FB3.2; also elsewhere on the board
/Analog Input/5V_ANALOG: C43.2, C44.2, C45.2, C46.2, FB3.1, IC7.2 (V+), IC8.2 (V+), IC9.32 (AVDD)
/Analog Input/ANALOG0: IC7.12 (+); also elsewhere on the board
/Analog Input/ANALOG1: IC7.9 (+); also elsewhere on the board
/Analog Input/ANALOG2: IC7.4 (+); also elsewhere on the board
/Analog Input/ANALOG3: IC7.1 (+); also elsewhere on the board
/Analog Input/ANALOG4: IC8.12 (+); also elsewhere on the board
/Analog Input/ANALOG5: IC8.9 (+); also elsewhere on the board
/Analog Input/ANALOG6: IC8.4 (+); also elsewhere on the board
/Analog Input/ANALOG7: IC8.1 (+); also elsewhere on the board
/Analog Input/REFP: C49.1, C50.1, IC9.5 (REFP), IC9.6 (REFP), TP1.1
ADC_DAC_EN: IC9.29 (RST/), R45.2; also elsewhere on the board
GND: JP5.1 (A), R45.1; also elsewhere on the board
GNDA: C43.1, C44.1, C45.1, C46.1, C47.1, C48.2, C49.2, C50.2, C51.2, C52.2, IC7.11 (V-), IC7.17 (EP), IC8.11 (V-), IC8.17 (EP), IC9.1 (GND), IC9.4 (REFM), IC9.8 (AIN-COM), IC9.21 (GND), IC9.31 (GND), IC9.33 (GND), JP5.2 (B); also elsewhere on the board
unnamed: C48.1, IC9.7 (REFBY2)
unnamed: C51.1, IC9.3 (REFIO)
unnamed: C52.1, IC9.2 (DECAP)
unnamed: IC7.5 (-), IC7.6, IC9.11 (AIN2)
unnamed: IC7.7, IC7.8 (-), IC9.10 (AIN1)
unnamed: IC7.13 (-), IC7.14, IC9.9 (AIN0)
unnamed: IC7.15, IC7.16 (-), IC9.12 (AIN3)
unnamed: IC8.5 (-), IC8.6, IC9.15 (AIN6)
unnamed: IC8.7, IC8.8 (-), IC9.14 (AIN5)
unnamed: IC8.13 (-), IC8.14, IC9.13 (AIN4)
unnamed: IC8.15, IC8.16 (-), IC9.16 (AIN7)
unnamed: IC9.17 (ADC-INP), IC9.18 (MUXOUT-P)
unnamed: IC9.19 (MUXOUT-M), IC9.20 (ADC-INM)
unnamed: IC9.23 (CS/), RN2.4 (R4.1)
unnamed: IC9.24 (SDI), RN2.3 (R3.1)
unnamed: IC9.25 (SCLK), RN2.2 (R2.1)
unnamed: IC9.26 (SDO-0), RN2.1 (R1.1)
SPI_ADC_CNV: RN2.5 (R4.2); also elsewhere on the board
SPI_MISO: RN2.8 (R1.2); also elsewhere on the board
SPI_MOSI: RN2.6 (R3.2); also elsewhere on the board
SPI_SCK: RN2.7 (R2.2); also elsewhere on the board

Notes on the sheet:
Analog In



Board: 4 copper layers, 71.8 x 54.6 mm, 153 parts (128 on the bottom side), 146 nets.

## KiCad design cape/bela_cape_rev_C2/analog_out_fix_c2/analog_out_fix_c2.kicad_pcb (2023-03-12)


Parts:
C1, C2, C3, C4: 22nF; C_0603_1608Metric
J1, J2: Conn_01x03; PinHeader_1x03_P2.54mm_Vertical

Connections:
GND: C1.2, C2.2, C3.1, C4.2, J1.3, J2.3
unnamed: C1.1, J1.2
unnamed: C2.1, J2.2
unnamed: C3.2, J1.1
unnamed: C4.1, J2.1



Board: 2 copper layers, 8.1 x 10.4 mm, 6 parts (4 on the bottom side), 5 nets.

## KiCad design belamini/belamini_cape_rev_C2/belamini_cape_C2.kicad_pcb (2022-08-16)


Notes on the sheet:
Analog Ins
Audio and Interface

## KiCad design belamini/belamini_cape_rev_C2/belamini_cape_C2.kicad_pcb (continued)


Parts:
C1, C4, C5: 0.1uF; C_0603_1608Metric
C2, C20, C21: 10uF; C_0603_1608Metric
C3, C10, C11: 1uF; C_0603_1608Metric
FB1: MPZ1608S121ATAH0; L_0603_1608Metric
IC1, IC2: TSV524xIQ4T; QFN-16-1EP_3x3mm_P0.5mm_EP1.7x1.7mm
IC3: ADS8168; VQFN-32-1EP_5x5mm_P0.5mm_EP3.5x3.5mm
J1: Conn_01x10; PinHeader_1x10_P2.54mm_Vertical
R12: 10k; R_0603_1608Metric
RN1: 22; R_Array_Concave_4x0603

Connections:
+3V3: C4.2, IC3.30 (DVDD); also elsewhere on the board
+5V: FB1.2; also elsewhere on the board
/belamini_cape_C2_1/5V_ANALOG: C1.2, C2.2, C5.2, FB1.1, IC1.2 (V+), IC2.2 (V+), IC3.32 (AVDD)
/belamini_cape_C2_1/REFP: C20.1, C21.1, IC3.5 (REFP), IC3.6 (REFP), J1.1
ADC_RST/: IC3.29 (RST/), R12.2; also elsewhere on the board
GND: C1.1, C2.1, C3.2, C4.1, C5.1, C10.2, C11.2, C20.2, C21.2, IC1.11 (V-), IC1.17 (EP), IC2.11 (V-), IC2.17 (EP), IC3.1 (GND), IC3.4 (REFM), IC3.8 (AIN-COM), IC3.21 (GND), IC3.31 (GND), IC3.33 (GND), J1.2, R12.1; also elsewhere on the board
unnamed: C3.1, IC3.2 (DECAP)
unnamed: C10.1, IC3.3 (REFIO)
unnamed: C11.1, IC3.7 (REFBY2)
unnamed: IC1.1 (+), J1.8
unnamed: IC1.4 (+), J1.7
unnamed: IC1.5 (-), IC1.6, IC3.12 (AIN3)
unnamed: IC1.7, IC1.8 (-), IC3.9 (AIN0)
unnamed: IC1.9 (+), J1.10
unnamed: IC1.12 (+), J1.9
unnamed: IC1.13 (-), IC1.14, IC3.10 (AIN1)
unnamed: IC1.15, IC1.16 (-), IC3.11 (AIN2)
unnamed: IC2.1 (+), J1.6
unnamed: IC2.4 (+), J1.5
unnamed: IC2.5 (-), IC2.6, IC3.14 (AIN5)
unnamed: IC2.7, IC2.8 (-), IC3.15 (AIN6)
unnamed: IC2.9 (+), J1.4
unnamed: IC2.12 (+), J1.3
unnamed: IC2.13 (-), IC2.14, IC3.16 (AIN7)
unnamed: IC2.15, IC2.16 (-), IC3.13 (AIN4)
unnamed: IC3.17 (ADC-INP), IC3.18 (MUXOUT-P)
unnamed: IC3.19 (MUXOUT-M), IC3.20 (ADC-INM)
unnamed: IC3.23 (CS/), RN1.4 (R4.1)
unnamed: IC3.24 (SDI), RN1.3 (R3.1)
unnamed: IC3.25 (SCLK), RN1.2 (R2.1)
unnamed: IC3.26 (SDO-0), RN1.1 (R1.1)
SPI_ADC_CNV: RN1.5 (R4.2); also elsewhere on the board
SPI_MISO: RN1.8 (R1.2); also elsewhere on the board
SPI_MOSI: RN1.6 (R3.2); also elsewhere on the board
SPI_SCK: RN1.7 (R2.2); also elsewhere on the board

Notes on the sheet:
Analog In


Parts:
C6, C16, C17: 0.1uF; C_0603_1608Metric
C7, C14, C15: 1uF; C_0603_1608Metric
C8, C9: 47uF; C_1206_3216Metric
C12, C13: 47pF; C_0603_1608Metric
C18, C19: 10uF; C_0603_1608Metric
D1, D2: PESD0603-240; D_0603_1608Metric
D3, D4: BAS70-04; SOT-23
D5: LTST-C195TBJRKT; LED_LiteOn_LTST-C19HE1WT
FB2: MPZ1608S121ATAH0; L_0603_1608Metric
IC4: TLV320AIC3104; QFN-32-1EP_5x5mm_P0.5mm_EP3.3x3.3mm
IC5: MIC5317; SOT-23-5
IC6: USBLC6-2SC6; SOT-23-6
J2: Conn_01x03; PinHeader_1x03_P2.54mm_Vertical
J3, J4: Conn_01x03; Molex_KK-254_AE-6410-03A_1x03_P2.54mm_Vertical
J5: USB_A; USBA_SMD
P1, P2: Conn_02x18_Odd_Even; PocketBeagle-P
R1, R2: 15; R_0603_1608Metric
R3: 100; R_0603_1608Metric
R4, R5: 560; R_0603_1608Metric
R6, R7: 3.3k; R_0603_1608Metric
R8, R9: 220; R_0603_1608Metric
R10, R11: 10k; R_0603_1608Metric
S1: PTS810; SW_SPST_PTS810

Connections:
+1V8: C6.1, IC4.32 (DVDD), IC5.5 (OUT)
+3.3VA: C16.1, C18.1, FB2.2, IC4.18 (DRVDD), IC4.24 (DRVDD2), IC4.25 (AVDD)
+3V3: C7.1, C17.1, C19.1, D3.2 (K), D4.2 (K), FB2.1, IC4.7 (IOVDD), IC5.1 (IN), IC5.3 (EN), P1.14, R10.1, R11.1; also elsewhere on the board
+5V: P1.24; also elsewhere on the board
/belamini_cape_C2_2/AUD_BCLK: IC4.2 (BCLK), P1.36
/belamini_cape_C2_2/AUD_DIN: IC4.5 (DOUT), P2.32
/belamini_cape_C2_2/AUD_DOUT: IC4.4 (DIN), P2.30
/belamini_cape_C2_2/AUD_HPLOUT: C8.1, IC4.19 (HPLOUT)
/belamini_cape_C2_2/AUD_HPROUT: C9.1, IC4.23 (HPROUT)
/belamini_cape_C2_2/AUD_MCLK: IC4.1 (MCLK), P1.29
/belamini_cape_C2_2/AUD_WCLK: IC4.3 (WCLK), P1.33
/belamini_cape_C2_2/HPL: D2.2 (A2), J4.2, R1.1, R7.2
/belamini_cape_C2_2/HPR: D1.2 (A2), J4.1, R2.1, R6.2
/belamini_cape_C2_2/INL: J3.2, R8.2
/belamini_cape_C2_2/INR: J3.1, R9.2
/belamini_cape_C2_2/LEFT_LOM: IC4.28 (LEFT_LOM)
/belamini_cape_C2_2/LEFT_LOP: IC4.27 (LEFT_LOP), J2.2
/belamini_cape_C2_2/LINE1LP: C14.1, D3.3 (common), IC4.14 (IN2L)
/belamini_cape_C2_2/LINE1RP: C15.1, D4.3 (common), IC4.16 (IN2R)
/belamini_cape_C2_2/RESETN: IC4.31 (~RESET), P2.26
/belamini_cape_C2_2/RIGHT_LOP: IC4.29 (RIGHT_LOP), J2.3
/belamini_cape_C2_2/RIGHT_ROM: IC4.30 (RIGHT_LOM)
/belamini_cape_C2_2/SCL: IC4.8 (SCL), P1.28, R11.2
/belamini_cape_C2_2/SDA: IC4.9 (SDA), P1.26, R10.2
/belamini_cape_C2_2/SHUTDOWN_REQ/: P2.34, R3.2
/belamini_cape_C2_2/USBGND: IC6.2 (GND), J5.4 (GND), J5.5 (Shield), P1.13, P1.15
/belamini_cape_C2_2/USB_DM: IC6.1 (I/O1), IC6.6 (I/O1), J5.2 (D-), P1.9
/belamini_cape_C2_2/USB_DP: IC6.3 (I/O2), IC6.4 (I/O2), J5.3 (D+), P1.11
/belamini_cape_C2_2/USB_VBUS: IC6.5 (VBUS), J5.1 (VBUS), P1.5, P1.7
ADC_RST/: P2.17; also elsewhere on the board
GND: C6.2, C7.2, C12.1, C13.1, C16.2, C17.2, C18.2, C19.2, D1.1 (A1), D2.1 (A1), D3.1 (A), D4.1 (A), D5.3 (K1), D5.4 (K2), IC4.6 (DVSS), IC4.17 (AVSS_ADC), IC4.21 (DRVSS), IC4.26 (AVSS_DAC), IC4.33 (EP), IC5.2 (GND), J2.1, J3.3, J4.3, P1.16, P1.22, P2.15, P2.21, R6.1, R7.1, S1.2; also elsewhere on the board
unnamed: C8.2, R1.2
unnamed: C9.2, R2.2
unnamed: C12.2, C14.2, R8.1
unnamed: C13.2, C15.2, R9.1
unnamed: D5.1 (A1), R4.1
unnamed: D5.2 (A2), R5.2
unnamed: P1.2, R5.1
unnamed: P1.4, R4.2
unnamed: R3.1, S1.1
SPI_ADC_CNV: P1.6; also elsewhere on the board
SPI_MISO: P1.10; also elsewhere on the board
SPI_MOSI: P1.12; also elsewhere on the board
SPI_SCK: P1.8; also elsewhere on the board

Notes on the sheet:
USB Host
PocketBeagle connectors
Audio (Headphone) Out
Audio Codec
Line Out
Audio In



Board: 4 copper layers, 55.0 x 35.0 mm, 55 parts (46 on the bottom side), 69 nets.

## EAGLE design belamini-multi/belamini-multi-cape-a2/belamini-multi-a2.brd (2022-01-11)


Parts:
C1, C2, C3, C4, C14, C15: 0.1uf; C0603
C5: 0.1uF; C0603
C6, C7, C8, C9, C12, C13: 47uf; EIA3216
C10, C11: 10uF; 0603-CAP
C16, C17, C20, C21, C24, C25: 1uF; C0603
C18, C19, C22, C23, C26, C27: 47pF; C0402-SMALL
D1: LED-RGLTST-C195KGJRKT; LTST-C195KGJRKT
D2, D3, D4, D5, D6, D7: BAS70-04; SOT23
FB1: 30Ω/1.8A; 0603
IC1, IC2, IC3: TLV320AIC3106; QFN48
IC4: V_REG_LDOSMD; SOT23-5
J1, J2, J3, J4, J5, J6: 22-23-2031
P1, P2: PINHD-2X18; 2X18
R1, R2, R10, R11, R12, R13: 10; C0402-SMALL
R3: 100; C0402-SMALL
R4, R5, R6, R7, R8, R9: 3.3k; C0402-SMALL
R14, R15: 560; C0402-SMALL
R16, R17, R18, R19, R20, R21: 220; C0402-SMALL
R22, R23: 22; C0402-SMALL
R24, R25: 10k; C0402-SMALL
SW1: SWITCH-MOMENTARY-2SMD-5; TACTILE_SWITCH_SMD-4

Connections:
1.8V: C3.1, IC1.36 (DVDD), IC2.36 (DVDD), IC3.36 (DVDD), IC4.5 (OUT)
3.3V: C2.1, C4.1, C5.1, C11.2, C14.1, D2.2 (C2), D3.2 (C2), D4.2 (C2), D5.2 (C2), D6.2 (C2), D7.2 (C2), FB1.1, IC1.44 (IOVDD), IC1.45 (MFP0), IC2.44 (IOVDD), IC3.44 (IOVDD), IC3.45 (MFP0), IC3.46 (MFP1), IC4.1 (IN), IC4.3 (EN), P1.14, R24.P$2 (2), R25.P$2 (2)
+5V: P1.24
AGND: C1.2, C2.2, C3.2, C4.2, C5.2, C10.1, C11.1, C14.2, C15.2, C18.P$2 (2), C19.P$1 (1), C22.P$2 (2), C23.P$1 (1), C26.P$2 (2), C27.P$1 (1), D1.P$3 (GC), D1.P$4 (RC), D2.1 (A1), D3.1 (A1), D4.1 (A1), D5.1 (A1), D6.1 (A1), D7.1 (A1), IC1.15 (AVSS_ADC), IC1.20 (DRVSS1), IC1.21 (DRVSS2), IC1.26 (AVSS_DAC), IC1.42 (DVSS), IC1.43 (SELECT), IC1.46 (MFP1), IC1.EXP (PAD), IC2.15 (AVSS_ADC), IC2.20 (DRVSS1), IC2.21 (DRVSS2), IC2.26 (AVSS_DAC), IC2.42 (DVSS), IC2.43 (SELECT), IC2.45 (MFP0), IC2.EXP (PAD), IC3.15 (AVSS_ADC), IC3.20 (DRVSS1), IC3.21 (DRVSS2), IC3.26 (AVSS_DAC), IC3.42 (DVSS), IC3.43 (SELECT), IC3.EXP (PAD), IC4.2 (GND), J1.1, J2.1, J3.1, J4.1, J5.1, J6.1, P1.16, P1.22, P2.15, P2.21, R4.P$1 (1), R5.P$1 (1), R6.P$1 (1), R7.P$1 (1), R8.P$1 (1), R9.P$1 (1), SW1.4 (2)
AUDIO_INL1: C16.1, C18.P$1 (1), R20.P$2 (2)
AUDIO_INL2: C20.1, C22.P$1 (1), R16.P$2 (2)
AUDIO_INL3: C24.1, C26.P$1 (1), R18.P$2 (2)
AUDIO_INR1: C17.2, C19.P$2 (2), R21.P$2 (2)
AUDIO_INR2: C21.2, C23.P$2 (2), R17.P$2 (2)
AUDIO_INR3: C25.2, C27.P$2 (2), R19.P$2 (2)
AUD_3V3: C1.1, C10.2, C15.1, FB1.2, IC1.16 (DRVDD1), IC1.17 (DRVDD2), IC1.24 (DRVDD3), IC1.25 (AVDD_DAC), IC2.16 (DRVDD1), IC2.17 (DRVDD2), IC2.24 (DRVDD3), IC2.25 (AVDD_DAC), IC2.46 (MFP1), IC3.16 (DRVDD1), IC3.17 (DRVDD2), IC3.24 (DRVDD3), IC3.25 (AVDD_DAC)
AUD_BCLK: IC1.38 (BCLK), IC2.38 (BCLK), IC3.38 (BCLK), R22.P$2 (2)
AUD_DIN: IC1.41 (DOUT), IC2.41 (DOUT), IC3.41 (DOUT), P2.32
AUD_DOUT: IC1.40 (DIN), IC2.40 (DIN), IC3.40 (DIN), P2.30
AUD_HPLOUT1: C8.A (+), IC1.18 (HPLOUT)
AUD_HPLOUT2: C6.A (+), IC2.18 (HPLOUT)
AUD_HPLOUT3: C12.A (+), IC3.18 (HPLOUT)
AUD_HPROUT1: C9.A (+), IC1.23 (HPROUT)
AUD_HPROUT2: C7.A (+), IC2.23 (HPROUT)
AUD_HPROUT3: C13.A (+), IC3.23 (HPROUT)
AUD_MCLK: IC1.37 (MCLK), IC2.37 (MCLK), IC3.37 (MCLK), R23.P$1 (1)
AUD_WCLK: IC1.39 (WCLK), IC2.39 (WCLK), IC3.39 (WCLK), P1.33
HPL1: J2.2, R7.P$2 (2), R10.P$1 (1)
HPL2: J5.2, R9.P$2 (2), R12.P$1 (1)
HPL3: J6.2, R1.P$1 (1), R5.P$2 (2)
HPR1: J2.3, R6.P$2 (2), R11.P$1 (1)
HPR2: J5.3, R8.P$2 (2), R13.P$1 (1)
HPR3: J6.3, R2.P$1 (1), R4.P$2 (2)
LEFT_LOM1: IC1.30 (LEFT_LOM)
LEFT_LOM2: IC2.30 (LEFT_LOM)
LEFT_LOM3: IC3.30 (LEFT_LOM)
LEFT_LOP1: IC1.29 (LEFT_LOP)
LEFT_LOP2: IC2.29 (LEFT_LOP)
LEFT_LOP3: IC3.29 (LEFT_LOP)
LINE1LM1: IC1.8 (LINE2LM)
LINE1LM2: IC2.8 (LINE2LM)
LINE1LM3: IC3.8 (LINE2LM)
LINE1LP1: C16.2, D3.3 (C1A2), IC1.7 (LINE2LP)
LINE1LP2: C20.2, D2.3 (C1A2), IC2.7 (LINE2LP)
LINE1LP3: C24.2, D6.3 (C1A2), IC3.7 (LINE2LP)
LINE1RM1: IC1.10 (LINE2RM)
LINE1RM2: IC2.10 (LINE2RM)
LINE1RM3: IC3.10 (LINE2RM)
LINE1RP1: C17.1, D4.3 (C1A2), IC1.9 (LINE2RP)
LINE1RP2: C21.1, D5.3 (C1A2), IC2.9 (LINE2RP)
LINE1RP3: C25.1, D7.3 (C1A2), IC3.9 (LINE2RP)
MICBIAS: IC2.13 (MICBIAS)
unnamed: J1.2, R20.P$1 (1)
unnamed: C6.C (-), R12.P$2 (2)
unnamed: C7.C (-), R13.P$2 (2)
unnamed: J1.3, R21.P$1 (1)
unnamed: J3.2, R16.P$1 (1)
unnamed: D1.P$2 (RA), R14.P$2 (2)
unnamed: J3.3, R17.P$1 (1)
unnamed: C12.C (-), R1.P$2 (2)
unnamed: J4.2, R18.P$1 (1)
unnamed: C13.C (-), R2.P$2 (2)
unnamed: J4.3, R19.P$1 (1)
unnamed: D1.P$1 (GA), R15.P$2 (2)
unnamed: P1.4, R14.P$1 (1)
unnamed: P1.2, R15.P$1 (1)
unnamed: P1.29, R23.P$2 (2)
unnamed: P1.36, R22.P$1 (1)
unnamed: C8.C (-), R10.P$2 (2)
unnamed: R3.P$1 (1), SW1.1
unnamed: C9.C (-), R11.P$2 (2)
RESETN: IC1.33 (RESET_N), IC2.33 (RESET_N), IC3.33 (RESET_N), P2.26
RIGHT_LOM1: IC1.32 (RIGHT_ROM)
RIGHT_LOM2: IC2.32 (RIGHT_ROM)
RIGHT_LOM3: IC3.32 (RIGHT_ROM)
RIGHT_LOP1: IC1.31 (RIGHT_ROP)
RIGHT_LOP2: IC2.31 (RIGHT_ROP)
RIGHT_LOP3: IC3.31 (RIGHT_ROP)
SCL: IC1.1 (SCL), IC2.1 (SCL), IC3.1 (SCL), P1.28, R24.P$1 (1)
SDA: IC1.2 (SDA), IC2.2 (SDA), IC3.2 (SDA), P1.26, R25.P$1 (1)
SHUTDOWN_REQ/: P2.34, R3.P$2 (2)
SPI_ADC_CNV: P1.6
SPI_MISO: P1.10
SPI_MOSI: P1.12
SPI_SCK: P1.8



Board: 4 copper layers, 63.4 x 35.0 mm, 73 parts (43 on the bottom side), 56 nets.

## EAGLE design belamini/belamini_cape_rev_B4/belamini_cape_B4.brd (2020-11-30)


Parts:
C1, C4, C5: 0.1uF; C0603
C2, C3: 10uF; 0603-CAP
FB1: FB; 0603
IC1, IC2: ADD8704; QFN16-3X3
IC3: AD7699; LFCSP20-LEADS
J1: M10SILK_FEMALE_PTH; 1X10
RN1: 22; 0603-ARC

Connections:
3.3V: IC3.15 (VIO); also elsewhere on the board
+5V_ADC_DAC: C1.1, C2.1, C5.1, FB1.1, IC1.2 (V+), IC2.2 (V+), IC3.1 (VDD$1), IC3.20 (VDD$2)
+5V_SYS: FB1.2; also elsewhere on the board
GND: C1.2, C2.2, C3.2, C4.2, C5.2, IC1.11 (V-), IC2.11 (V-), IC3.4 (GND$1), IC3.5 (GND$2), IC3.10 (COM), IC3.EXP (GND$3), J1.2; also elsewhere on the board
unnamed: IC2.1 (IN+), J1.6
unnamed: IC1.7 (OUT), IC1.8 (IN-), IC3.16 (IN0)
unnamed: IC1.13 (IN-), IC1.14 (OUT), IC3.17 (IN1)
unnamed: IC2.15 (OUT), IC2.16 (IN-), IC3.6 (IN4)
unnamed: IC2.5 (IN-), IC2.6 (OUT), IC3.7 (IN5)
unnamed: IC2.7 (OUT), IC2.8 (IN-), IC3.8 (IN6)
unnamed: IC2.13 (IN-), IC2.14 (OUT), IC3.9 (IN7)
unnamed: IC3.11 (CNV), RN1.4 (1)
unnamed: IC3.12 (DIN), RN1.3 (1)
unnamed: C4.1, IC3.3 (REFIN)
unnamed: IC3.13 (SCK), RN1.2 (1)
unnamed: IC3.14 (SDO), RN1.1
unnamed: IC1.5 (IN-), IC1.6 (OUT), IC3.19 (IN3)
unnamed: IC1.15 (OUT), IC1.16 (IN-), IC3.18 (IN2)
unnamed: IC1.9 (IN+), J1.10
unnamed: IC1.12 (IN+), J1.9
unnamed: IC1.1 (IN+), J1.8
unnamed: IC1.4 (IN+), J1.7
unnamed: IC2.4 (IN+), J1.5
unnamed: IC2.9 (IN+), J1.4
unnamed: IC2.12 (IN+), J1.3
SPI_ADC_CNV: RN1.5 (2); also elsewhere on the board
SPI_MISO: RN1.8 (2); also elsewhere on the board
SPI_MOSI: RN1.6 (2); also elsewhere on the board
SPI_SCK: RN1.7 (2); also elsewhere on the board
VREF: C3.1, IC3.2 (REF), J1.1

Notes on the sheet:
Vref


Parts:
C6, C16, C17: 0.1uf; C0603
C7: 1uf; C0603
C8, C9: 47uf; EIA3216
C12, C13: 47pF; C0603
C14, C15: 1uF; C0603
C18, C19: 10uf,10V; 0603-CAP
D1, D2: PGB0010603MR; 0603
D3, D4: BAS70-04; SOT23
D5: LED-RGLTST-C195KGJRKT; LTST-C195KGJRKT
FB2: FB; 0603
IC4: TLV320AIC3104; QFN-32
IC5: V_REG_LDOSMD; SOT23-5
IC6: USBLC6-2; SOT23-6
J2: DNI; 1X03
J3, J4: 22-23-2031
J5: USB-A-SMD; USB-A-S-NOSILK-FEMALE
P1, P2: PINHD-2X18; 2X18
R1, R2: 15; R0603
R3: 100; R0603
R4, R5: 33; R0603
R6, R7: 3.3k; R0603
R8, R9: 220; R0603
R10, R11: 10k; R0603
S1: SWITCH-MOMENTARY-2SMD-5; TACTILE_SWITCH_SMD-4

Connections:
1.8V: C6.1, IC4.32 (DVDD), IC5.5 (OUT)
3.3V: C7.1, C17.1, C19.2, D3.2 (C2), D4.2 (C2), FB2.2, IC4.7 (IOVDD), IC5.1 (IN), IC5.3 (EN), P1.14, R10.2, R11.2; also elsewhere on the board
+5V_SYS: P1.24; also elsewhere on the board
AUDIO_INL: C12.1, C14.1, R8.2
AUDIO_INR: C13.2, C15.2, R9.2
AUD_3V3: C16.1, C18.2, FB2.1, IC4.18 (DRVDD), IC4.24 (DRVDD2), IC4.25 (AVDD_DAC)
AUD_BCLK: IC4.2 (BCLK), P1.36
AUD_DIN: IC4.5 (DOUT), P2.32
AUD_DOUT: IC4.4 (DIN), P2.30
AUD_HPLOUT: C8.A (+), IC4.19 (HPLOUT)
AUD_HPROUT: C9.A (+), IC4.23 (HPROUT)
AUD_MCLK: IC4.1 (MCLK), P1.29
AUD_WCLK: IC4.3 (WCLK), P1.33
GND: C6.2, C7.2, C12.2, C13.1, C16.2, C17.2, C18.1, C19.1, D1.1, D2.1, D3.1 (A1), D4.1 (A1), D5.P$3 (GC), D5.P$4 (RC), IC4.6 (DVSS), IC4.17 (AVSS_ADC), IC4.21 (DRVSS), IC4.26 (AVSS_DAC), IC4.EP (PAD), IC5.2 (GND), J2.1, J3.1, J4.1, P1.16, P1.22, P2.15, P2.21, R6.1, R7.1, S1.4 (2); also elsewhere on the board
HPL: D2.2, J4.2, R1.1, R7.2
HPR: D1.2, J4.3, R2.1, R6.2
LEFT_LOM: IC4.28 (LEFT_LOM)
LEFT_LOP: IC4.27 (LEFT_LOP), J2.2
LINE1LP: C14.2, D3.3 (C1A2), IC4.14 (IN2L)
LINE1RP: C15.1, D4.3 (C1A2), IC4.16 (IN2R)
unnamed: J3.2, R8.1
unnamed: J3.3, R9.1
unnamed: D5.P$2 (RA), R4.2
unnamed: D5.P$1 (GA), R5.2
unnamed: P1.4, R4.1
unnamed: P1.2, R5.1
unnamed: C8.C (-), R1.2
unnamed: R3.1, S1.1
unnamed: C9.C (-), R2.2
RESETN: IC4.31 (RESETN), P2.26
RIGHT_LOP: IC4.29 (RIGHT_LOP), J2.3
RIGHT_ROM: IC4.30 (RIGHT_ROM)
SCL: IC4.8 (SCL), P1.28, R11.1
SDA: IC4.9 (SDA), P1.26, R10.1
SHUTDOWN_REQ/: P2.34, R3.2
SPI_ADC_CNV: P1.6; also elsewhere on the board
SPI_MISO: P1.10; also elsewhere on the board
SPI_MOSI: P1.12; also elsewhere on the board
SPI_SCK: P1.8; also elsewhere on the board
USBGND: IC6.2 (GND), J5.GND, P1.13, P1.15
USB_DM: IC6.1 (IO1), IC6.6 (IO1), J5.D-, P1.9
USB_DP: IC6.3 (IO2), IC6.4 (IO2), J5.D+, P1.11
USB_VBUS: IC6.5 (VBUS), J5.VBUS, P1.5, P1.7

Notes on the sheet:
IC6



Board: 2 copper layers, 55.0 x 35.0 mm, 50 parts (41 on the bottom side), 64 nets.

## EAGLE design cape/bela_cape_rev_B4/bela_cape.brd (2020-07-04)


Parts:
C1, C4, C5, C6, C7, C8, C9, C10, C35: 0.1uF; C0603
C2, C3: 10uF; 0603-CAP
FB3: FB; 0603
IC1, IC2: ADD8704RU; TSSOP14
IC3: AD5668; TSSOP16-PW
IC4: AD7699; LFCSP20-LEADS
IC5: TXB0104PWR; TSSOP14
J7, J8: PINHD-1X10; 1X10
R1, R2, R4: 0; R0603
R3, R5: DNI; R0603
R9: 100; R0603
RN1, RN2: 22; 0603-ARC
RN3, RN4, RN5, RN6: 220; 0603-ARC
TP1: PINHD-1X1; 1X01

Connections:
3.3V: C10.1, C35.1, IC4.15 (VIO), IC5.1 (VCCA), IC5.8 (OE); also elsewhere on the board
+5V_ADC_DAC: C1.1, C2.1, C6.1, C7.1, C8.1, C9.1, FB3.1, IC1.4 (V+), IC2.4 (V+), IC3.3 (VDD), IC4.1 (VDD$1), IC4.20 (VDD$2), IC5.14 (VCCB), R2.1, R5.1, R9.2
+5V_SYS: FB3.2; also elsewhere on the board
DGND: C1.2, C2.2, C3.2, C4.2, C5.2, C6.2, C7.2, C8.2, C9.2, C10.2, C35.2, IC1.11 (V-), IC2.11 (V-), IC3.14 (GND), IC4.4 (GND$1), IC4.5 (GND$2), IC4.EXP (GND$3), IC5.7 (GND), J7.10, J8.10, R1.2, R4.1; also elsewhere on the board
unnamed: IC3.16 (SCLK), IC5.13 (B1)
unnamed: IC3.15 (DIN), IC5.12 (B2)
unnamed: IC3.2 (SYNC/), IC5.11 (B3)
unnamed: IC3.9 (CLR/), R2.2, R3.2
unnamed: IC1.1 (OUT), IC1.2 (IN-), IC4.16 (IN0)
unnamed: IC1.6 (IN-), IC1.7 (OUT), IC4.17 (IN1)
unnamed: IC1.8 (OUT), IC1.9 (IN-), IC4.18 (IN2)
unnamed: IC1.13 (IN-), IC1.14 (OUT), IC4.19 (IN3)
unnamed: IC2.1 (OUT), IC2.2 (IN-), IC4.7 (IN5)
unnamed: IC2.6 (IN-), IC2.7 (OUT), IC4.6 (IN4)
unnamed: IC2.8 (OUT), IC2.9 (IN-), IC4.8 (IN6)
unnamed: IC2.13 (IN-), IC2.14 (OUT), IC4.9 (IN7)
unnamed: IC5.10 (B4), R3.1
unnamed: IC4.11 (CNV), RN2.4 (1)
unnamed: C5.1, IC3.8 (VREF)
unnamed: IC5.2 (A1), RN1.8 (2)
unnamed: IC5.3 (A2), RN1.7 (2)
unnamed: IC5.4 (A3), RN1.6 (2)
unnamed: IC5.5 (A4), RN1.5 (2)
unnamed: IC4.12 (DIN), RN2.3 (1)
unnamed: C3.1, IC4.2 (REF), TP1.1
unnamed: C4.1, IC4.3 (REFIN)
unnamed: IC4.13 (SCK), RN2.2 (1)
unnamed: IC4.14 (SDO), RN2.1
unnamed: IC4.10 (COM), J7.9, R4.2
unnamed: IC1.3 (IN+), RN3.4 (1)
unnamed: IC1.5 (IN+), RN3.3 (1)
unnamed: IC1.10 (IN+), RN3.2 (1)
unnamed: IC1.12 (IN+), RN3.1
unnamed: IC2.5 (IN+), RN4.4 (1)
unnamed: IC2.3 (IN+), RN4.3 (1)
unnamed: IC2.10 (IN+), RN4.2 (1)
unnamed: IC2.12 (IN+), RN4.1
unnamed: IC3.1 (LDAC/), R1.1, R5.2
unnamed: J7.1, RN3.5 (2)
unnamed: J7.2, RN3.6 (2)
unnamed: J7.3, RN3.7 (2)
unnamed: J7.4, RN3.8 (2)
unnamed: J7.5, RN4.5 (2)
unnamed: J7.6, RN4.6 (2)
unnamed: J7.7, RN4.7 (2)
unnamed: J7.8, RN4.8 (2)
unnamed: IC3.7 (VOUTG), RN5.4 (1)
unnamed: IC3.6 (VOUTE), RN5.3 (1)
unnamed: IC3.5 (VOUTC), RN5.2 (1)
unnamed: IC3.4 (VOUTA), RN5.1
unnamed: IC3.13 (VOUTB), RN6.4 (1)
unnamed: IC3.12 (VOUTD), RN6.3 (1)
unnamed: IC3.11 (VOUTF), RN6.2 (1)
unnamed: J8.8, RN6.8 (2)
unnamed: J8.9, R9.1
unnamed: IC3.10 (VOUTH), RN6.1
unnamed: J8.7, RN6.7 (2)
unnamed: J8.6, RN6.6 (2)
unnamed: J8.5, RN6.5 (2)
unnamed: J8.4, RN5.8 (2)
unnamed: J8.3, RN5.7 (2)
unnamed: J8.2, RN5.6 (2)
unnamed: J8.1, RN5.5 (2)
SPI_ADC_CNV: RN2.5 (2); also elsewhere on the board
SPI_DAC_CLR/: RN1.4 (1); also elsewhere on the board
SPI_DAC_SYNC/: RN1.3 (1); also elsewhere on the board
SPI_MISO: RN2.8 (2); also elsewhere on the board
SPI_MOSI: RN1.2 (1), RN2.6 (2); also elsewhere on the board
SPI_SCK: RN1.1, RN2.7 (2); also elsewhere on the board

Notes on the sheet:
Vref


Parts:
C11, C15, C36, C40: 0.1uF; C0603
C12, C38: 1uF; C0603
C14, C39: 47uF; EIA3216
FB4: FB; 0603
IC8, IC9: LM4876; SO8
J5, J6: 22-23-2021
J10: M04PTH; 1X04
R7, R14: 43k; R0603
R8, R10, R13: 22k; R0603

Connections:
+5V_AMP: C14.A (+), C15.1, C39.A (+), C40.1, FB4.2, IC8.6 (VDD), IC9.6 (VDD); also elsewhere on the board
+5V_POW: FB4.1; also elsewhere on the board
AGND: C11.2, C14.C (-), C15.2, C36.2, C39.C (-), C40.2, IC8.7 (VSS), IC9.7 (VSS), J10.1, J10.3, R10.2; also elsewhere on the board
AMP_SH/: IC8.1 (SH/), IC9.1 (SH/), R10.1; also elsewhere on the board
LEFT_LOP_RETURN: C38.2, J10.4
unnamed: IC9.4 (IN-), R13.1, R14.2
unnamed: IC8.4 (IN-), R7.2, R8.1
unnamed: C11.1, IC8.2 (BYP), IC8.3 (IN+)
unnamed: C12.2, R8.2
unnamed: IC8.5 (OUT-), J6.1, R7.1
unnamed: C36.1, IC9.2 (BYP), IC9.3 (IN+)
unnamed: C38.1, R13.2
unnamed: IC9.5 (OUT-), J5.1, R14.1
unnamed: IC9.8 (OUT+), J5.2
unnamed: IC8.8 (OUT+), J6.2
RIGHT_LOP_RETURN: C12.1, J10.2

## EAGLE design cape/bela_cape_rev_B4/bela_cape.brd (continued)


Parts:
C16, C17: 47uf; EIA3216
C20, C21, C22, C23: 0.1uf; C0603
C24, C25, C26, C27: 10uf,10V; 0603-CAP
C28, C29: 1uF; C0603
C30, C31: 47pF; C0603
C32: 1uf; C0603
C33: .01uf; C0603
C34: 2.2uf; C0603
D1, D2: PGB0010603MR; 0603
D3, D4: BAS70-04; SOT23
FB1, FB2: FB; 0603
IC6: TLV320AIC3104; QFN-32
IC7: V_REG_LDOSMD; SOT23-5
J3, J4: 22-23-2031
J9: M04PTH; 1X04
R6: 0; R0603
R11, R12: 15; R0603
R15, R16: 3.3k; R0603
R17, R18: 220; R0603
S1: SWITCH-MOMENTARY-2SMD-5; TACTILE_SWITCH_SMD-4
TP2: PINHD-1X1; 1X01
U$1: BEAGLEBONE_OUTLINE; BEAGLEBONE_SHIELD

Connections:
1.8V: C23.1, C27.2, C34.1, IC6.32 (DVDD), IC7.5 (OUT)
3.3V: C22.1, C26.2, C32.1, FB2.2, IC6.7 (IOVDD), IC7.1 (IN), IC7.3 (EN), U$1.49 (VDD_3V3EXP); also elsewhere on the board
+5V_POW: U$1.51 (VDD_5V), U$1.52 (VDD_5V); also elsewhere on the board
+5V_SYS: U$1.53 (SYS_5V), U$1.54 (SYS_5V); also elsewhere on the board
AGND: C20.2, C21.2, C24.1, C25.1, C30.2, C31.1, D1.1, D2.1, D3.1 (A1), D4.1 (A1), FB1.1, IC6.17 (AVSS_ADC), IC6.26 (AVSS_DAC), J3.1, J4.1, R15.1, R16.1; also elsewhere on the board
AIN0: U$1.85 (AIN0)
AMP_SH/: U$1.26 (GPIO1_29); also elsewhere on the board
AUDIO_INL: C28.1, C30.1, R17.2
AUDIO_INR: C29.2, C31.2, R18.2
AUD_3V3: C20.1, C21.1, C24.2, C25.2, D3.2 (C2), D4.2 (C2), FB2.1, IC6.18 (DRVDD), IC6.24 (DRVDD2), IC6.25 (AVDD_DAC)
AUD_BCLK: IC6.2 (BCLK), U$1.77 (SPI1_SCLK)
AUD_DIN: IC6.5 (DOUT), U$1.76 (SPI1_DI)
AUD_DOUT: IC6.4 (DIN), U$1.74 (SPI1_CS0)
AUD_HPLOUT: C16.A (+), IC6.19 (HPLOUT)
AUD_HPROUT: C17.A (+), IC6.23 (HPROUT)
AUD_MCLK: IC6.1 (MCLK), U$1.71 (GPIO3_21)
AUD_WCLK: IC6.3 (WCLK), U$1.75 (SPI1_DO)
DGND: C22.2, C23.2, C26.1, C27.1, C32.2, C33.2, C34.2, FB1.2, IC6.6 (DVSS), IC6.21 (DRVSS), IC6.EP (PAD), IC7.2 (GND), S1.4 (2), U$1.1 (GND), U$1.2 (GND), U$1.47 (GND), U$1.48 (GND), U$1.89 (GND), U$1.90 (GND), U$1.91 (GND), U$1.92 (GND); also elsewhere on the board
HPL: D2.2, J4.2, R11.1, R15.2
HPR: D1.2, J4.3, R12.1, R16.2
I2C1_SCL: U$1.70 (UART1_TXD); also elsewhere on the board
I2C1_SDA: U$1.72 (UART1_RXD); also elsewhere on the board
LEFT_LOM: IC6.28 (LEFT_LOM), J9.3
LEFT_LOP: IC6.27 (LEFT_LOP), J9.4
LINE1LP: C28.2, D3.3 (C1A2), IC6.14 (IN2L)
LINE1RP: C29.1, D4.3 (C1A2), IC6.16 (IN2R)
unnamed: C16.C (-), R11.2
unnamed: IC6.15 (MICBIAS), TP2.1
unnamed: R6.1, S1.1
unnamed: C17.C (-), R12.2
unnamed: J3.2, R17.1
unnamed: C33.1, IC7.4 (BP)
unnamed: J3.3, R18.1
P9_11: U$1.57 (UART4_RXD)
P9_13: U$1.59 (UART4_TXD)
RESETN: IC6.31 (RESETN), U$1.56 (SYS_RESETN)
RIGHT_LOP: IC6.29 (RIGHT_LOP), J9.2
RIGHT_ROM: IC6.30 (RIGHT_ROM), J9.1
SCL: IC6.8 (SCL), U$1.65 (I2C2_SCL)
SDA: IC6.9 (SDA), U$1.66 (I2C2_SDA)
SHUTDOWN_REQ/: R6.2, U$1.73 (GPIO3_19)
SPI_ADC_CNV: U$1.61 (GPIO1_16); also elsewhere on the board
SPI_DAC_CLR/: U$1.69 (GPIO1_17); also elsewhere on the board
SPI_DAC_SYNC/: U$1.63 (I2C1_SCL); also elsewhere on the board
SPI_MISO: U$1.67 (UART2_TXD); also elsewhere on the board
SPI_MOSI: U$1.64 (I2C1_SDA); also elsewhere on the board
SPI_SCK: U$1.68 (UART2_RXD); also elsewhere on the board
VDD_3V3EXP: U$1.50 (VDD_3V3EXP)


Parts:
J1: 22-23-2021
J2: 22-23-2041
R21, R22: 2.2k; R0603

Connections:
3.3V: J2.1, R21.2, R22.2; also elsewhere on the board
+5V_AMP: J1.1; also elsewhere on the board
DGND: J1.2, J2.4; also elsewhere on the board
I2C1_SCL: J2.2, R21.1; also elsewhere on the board
I2C1_SDA: J2.3, R22.1; also elsewhere on the board


Board: 2 copper layers, 71.8 x 54.6 mm, 93 parts (0 on the bottom side), 117 nets.

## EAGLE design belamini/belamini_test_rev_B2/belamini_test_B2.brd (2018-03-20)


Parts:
J1: M10SILK_FEMALE_PTH; 1X10
J2: DNI; 1X03
J3: 22-23-2031

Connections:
AGND: J1.2
GND: J2.1
LEFT: J1.4, J1.6, J1.8, J1.10, J2.2, J3.2
RIGHT: J1.3, J1.5, J1.7, J1.9, J2.3, J3.3


Board: 2 copper layers, 50.9 x 22.7 mm, 3 parts (0 on the bottom side), 2 nets.

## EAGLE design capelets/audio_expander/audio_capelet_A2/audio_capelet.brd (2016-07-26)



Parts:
C1, C4, C7, C10, C13, C16, C19, C22, C25, C30, C33, C36, C39, C42, C45, C48, C49, C50: 1uF; C0603
C2, C3, C5, C6, C8, C9, C11, C12, C14, C15, C17, C20, C21, C23, C24: 330pF; C0603
C18: 300pF; C0603
C26, C28, C31, C34, C37, C40, C43, C46: 220pF; C0603
C27, C29, C32, C35, C38, C41, C44, C47: 440pF; C0603
C51, C52, C53, C54, C55, C56, C57, C58, C59, C60, C61, C62: 0.1uF; C0603
IC1, IC2, IC3, IC4, IC5, IC6: ADD8704RU; TSSOP14
IC7: LP5907-1.8; SOT23-5
J1, J2, J3, J4, J5, J6, J7, J8: 22-23-2031
J11: M08SMALL_DIAMETER; 1X08_SMALL_DIAMETER
J12A, J12B, J12C, J12D, J12E, J12F, J12G, J12H: 22-23-2021HEADER; 1X02
R1, R8, R15, R22, R29, R36, R43, R50: 30k; R0603
R2, R9, R16, R23, R30, R37, R44, R51: 3.3k; R0603
R3, R10, R17, R24, R31, R38, R45, R52: 100k; R0603
R4, R5, R7, R11, R12, R14, R18, R19, R21, R25, R26, R28, R32, R33, R35, R39, R40, R42, R46, R47, R49, R53, R54, R56: 27.4k; R0603
R6, R13, R20, R27, R34, R41, R48, R55: 16.2k; R0603
R57, R58, R59, R60, R61, R62, R63, R64, R65, R66, R67, R68, R69, R70, R71, R72: 28.7k; R0603
TP1: TPPAD1-17Y; P1-17Y
U$1: BELA_CAPELET_EXT_OUTLINE; BELA_CAPELET_EXTENDED_OUTLINE

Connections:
01: C30.1, J5.3
AIN0: U$1.85 (AIN0)
AIN_0: C3.1, IC1.7 (OUT), J11.1, R6.2
AIN_1: C6.1, IC1.14 (OUT), J11.2, R13.2
AIN_2: C9.1, IC2.7 (OUT), J11.3, R20.2
AIN_3: C12.1, IC2.14 (OUT), J11.4, R27.2
AIN_4: C15.1, IC3.7 (OUT), J11.5, R34.2
AIN_5: C18.1, IC3.14 (OUT), J11.6, R41.2
AIN_6: C21.1, IC4.7 (OUT), J11.7, R48.2
AIN_7: C24.1, IC4.14 (OUT), J11.8, R55.2
AOUT_0: R60.1, U$1.OUT_PIN1 (1)
AOUT_1: R57.1, U$1.OUT_PIN2 (2)
AOUT_2: R59.1, U$1.OUT_PIN3 (3)
AOUT_3: R63.1, U$1.OUT_PIN4 (4)
AOUT_4: R65.1, U$1.OUT_PIN5 (5)
AOUT_5: R67.1, U$1.OUT_PIN6 (6)
AOUT_6: R69.1, U$1.OUT_PIN7 (7)
AOUT_7: R71.1, U$1.OUT_PIN8 (8)
unnamed: C2.1, IC1.5 (IN+), R5.2
unnamed: IC1.2 (IN-), J12A.1, R1.1
unnamed: IC1.1 (OUT), R1.2, R4.1
unnamed: C3.2, R4.2, R5.1
unnamed: C25.2, C27.1, IC5.1 (OUT), IC5.2 (IN-)
unnamed: IC1.6 (IN-), R6.1, R7.2
unnamed: C1.1, IC1.3 (IN+), R3.2
unnamed: J12A.2, R2.2
unnamed: IC1.8 (OUT), R8.2, R11.1
unnamed: C6.2, R11.2, R12.1
unnamed: C5.1, IC1.12 (IN+), R12.2
unnamed: C27.2, R60.2, R61.1
unnamed: IC1.13 (IN-), R13.1, R14.2
unnamed: IC2.1 (OUT), R15.2, R18.1
unnamed: C4.1, IC1.10 (IN+), R10.2
unnamed: IC1.9 (IN-), J12B.1, R8.1
unnamed: C1.2, J1.2
unnamed: C4.2, J1.3
unnamed: IC2.2 (IN-), J12C.1, R15.1
unnamed: C9.2, R18.2, R19.1
unnamed: C8.1, IC2.5 (IN+), R19.2
unnamed: C26.1, IC5.3 (IN+), R61.2
unnamed: IC2.6 (IN-), R20.1, R21.2
unnamed: J12C.2, R16.2
unnamed: C7.1, IC2.3 (IN+), R17.2
unnamed: IC2.8 (OUT), R22.2, R25.1
unnamed: C12.2, R25.2, R26.1
unnamed: C11.1, IC2.12 (IN+), R26.2
unnamed: C29.2, R57.2, R58.1
unnamed: IC2.13 (IN-), R27.1, R28.2
unnamed: IC2.9 (IN-), J12D.1, R22.1
unnamed: J12D.2, R23.2
unnamed: C10.1, IC2.10 (IN+), R24.2
unnamed: C7.2, J2.2
unnamed: C10.2, J2.3
unnamed: IC3.1 (OUT), R29.2, R32.1
unnamed: C15.2, R32.2, R33.1
unnamed: C14.1, IC3.5 (IN+), R33.2
unnamed: C28.1, IC5.5 (IN+), R58.2
unnamed: IC3.6 (IN-), R34.1, R35.2
unnamed: C13.1, IC3.3 (IN+), R31.2
unnamed: IC3.2 (IN-), J12E.1, R29.1
unnamed: J12E.2, R30.2
unnamed: IC3.8 (OUT), R36.2, R39.1
unnamed: C18.2, R39.2, R40.1
unnamed: C17.1, IC3.12 (IN+), R40.2
unnamed: C29.1, C30.2, IC5.6 (IN-), IC5.7 (OUT)
unnamed: IC3.13 (IN-), R41.1, R42.2
unnamed: C16.1, IC3.10 (IN+), R38.2
unnamed: IC3.9 (IN-), J12F.1, R36.1
unnamed: J12F.2, R37.2
unnamed: C13.2, J3.2
unnamed: C16.2, J3.3
unnamed: IC4.1 (OUT), R43.2, R46.1
unnamed: C21.2, R46.2, R47.1
unnamed: C20.1, IC4.5 (IN+), R47.2
unnamed: C32.2, R59.2, R62.1
unnamed: IC4.6 (IN-), R48.1, R49.2
unnamed: C19.1, IC4.3 (IN+), R45.2
unnamed: IC4.2 (IN-), J12G.1, R43.1
unnamed: J12G.2, R44.2
unnamed: IC4.8 (OUT), R50.2, R53.1
unnamed: C24.2, R53.2, R54.1
unnamed: C23.1, IC4.12 (IN+), R54.2
unnamed: C31.1, IC5.10 (IN+), R62.2
unnamed: IC4.13 (IN-), R55.1, R56.2
unnamed: C22.1, IC4.10 (IN+), R52.2
unnamed: IC4.9 (IN-), J12H.1, R50.1
unnamed: J12H.2, R51.2
unnamed: C19.2, J4.2
unnamed: C22.2, J4.3
unnamed: C32.1, C33.2, IC5.8 (OUT), IC5.9 (IN-)
unnamed: C35.2, R63.2, R64.1
unnamed: C34.1, IC5.12 (IN+), R64.2
unnamed: C35.1, C36.2, IC5.13 (IN-), IC5.14 (OUT)
unnamed: C38.2, R65.2, R66.1
unnamed: C37.1, IC6.3 (IN+), R66.2
unnamed: J12B.2, R9.2
unnamed: C38.1, C39.2, IC6.1 (OUT), IC6.2 (IN-)
unnamed: C41.2, R67.2, R68.1
unnamed: C40.1, IC6.5 (IN+), R68.2
unnamed: C41.1, C42.2, IC6.6 (IN-), IC6.7 (OUT)
unnamed: C44.2, R69.2, R70.1
unnamed: C43.1, IC6.10 (IN+), R70.2
unnamed: C44.1, C45.2, IC6.8 (OUT), IC6.9 (IN-)
unnamed: C47.2, R71.2, R72.1
unnamed: C46.1, IC6.12 (IN+), R72.2
unnamed: C47.1, C48.2, IC6.13 (IN-), IC6.14 (OUT)
unnamed: C45.1, J8.2
unnamed: C39.1, J7.2
O0: C25.1, J5.2
O2: C33.1, J6.2
O3: C36.1, J6.3
O5: C42.1, J7.3
O7: C48.1, J8.3
PE: C2.2, C5.2, C8.2, C11.2, C14.2, C17.2, C20.2, C23.2, C26.2, C28.2, C31.2, C34.2, C37.2, C40.2, C43.2, C46.2, C50.1, C51.2, C52.2, C53.2, C54.2, C55.2, C56.2, IC7.5 (OUT), R2.1, R3.1, R7.1, R9.1, R10.1, R14.1, R16.1, R17.1, R21.1, R23.1, R24.1, R28.1, R30.1, R31.1, R35.1, R37.1, R38.1, R42.1, R44.1, R45.1, R49.1, R51.1, R52.1, R56.1, TP1.TP
V+: C49.1, C57.2, C58.2, C59.2, C60.2, C61.2, C62.2, IC1.4 (V+), IC2.4 (V+), IC3.4 (V+), IC4.4 (V+), IC5.4 (V+), IC6.4 (V+), IC7.1 (IN), IC7.3 (EN), U$1.53 (SYS_5V), U$1.54 (SYS_5V)
V-: C49.2, C50.2, C51.1, C52.1, C53.1, C54.1, C55.1, C56.1, C57.1, C58.1, C59.1, C60.1, C61.1, C62.1, IC1.11 (V-), IC2.11 (V-), IC3.11 (V-), IC4.11 (V-), IC5.11 (V-), IC6.11 (V-), IC7.2 (GND), J1.1, J2.1, J3.1, J4.1, J5.1, J6.1, J7.1, J8.1, U$1.1 (GND), U$1.2 (GND), U$1.47 (GND), U$1.48 (GND), U$1.89 (GND), U$1.90 (GND), U$1.91 (GND), U$1.92 (GND), U$1.IN_PIN10 (10), U$1.OUT_PIN10 (10)
VDD_3V3EXP: U$1.49 (VDD_3V3EXP), U$1.50 (VDD_3V3EXP)
VDD_5V: U$1.51 (VDD_5V), U$1.52 (VDD_5V)



Board: 4 copper layers, 54.6 x 63.1 mm, 160 parts (65 on the bottom side), 117 nets.

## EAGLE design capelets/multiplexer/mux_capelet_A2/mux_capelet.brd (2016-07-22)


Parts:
C1, C2, C3, C4: C-USC0603; C0603
IC1, IC2, IC3, IC4, IC5, IC6, IC7, IC8: 4051B; TSSOP16-PW
J1, J2: 2534-; PAK100/2500-34
J3, J4: PINHD-1X2; 1X02
R1, R2, R3, R4, R5, R6, R7, R8, R9, R10: R-US_R0603; R0603
R11: 0; R0603
U$1: BELA_CAPELET_NO_OUT; BELA_CAPELET_NO_OUTLINE

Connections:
+5V: C1.1, C2.1, C3.1, C4.1, IC1.16 (VCC), IC2.16 (VCC), IC3.16 (VCC), IC4.16 (VCC), IC5.16 (VCC), IC6.16 (VCC), IC7.16 (VCC), IC8.16 (VCC), J3.1, J4.1, U$1.53 (SYS_5V), U$1.54 (SYS_5V)
AIN0: U$1.85 (AIN0)
GND: C1.2, C2.2, C3.2, C4.2, IC1.7 (VEE), IC1.8 (GND), IC2.7 (VEE), IC2.8 (GND), IC3.7 (VEE), IC3.8 (GND), IC4.7 (VEE), IC4.8 (GND), IC5.7 (VEE), IC5.8 (GND), IC6.7 (VEE), IC6.8 (GND), IC7.7 (VEE), IC7.8 (GND), IC8.7 (VEE), IC8.8 (GND), J1.34, J2.34, R1.1, R2.1, R11.2, U$1.1 (GND), U$1.2 (GND), U$1.47 (GND), U$1.48 (GND), U$1.89 (GND), U$1.90 (GND), U$1.91 (GND), U$1.92 (GND)
IN0: IC1.3 (X), R3.2, U$1.IN_PIN1 (1)
IN1: IC2.3 (X), R4.2, U$1.IN_PIN2 (2)
IN2: IC3.3 (X), R5.2, U$1.IN_PIN3 (3)
IN3: IC4.3 (X), R6.2, U$1.IN_PIN4 (4)
IN4: IC5.3 (X), R7.2, U$1.IN_PIN5 (5)
IN5: IC6.3 (X), R8.2, U$1.IN_PIN6 (6)
IN6: IC7.3 (X), R9.2, U$1.IN_PIN7 (7)
IN7: IC8.3 (X), R10.2, U$1.IN_PIN8 (8)
IN_COM: J1.33, J2.33, U$1.IN_PIN9 (9)
IN_GND: R3.1, R4.1, R5.1, R6.1, R7.1, R8.1, R9.1, R10.1, R11.1, U$1.IN_PIN10 (10)
J2: IC7.15 (X2), J2.19
MUX1A: IC1.11 (A), IC2.11 (A), IC3.11 (A), IC4.11 (A), U$1.45 (GPIO2_6)
MUX1B: IC1.10 (B), IC2.10 (B), IC3.10 (B), IC4.10 (B), U$1.46 (GPIO2_7)
MUX1C: IC1.9 (C), IC2.9 (C), IC3.9 (C), IC4.9 (C), U$1.43 (GPIO2_8)
MUX1INH: IC1.6 (INH), IC2.6 (INH), IC3.6 (INH), IC4.6 (INH), J3.2, R1.2
MUX2A: IC5.11 (A), IC6.11 (A), IC7.11 (A), IC8.11 (A), U$1.44 (GPIO2_9)
MUX2B: IC5.10 (B), IC6.10 (B), IC7.10 (B), IC8.10 (B), U$1.41 (GPIO2_10)
MUX2C: IC5.9 (C), IC6.9 (C), IC7.9 (C), IC8.9 (C), U$1.42 (GPIO2_11)
MUX2INH: IC5.6 (INH), IC6.6 (INH), IC7.6 (INH), IC8.6 (INH), J4.2, R2.2
unnamed: IC6.13 (X0), J2.9
unnamed: IC6.14 (X1), J2.10
unnamed: IC6.15 (X2), J2.11
unnamed: IC6.12 (X3), J2.12
unnamed: IC6.1 (X4), J2.13
unnamed: IC6.5 (X5), J2.14
unnamed: IC6.2 (X6), J2.15
unnamed: IC6.4 (X7), J2.16
unnamed: IC5.13 (X0), J2.1
unnamed: IC5.14 (X1), J2.2
unnamed: IC5.15 (X2), J2.3
unnamed: IC5.12 (X3), J2.4
unnamed: IC5.1 (X4), J2.5
unnamed: IC5.5 (X5), J2.6
unnamed: IC5.2 (X6), J2.7
unnamed: IC5.4 (X7), J2.8
unnamed: IC7.13 (X0), J2.17
unnamed: IC7.14 (X1), J2.18
unnamed: IC7.12 (X3), J2.20
unnamed: IC7.1 (X4), J2.21
unnamed: IC7.5 (X5), J2.22
unnamed: IC7.2 (X6), J2.23
unnamed: IC7.4 (X7), J2.24
unnamed: IC8.13 (X0), J2.25
unnamed: IC8.14 (X1), J2.26
unnamed: IC8.15 (X2), J2.27
unnamed: IC8.12 (X3), J2.28
unnamed: IC8.1 (X4), J2.29
unnamed: IC8.5 (X5), J2.30
unnamed: IC8.2 (X6), J2.31
unnamed: IC8.4 (X7), J2.32
unnamed: IC1.13 (X0), J1.1
unnamed: IC1.14 (X1), J1.2
unnamed: IC1.15 (X2), J1.3
unnamed: IC1.12 (X3), J1.4
unnamed: IC1.1 (X4), J1.5
unnamed: IC1.5 (X5), J1.6
unnamed: IC1.2 (X6), J1.7
unnamed: IC1.4 (X7), J1.8
unnamed: IC2.13 (X0), J1.9
unnamed: IC2.14 (X1), J1.10
unnamed: IC2.15 (X2), J1.11
unnamed: IC2.12 (X3), J1.12
unnamed: IC2.1 (X4), J1.13
unnamed: IC2.5 (X5), J1.14
unnamed: IC2.2 (X6), J1.15
unnamed: IC2.4 (X7), J1.16
unnamed: IC3.13 (X0), J1.17
unnamed: IC3.14 (X1), J1.18
unnamed: IC3.15 (X2), J1.19
unnamed: IC3.12 (X3), J1.20
unnamed: IC3.1 (X4), J1.21
unnamed: IC3.5 (X5), J1.22
unnamed: IC3.2 (X6), J1.23
unnamed: IC3.4 (X7), J1.24
unnamed: IC4.13 (X0), J1.25
unnamed: IC4.14 (X1), J1.26
unnamed: IC4.15 (X2), J1.27
unnamed: IC4.12 (X3), J1.28
unnamed: IC4.1 (X4), J1.29
unnamed: IC4.5 (X5), J1.30
unnamed: IC4.2 (X6), J1.31
unnamed: IC4.4 (X7), J1.32
VDD_3V3EXP: U$1.49 (VDD_3V3EXP), U$1.50 (VDD_3V3EXP)
VDD_5V: U$1.51 (VDD_5V), U$1.52 (VDD_5V)


Board: 2 copper layers, 54.6 x 85.0 mm, 28 parts (0 on the bottom side), 86 nets.

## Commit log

2016-07-22 Added Bela cape, multiplexer capelet and supporting EAGLE files
    [bela_cape.brd, bela_cape.sch, bela_cape_bom.xlsx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]
2016-07-26 Added Audio Expander Capelet design files (rev A2)
    [audio_capelet.brd, audio_capelet.sch, audio_capelet_bom.xlsx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]
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2017-09-01 Updated Bela cape to rev B2; closes #1, #2, #4
    [bela_cape.brd, bela_cape.sch, bela_cape_bom.xlsx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]
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2018-02-04 Updated Bela mini BOM to fix missing resistors and socket
    [PocketBelaCape_rev2_bom.xlsx]
2018-03-08 Added ESD suppressor IC6 to USB port; grounded USB ID pin; added labels and updated BOM
    [belamini_cape_B2.brd, belamini_cape_B2.sch, belamini_cape_B2_bom.xlsx]
2018-03-11 Added Gerbers for mini cape rev. B2, updated BOM, and created an EAGLE CAM job for the mini cape.
    [belamini_cape_B2_bom.xlsx, belamini_cape_B2_centroid.csv]
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2018-03-20 Line out is DC-coupled, so no need for external components
    [belamini_test_B2.brd, belamini_test_B2.sch]
2018-12-07 renamed belamini folder and added pdf schematics and board of belamini
    [PocketBelaCape.brd, PocketBelaCape.sch, PocketBelaCape_rev2.brd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]
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2020-07-04 Rev. B3 of the Bela Mini cape adds resistors R6 and R7 to reduce the noise when the audio output is driving a DI box and the codec is not active.
    [belamini_cape_B3.brd, belamini_cape_B3.sch, belamini_cape_B3_bom.xlsx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]
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2020-07-04 Add rev. B4 of Bela cape, moving some traces on the bottom layer for improved manufacturing reliability.
    [bela_cape.brd, bela_cape.sch, bela_cape_bom.xlsx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]
2020-11-30 Bela Mini rev. B4: addresses #7, #8, #10, #11
    [belamini_cape_B4.brd, belamini_cape_B4.sch]
2020-11-30 Add manufacturing files for Bela Mini rev. B4
    [belamini_cape_B4_bom.xlsx, belamini_cape_B4_centroid.csv]
2021-11-09 Update README.md (#13)
    https://forum.kicad.info/t/warning-avoid-all-links-to-kicad-pcb-org-use-kicad-org/31521
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2022-08-16 First draft of mini rev. C1, with new ADC and move to KiCad
    [belamini_cape_C1.kicad_pcb, belamini_cape_C1.kicad_sch, belamini_cape_C1_1.kicad_sch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]
2022-08-16 Add logo to Mini rev. C1, clean up schematic and add production files
    [belamini_cape_C1-B_Cu.gbr, belamini_cape_C1-B_Mask.gbr, belamini_cape_C1-B_Paste.gbr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]
2022-08-16 Mini rev. C1: change IC3 on the BOM
    [belamini_cape_C1_bom.xlsx]
2022-08-16 Added Bela Mini rev. C2, fixing a couple issues in C1
    [belamini_cape_C2.kicad_pcb, belamini_cape_C2.kicad_sch, belamini_cape_C2_1.kicad_sch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]
2023-03-12 Bela cape rev. C1 - design in progress
    (cherry picked from commit 96cf0ad517c32be44510b9f78b20fff38d2effcd)
    [bela_cape.kicad_pcb, bela_cape.kicad_sch, bela_cape_1.kicad_sch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]
2023-03-12 Updates to Bela cape C1, adding 3-pin connectors for raw analog out
    (cherry picked from commit eb88a9ebe73bf9c3f735ce6d0fd609408781e91a)
    [bela_cape.kicad_pcb, bela_cape.kicad_sch, bela_cape_6.kicad_sch]
2023-03-12 More C1 cape routing
    (cherry picked from commit db7d999e21b46c22925661ce0002776775f31ffd)
    [bela_cape.kicad_pcb, bela_cape.kicad_sch, bela_cape_2.kicad_sch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]
2023-03-12 Further routing on C1 cape
    (cherry picked from commit 232a25b01e013bf194cdc3a343766aa7b43870aa)
    [bela_cape.kicad_pcb, bela_cape.kicad_sch, bela_cape_2.kicad_sch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]
2023-03-12 First complete routing of C1 cape
    (cherry picked from commit 8c5092941a0b3ec42f55098733fd0108b2086674)
    [bela_cape.kicad_pcb, bela_cape.kicad_sch, bela_cape_2.kicad_sch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]
2023-03-12 C1 cape: clean up bottom silkscreen
    (cherry picked from commit 7c02b20f8f7a862246e5856b6fa8015b8ad6464b)
    [bela_cape.kicad_pcb, bela_cape.kicad_sch, bela_cape_2.kicad_sch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]
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2023-03-12 Further C1 cape updates
    (cherry picked from commit 4c76e949636c5b1483c5ffba2ecc0f217292ab87)
    [bela_cape.kicad_pcb, bela_cape.kicad_sch, bela_cape_6.kicad_sch]
2023-03-12 Bela cape C1: renumber components
    (cherry picked from commit 6ebfe9c44bb7559ffb4c9dbd092e49803523e6a1)
    [bela_cape.kicad_pcb, bela_cape.kicad_sch, bela_cape_2.kicad_sch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]
2023-03-12 First complete iteration of C1 cape layout
    (cherry picked from commit 0ee733c70b42f416809330055e007cefcdb105fa)
    [bela_cape.kicad_pcb, bela_cape.kicad_sch, bela_cape_5.kicad_sch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]
2023-03-12 changed board setup to include Bela cape colors, added 3dmodels for button and LED
    (cherry picked from commit fac969fb978c1abdbab94b44e3f4f5c1f13dcd93)
    [bela_cape.kicad_pcb]
2023-03-12 added missing 3dmodels for IC packages
    (cherry picked from commit 85806714f40e67aeb9d357d275771518137d9dca)
    [bela_cape.kicad_pcb]
2023-03-12 Bela cape rev. C2
    (cherry picked from commit 085b3700cd1d9a25c77092a8b59a7c103f45927b)
    [bela_cape.kicad_pcb, bela_cape.kicad_sch, bela_cape_1.kicad_sch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]
2023-03-12 A few edits to C2 cape
    (cherry picked from commit 42570a0d57f5cd6d8ff56c36d77f2d0b211cc62f)
    [bela_cape.kicad_pcb, bela_cape.kicad_sch]
2023-03-12 added NC flags to pins in Cape rev C2 to reduce ERC errors
    (cherry picked from commit 3da46686a35f9c5723f0363d277e8b6402ee2362)
    [bela_cape.kicad_sch, bela_cape_2.kicad_sch, bela_cape_6.kicad_sch]
2023-03-12 Bodge board to fix an error on C2 capes
    (cherry picked from commit f68d599e191e370001d2d3aca018898c47946fe5)
    [analog_out_fix_c2.kicad_pcb, analog_out_fix_c2.kicad_sch]
2023-03-12 Added panel and gerbers for fix board
    (cherry picked from commit a0c660b927de1cd35729b3ca257c25d34b100ddd)
    [panel-B_Cu.gbr, panel-B_Mask.gbr, panel-B_Paste.gbr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]
2023-03-12 Changed panel to 6x7 with 3mm gap and 0.35mm distance to v-scoring.
    (cherry picked from commit ada2b1bb84732b3d844c1010702f27f798faad04)
    [panel-B_Cu.gbr, panel-B_Mask.gbr, panel-B_Paste.gbr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]
2023-03-12 Edit to C2 cape fix
    (cherry picked from commit b205a86061b78b52253ac275e5139adb0c372d47)
    [analog_out_fix_c2.kicad_pcb]
2023-03-12 Cape rev C3 first draft
    (cherry picked from commit 13e247bb11a8ca90d5cea0bc35d4eceea4ae0f39)
    [bela_cape.kicad_pcb, bela_cape.kicad_sch, bela_cape_1.kicad_sch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]
2023-03-12 Reduce size of connector holes on C3 cape
    (cherry picked from commit 2d14684a246b05362e5486009cff8026d4af1add)
    [bela_cape.kicad_pcb]
2023-03-12 Add analog out connection to P8.15 for future BBAI64 support
    [bela_cape.kicad_pcb, bela_cape.kicad_sch, bela_cape_2.kicad_sch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]
2024-02-27 removed sym-lib-table with a reference to an unused and obsolete local library
    [bela_cape.kicad_pcb, bela_cape.kicad_sch, bela_cape_2.kicad_sch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]
2024-02-27 added missing footprints and symbols, updated their use in the schematic, referenced them as local path in schematic and layout
    [bela_cape.kicad_pcb, bela_cape_2.kicad_sch, bela_cape_6.kicad_sch]
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2025-04-16 added audio I/O to belamini symbol/fp, made footprint DRC error-free
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

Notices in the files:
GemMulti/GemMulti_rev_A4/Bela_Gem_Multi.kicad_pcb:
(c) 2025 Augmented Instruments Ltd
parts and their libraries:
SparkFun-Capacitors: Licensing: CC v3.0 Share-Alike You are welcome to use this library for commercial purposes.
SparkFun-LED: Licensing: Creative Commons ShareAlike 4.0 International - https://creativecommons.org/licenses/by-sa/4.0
